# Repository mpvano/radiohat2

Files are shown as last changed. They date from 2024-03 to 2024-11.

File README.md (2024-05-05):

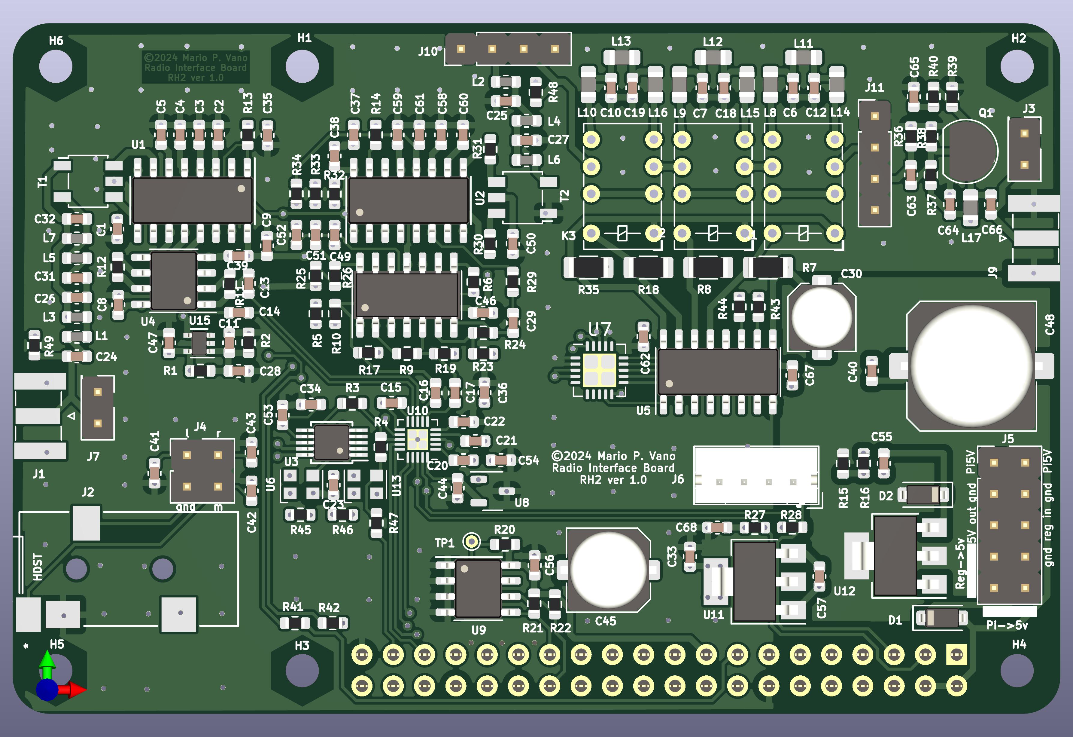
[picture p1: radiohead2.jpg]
3dView Title

# RadioHat 2

This is an early version of the folder full of files that need to be installed on a raspberry pi to allow experimentation with the RadioHat version 2.0 hardware.

When downloading and installing it, ensure that it is named "radiohat2" and that it is in your home directory, or some of the shell scripts it contains will not work properly. When downloaded as a .zip archive, it may result in a folder with the branch suffix "-main" that needs to be removed if you want to use the enclosed shell scripts.

One way to create the folder on a pi is to "cd" to the directory you want it to appear in and then clone the repository using git with the command: "git clone https://github.com/mpvano/radiohat2.git". This will allow you to use all the normal git functionality.

Note also that some of the files in "docs" are very out of date or incomplete. The "Getting Started Guides" refer to a much earlier configuration with different directories on the pi and procedures to set things up. They're presented here only to give some idea what to do. I'll be replacing them with more modern versions as I get to them. RadioHat is still very much a work in progress.

### The RadioHat hardware

Unlike RadioHat 1, RadioHat2 is an open source peripheral board for the Raspberry Pi in a form similar to an extended Pi "hat". Note that this board overhangs the pi USB and Ethernet connectors to match the dimensions of the Pi itself. This means it does not qualify as an official "HAT". It is intended to be a module containing many of the devices that are commonly needed to implement 3-30Mhz radio transmitters and receivers. It may also be used with other micro-controllers that support I2S if they are sufficiently powerful to handle the needed DSP operations.

It contains the following devices:<ol>
	<li>A Freescale SGTL5000 24 bit full duplex 48Khz I2S Audio codec with headset interface</li>
	<li>A Quadrature Switched Demodulator preceded by a 3-32Mhz Band Pass Filter</li>
	<li>A Quadrature Switched Modulator followed by a 32Mhz Low Pass Filter</li>
	<li>An Si5351 I2C controlled clock oscillator configured to provide quadrature clocks for them</li>
	<li>The EEPROM required by the Pi Foundation for "hat" devices</li>
	<li>Three relay controlled low pass filters intended for use after the Modulator to reduce harmonics before an external power amplifier.</li>
 	<li>A Class A Predriver to improve the Modulator drive capabilities and to compensate for filter losses.</li>
	<li>On board analog regulators to provide cleaner power from an optional external source</li>
</ol>

These devices are wired together in the usual way needed for HF radio operation with DSP provided by the Raspberry Pi. For typical operation as a radio transceiver you still need to provide a power amplifier with output filters and a transmit/receive switching mechanism. The usual output low pass filters are adequate for most uses as input filters for the receiver if the T/R switching is done in such a way that they remain inline with the receiver.

The repository now contains another board design of the same size in FAB/txfilters1 which implements a 5 filter LPF/VSWR Meter/TR Relay for stacking with the RadioHat board. Together with your choice of power amplifier this now allows a complete transceiver to be built easily.

Note that the real time clock option and Codec Line input output connection points that were present in Radiohat 1 have been removed. The Radiohat 1 board whose Kicad Folder is still in the repository remains software compatible with this board and although it is no longer under development it remains a viable option for those needing a true "hat" for the pi, or requiring a real time clock. 

There are two different Kicad folders available for RadioHat 2 - they differ primarily in that the one named "radiohat2_QFP32" is compatible with older 32 pin versions of the codec chip instead of the current 20 pin part. They will eventually be merged into a single version.

### Fabrication of boards
RadioHat2 is open sourced hardware licensed via an MIT license and the Gerber files, preliminary BOM and some draft documentation are all part of the project. 

Although a small production run was completed to provide a few boards for use by software developers, there is currently no way to obtain boards other than ordering them from a board manufacturer yourself - this is easy and inexpensive to do and the needed Gerber files are in this repository.

Note that this board is very compact and built with QFPn and 0603 components. It's not very practical to attempt assembly by hand. The board is intended to be reflow soldered after the components are placed on pads with the help of a front side solder paste screen.

### Software
The provided software is a collection of example and test programs that demonstrate operation of the board and allow testing and troubleshooting of it. They are only intended as a starting point for more serious software development. Experimental support is also provided for use with the popular "Quisk" Transceiver software as well.

This repository is newly setup and is still being tested. There may be some issues with missing files, etc. They are being addressed as quickly as possible.

### Dependencies
In general they are confined to the normal Raspberry Pi build tools, with the exception of ncurses and its development tools.

There is a simple installation described in the PDF file in the DOC folder.

Version 7 of Kicad or later is needed to modify the board design.

### Mailing list

There is a moderated mailing list for discussing this project at https://groups.io/g/RadioHat. This project's goal is develop radio equipment that requires a valid radio amateur operator's license to operate. Please include your valid station call sign in requests to join the list, and the nature of your interest in the project.

Mario Vano
AE0GL

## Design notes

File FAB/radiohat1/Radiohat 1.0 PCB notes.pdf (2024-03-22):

!.

$.
%.

!.

!.

$.

!.

Radiohat 1.0 PCB notes

ERRATA:
R23 and R24 references on Front Silk layer are swapped. F.Paste mask for U10 still has too much solder, especially center pad.
F.Paste mask for U3 still placing solder behind gull wings.
Need to add notes about unused pins on U10 (Remove from outline?)

BOM:
Y1 is now 25 MHz, not 27 MHz as shown on BOM and schematic Si5351 uses different variant with normal I2C address going forward

POSSIBLE ISSUES:
The front end gain may be too high again - Iʼm experiencing a little AM broadcast station bleed through. Consider going back to the 100 ohm input resistors on the receiver
For some uses, the narrow front end selectivity is a problem in adding a spectrum display. Consider some compromise values for the integrating capacitors and the op-amp bandwidth limiters in the receiver.
The 10 units built vary a bit more than they should in power output. I believe this is due to the component tolerances in the onboard low pass filter. The series resistance of the inductors seems to be a problem. Some of the them seem to have as much as 5 ohms series resistance and it all adds up.

SUGGESTIONS:
The Macom transformers no longer require the multifunction custom pad. It would be a good idea to go back to a standard pad layout and to remove them from the reflow assembly exclusion. Update manual with strong warnings - especially about J5, Y1 and U3 changes.

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
Always keep a shorting plug on J5 pins 1 and 2 when they are not actually being used to back-feed the Pi to prevent inadvertent shorts or use.
Renumber components?
Remove most of F.Silks references. Theyʼve become illegible Improve F.Fab layout for best readability and external Fab Zero grid and layout reference for Pick and Place
Clean up BOM for external Fab
Try moving 2.0V Analog Ref back to 2.5V if 3d order products allow it (R1)
Consider changing back to 20 pin U11 since 32 pin variant is now nearly unobtainable and the 20 pin one is back in stock in quantity. Better Yet: Switch to TLV320ADC3100IRGET!
THIS CHANGE MIGHT BE POSSIBLE WITH JUST A FOOTPRINT CHANGE.
Change to alternate S15351 suppliers and use part with standard base address.
Move R35 0 ohm jumper to Si5351 side to allow TP4 to be used as yellow wire point for modifications
Add some way to unbalance carrier to experiment with newer digital synthesis and other CW methods

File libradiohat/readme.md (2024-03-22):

# libradiohat - experimental version and tools #

## NEWS 1-Feb-2023 ##

Added experimental minimal Kenwood TS480 CAT control support to "transceiver.cpp" and new control-less GnuRadio USB conversion filter. Together with a SOCAT redirection command, ALSA loopback and Pulse Audio output capture this allows full proper operation of WSJT-X.

## NEWS 6-march-2022 ##

This directory has started to become a collecting point for a lot of new work. These files will eventually replace the legacy *RadioHat* installation completely. Many things in this folder are incompatible with older ways of doing things - in particular all programs now rely on the dynamic library and/or the new *transceiver* program.

Note also that everything looking for the codec now looks for it under a different ALSA device name! It is now known as *RadioHatCodec*. Programs still looking for *GenericStereoAudioCodec* or contractions of that name will need to be modified.

## introducing *libradiohat* ##

This is a refactored set of libraries for accessing the *RadioHat 1.0* hardware. It has many clean-ups and improvements and may now be built as a dynamic library.

This is primarily intended for use with *Bullseye*. It will also work on *Buster*, but other things may require fixup to go backwards!

This folder includes an improved and rewritten version of *pitrans*, called *transceiver* that uses the dynamic library for all *RadioHat* access.

There's  a primitive *make* file included that builds the library and test program targets but does not install the library. It has *install* and *remove* targets - which copy the library to */usr/lib/*, but they require using *sudo make install/remove* in a separate step.  For now, programs that use the library should still access it by absolute location to simplify development.

You'll also need to ensure that you've installed *libgpiod-dev* and *libncurses5-dev* before building. A *make clean* is probably also a good idea the first time.

Two other experimental programs are included that expect to find the libradiohat.so in *~/radiohat/libradiohat* for now.

Note that these programs probably will not work on *Buster* because the earlier version of Gnu Radio it supports is not file or program compatible with newer versions. The same is true of the *Quisk* it offers.

The earlier GRC programs in .~/radiohat should still be functional using *transceiver* instead of *pitrans* as they have not been disturbed by the new *GRC*. As usual ALSA device names may need touching up.

### Other Tools ###

In the *GRC* folder, *transceiver.grc / transceiver.py* is an experimental gnuradio flow graph that attempts to put all the things needed to experiment with and test *RadioHat* in one spot. It also includes some experimental PTT and VFO access from the flow graph. Unfortunately the ways needed to do this at the moment add a lot of overhead, and the program is unstable when run in the GRC environment. It seems to work OK by running the .py file, however. It also required Gnu Radio Version 3.8 or later.

Be aware, however, that the 1ms polling rate GRC uses for exporting variables as messages adds a lot of overhead and as a result this flow graph is occasional getting out of sync and losing alternate sideband rejection - usually if a lot of VFO tuning around is done at high speed. It's still fun and very useful for quick testing, but stick to the simpler flow graphs for serious measurements!

I'm also seeing a lot of crazy behaviour caused by *Pulse Audio* and the new *PipeWire* server. Neither one of them can be disabled any more and after a while they start distorting the IQ signals causing loss of functionality. Sometimes killing pulse audio (it will restart) will fix it - other times only a reboot will do it. Note that the "Bullseye" needs rebooting - not radiohat!  The new audio servers break Jack and prevent it's use with digital modes, as well.

### Experimental *quisk* interface ###

*QUISK* is a folder containg a hardware configuration file for Quisk. There are two copies present under different names. It's generally operating OK with the QUISK version in the Bullseye apt repository, but it's still very experimental. It almost certainly will not work under the version included with *Buster*. QUISK is very hard to configure and get working, but if you want to play with it, you may have some luck by moving the *radiohat* folder inside QUISK to the quisk configuration directory and setting quisk up as a radio of type "Softrock fixed" with one of these config files chosen.

All these programs are intended for use with the default Alsa device and I suggest using a usb plug-in dongle. This simplifies understanding them and eliminates problems with t/r switching the codec hardware audio paths. You can also use the built-in Pi headset sound or the HDMI sound for receiver and tone testing, since they both include dummy input devices.

We'll return to using the built-in headset jack and digital modes very soon, but for now these simplifications are speeding development a great deal and ensuring a solid foundation for the work to come.

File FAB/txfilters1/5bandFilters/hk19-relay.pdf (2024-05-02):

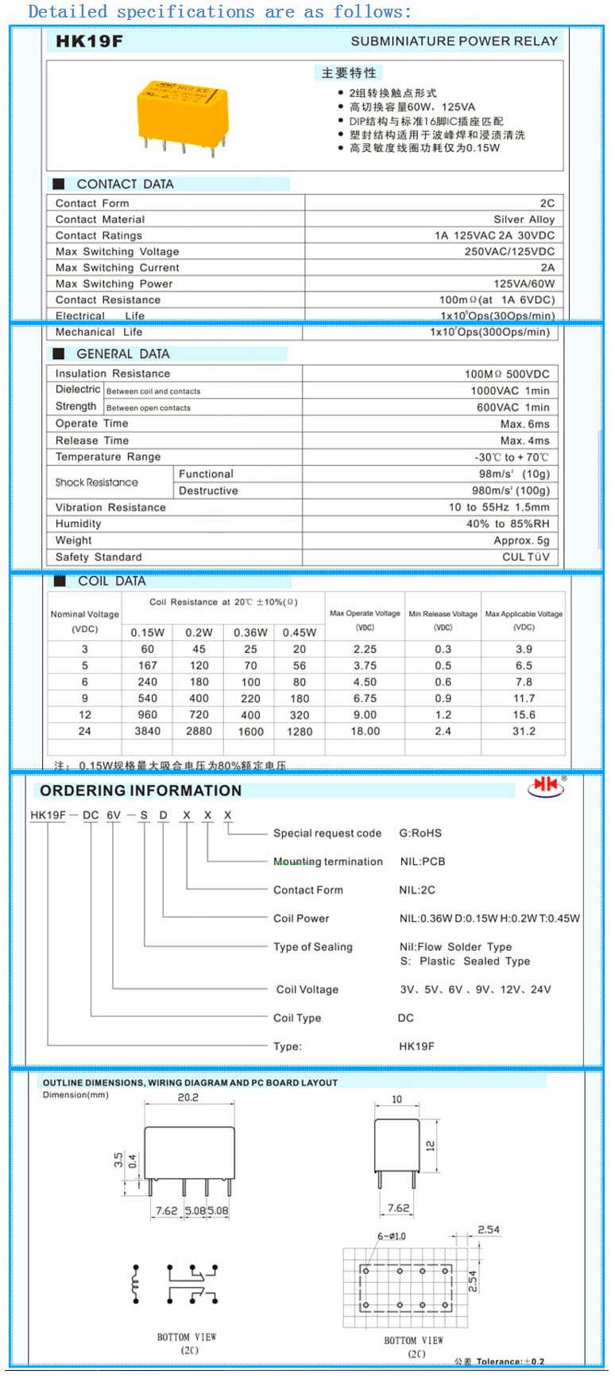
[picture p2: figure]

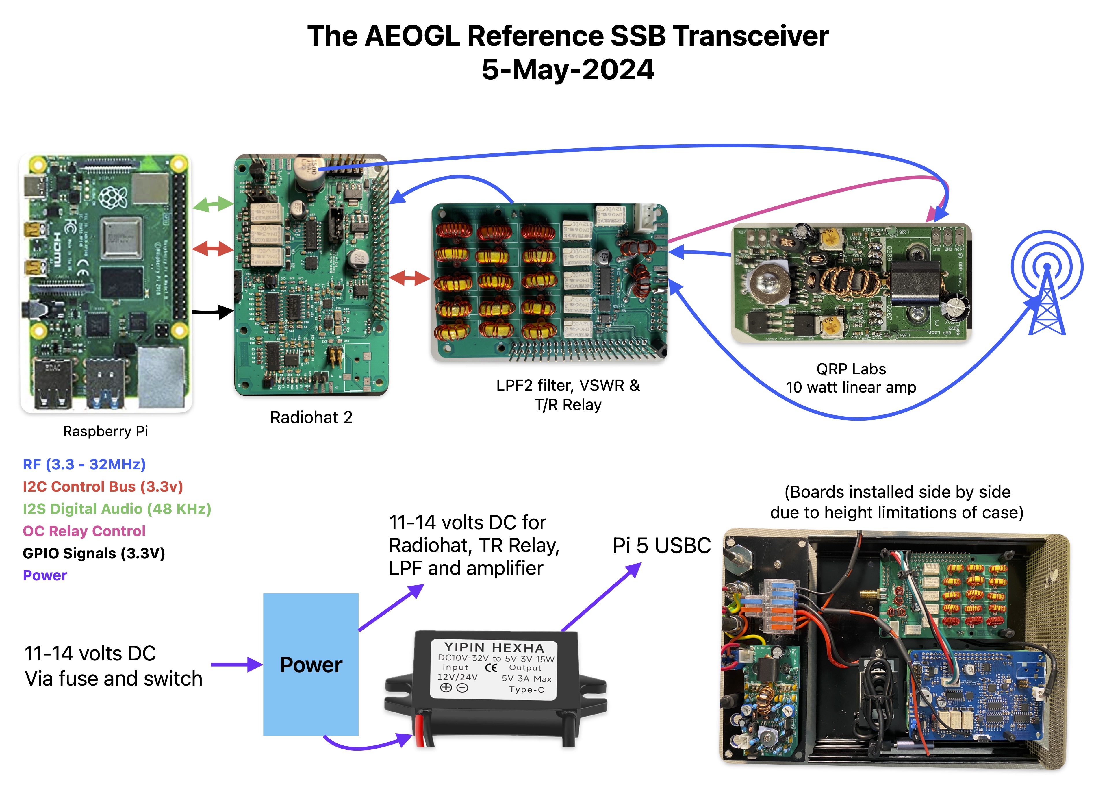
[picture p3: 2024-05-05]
Radiohat 2 Reference Transceiver.jpg

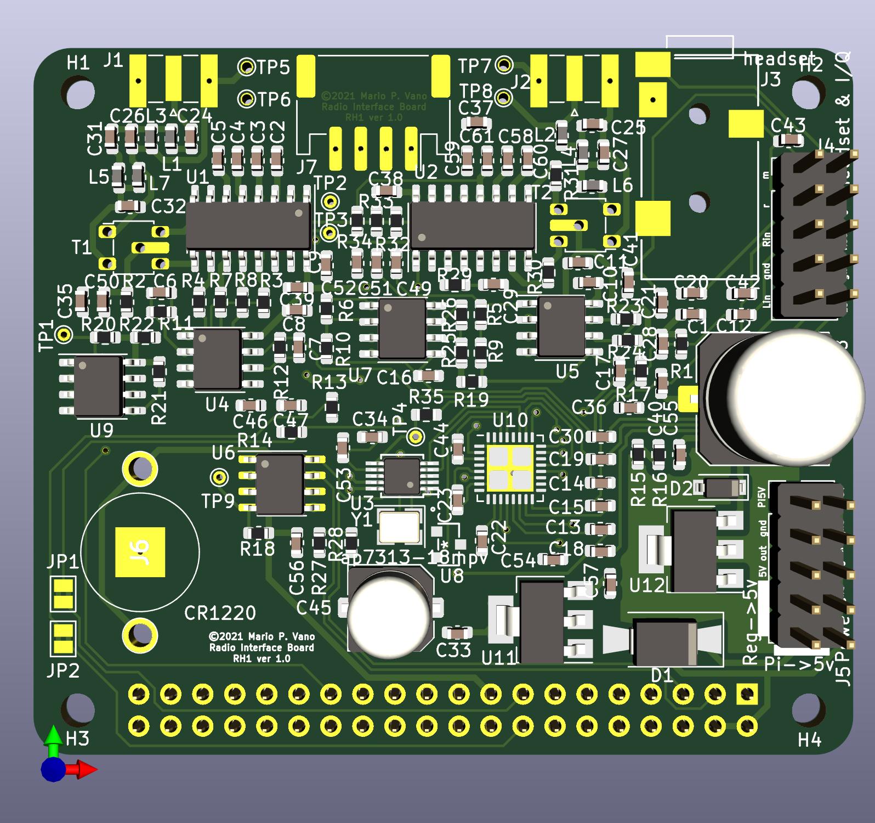
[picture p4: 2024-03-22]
FAB/radiohat1/radiohead3d.jpg

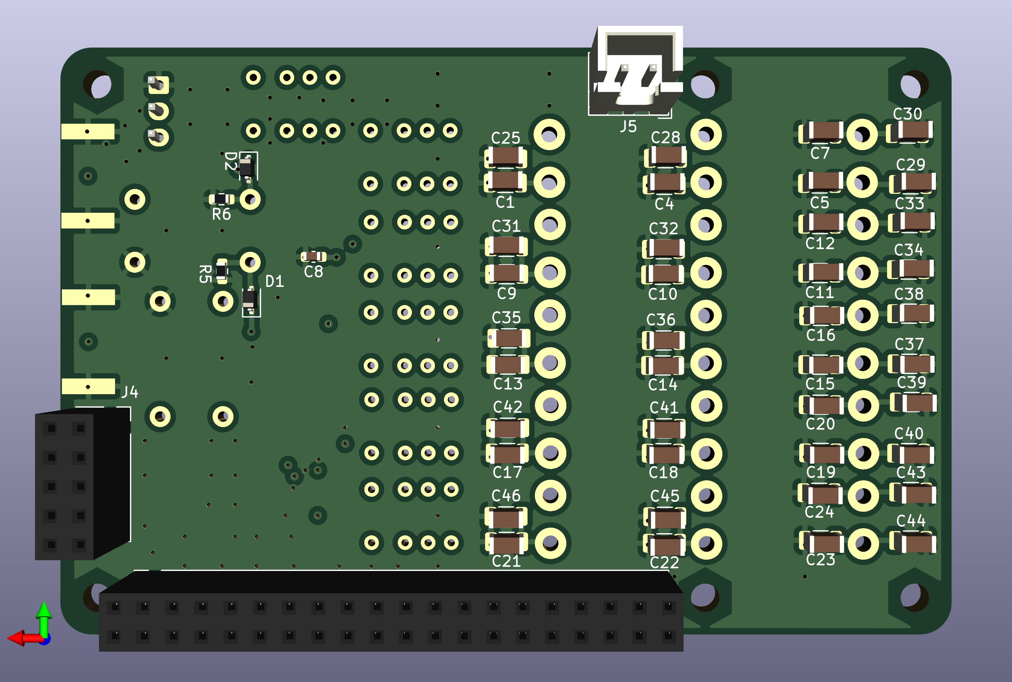
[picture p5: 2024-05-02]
FAB/txfilters1/txfilters3dB.jpg

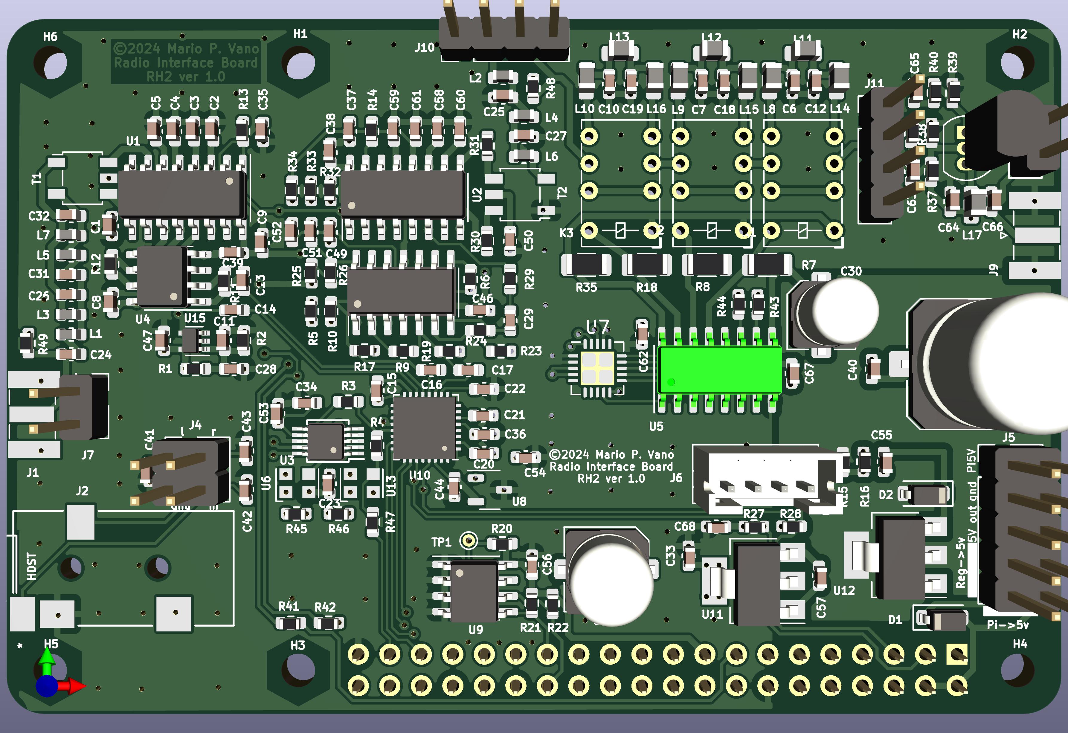
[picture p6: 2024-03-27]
FAB/radiohat2_QFP32/PCBA/radiohead.jpg

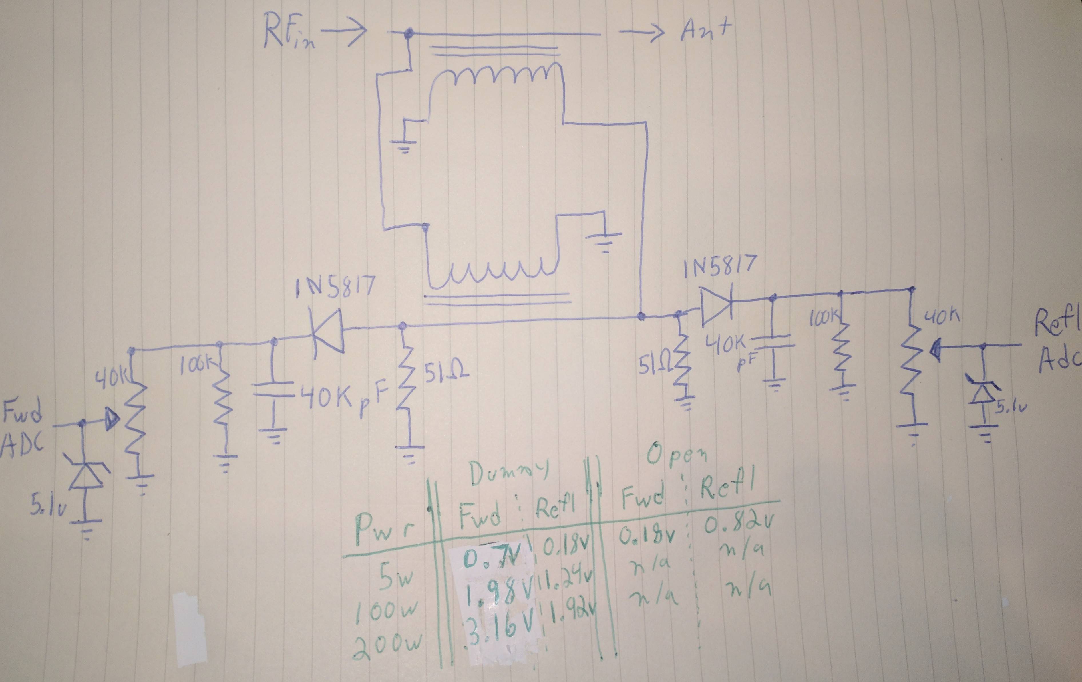
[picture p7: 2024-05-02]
FAB/txfilters1/datasheets/Stockton bridge/KCCug.jpg

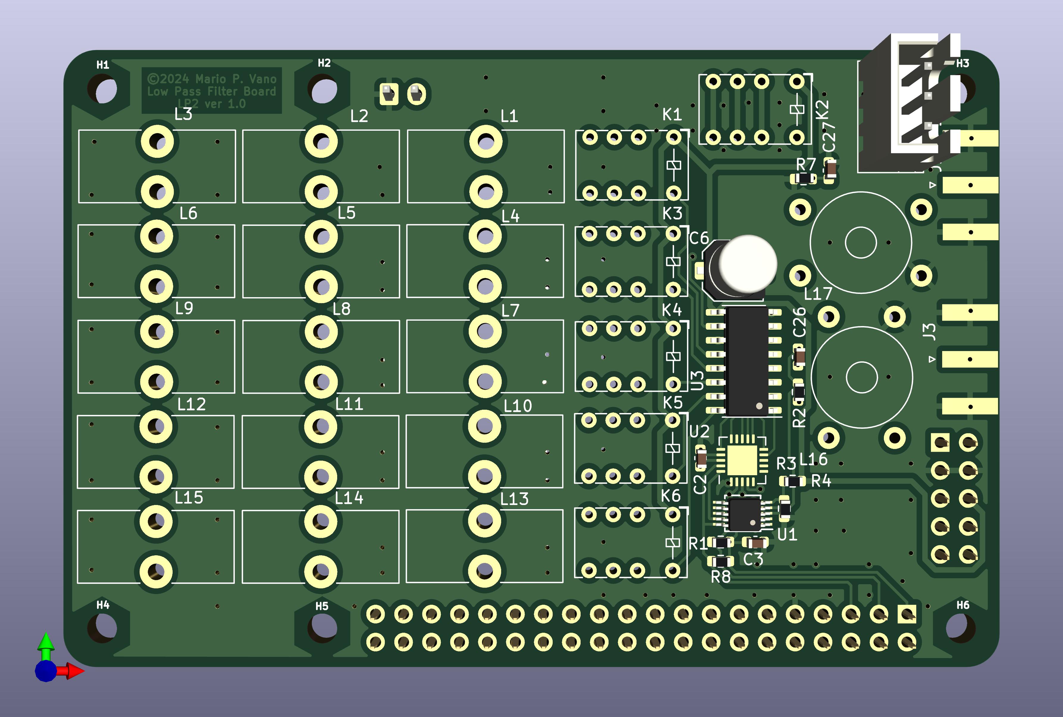
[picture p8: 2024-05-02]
FAB/txfilters1/txfilters3dF.jpg

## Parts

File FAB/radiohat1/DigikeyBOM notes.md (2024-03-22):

## Digikey RadioHat 1.0 BOM Notes ##
7-Mar-2022

### Disclaimer ###
This dump of my last BOM list on Digikey should be close to what is needed to build a *RadioHat 1.0* Board like the 10 I fabricated in January and Febuary 2022. You are responsible for carefully reviewing each item and locating it, or an equivalent part. I provide this only as an aid, not a definitive list! Due to the current parts shortages, it's very difficult to confirm what parts were actually bought here - they had to change with changing inventories.

Of course, you cannot simply place an order for this list. Many parts will not be available, others will have different minimum quantities. Some parts are simply no longer available and probably never will be from Digikey. It's only meant to be a starting point!

### Notes ###

1.	DigiKey's inventory record for C48 has an incorrect description for that part. It is incorrectly listed as *1.5µf* instead of *1.5mf* (for *millifarad*) or *1500µf*. The part number is correct and the correct part arrived. It's only the inventory record that is wrong. For decades, *mf* meant *microfarad*, but it no longer does.

2. The Top Silk Screen layer of the version 1.0 board has two swapped parts designators. R23 and R24's labels are reversed. The schematic, Fab layer screen and everything else are correct - only the silk screen (and 3D rendering of it) are incorrect.

3.	Some late changes in components to op-amp U4's feedback components resulted in too much gain and narrowing the bandwidth. The BOM still reflects the incorrect parts. I recommend reducing the feedback resistors R11 and R12 from 10k to 2.4k. This will allow an rf input level of about -16dbm before clipping occurs.

	Instead of adjusting the bandwidth to the old goal of approximately 8khz, most people seem to prefer operating this stage with less selectivity to allow spectrum display graphs of the full audio bandwidth (+-19khz or so before the ADC's filtering cuts in). Removing C6 and C7 completely seems to achieve this goal.

	With some very high performance op-amps, it may be desirable to prevent the bandwidth from exceeding this range, and if so values of 200pf can be used for C6 and C7. Some experimentation in this area is probably worthwhile.

	The QSD itself still has some deliberate roll-off due to the high values of capacitors used for C2, C3, C4, and C5. It has been suggested that values as low as .1µfd may be more appropriate, but I have not tried that substitution.

4.	Be cautious about the si5351 (U3). The original part I was using was all I could obtain and the part number shown in the original BOM, while correct, is for a part with custom programming to give it a *different I2C address*. All these parts were removed from boards and no more boards should be built using them so that the same software builds will work on everything! The *Digikey* BOM reflects the standard version of the part (but of course it's not available!) use the MS5351 instead.

5. The original *RadioHat* operated with a crystal frequency of 27Mhz. All current boards have had the crystal replaced with the one shown in the *Digikey* BOM (or another 25Mhz equivalent). No more 27Mhz boards should ever be built!

6. R35 is intended to be a zero ohm jumper. It turns out that's a hard value to obtain! The current parts list shows it as 1 ohm and that works fine (Or you can use a piece of wire).

7. J7, the JST PH-4 connector used for *STEMMA* compatibility is no longer available in the form used to build the first 10 boards. A compatible connector is available from Adafruit Industries and is stocked by many suppliers including DigiKey. That is what is shown in this BOM. It's only available in packages of 10 connectors at a time, however!

8. There are many variant GPIO connectors (J8). I recommend making sure the ones you buy have square pins, or you may have contact problems if you wish to connect the popular *dupont* female connectors with them. For some uses, taller connectors may be needed to clear the heat sinks on some cases (or just to isolate the board from heat).

9.	Due to costs and parts availability, I recommend building boards without the clock calendar chip at this time.

10. It has become very clear to me that boards should not be built with the SMA connectors unless they are going to be used! They are a nuisance in may cases due to their protruberance from the side of the board. Only install them if you plan to use them!

11. The eeprom (U9) is not actually required or used at this time. It is needed, and needs to be programmed if you intend to sell boards and call them "hats". There are other plug-and-play advantages it can provide, but these parts have become very difficult to find at this time and can be added later if needed!

12. There are obviously many replacements available for J4 and J5. Obtaining *brand-name* headers of this type can be very difficult and expensive. I suggest ensuring that the pins are of high quality, square, and long enough to provide low contact resistance - especially for J5 - which is used to carry power.

Mario Vano

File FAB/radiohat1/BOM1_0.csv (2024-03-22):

Reference | Quantity | Value | Footprint | Datasheet | Description | Height | Manufacturer_Name | Manufacturer_Part_Number | Mouser Part Number | Mouser Price/Stock
C1 C50 | 2 | 10n | Capacitor_SMD:C_0603_1608Metric | ~
C12 C13 C14 C15 C16 C17 C18 C19 C20 C21 C30 C44 | 12 | 1m | Capacitor_SMD:C_0603_1608Metric | ~
C8 C9 C10 C22 C23 C33 C34 C35 C36 C37 C38 C39 C46 C47 C54 C56 C57 | 17 | 100n | Capacitor_SMD:C_0603_1608Metric | ~
C25 C27 | 2 | 130p | Capacitor_SMD:C_0603_1608Metric | ~
C26 C32 | 2 | 180p | Capacitor_SMD:C_0603_1608Metric | ~
C11 C28 C40 C53 | 4 | 10m | Capacitor_SMD:C_0603_1608Metric | ~
C24 C31 | 2 | 620p | Capacitor_SMD:C_0603_1608Metric | ~
C41 C42 C43 | 3 | 1n | Capacitor_SMD:C_0603_1608Metric | ~
C45 | 1 | 100m | Capacitor_SMD:C_Elec_6.3x5.4 | ~
C48 | 1 | 1500m | Capacitor_SMD:C_Elec_10x10.2 | ~
C29 C49 C51 C52 | 4 | 10u | Capacitor_SMD:C_0603_1608Metric | ~
C2 C3 C4 C5 | 4 | 470n | Capacitor_SMD:C_0603_1608Metric | ~
C55 | 1 | 100n 25V | Capacitor_SMD:C_0603_1608Metric | ~
C58 C59 C60 C61 | 4 | 22n | Capacitor_SMD:C_0603_1608Metric | ~
C6 C7 | 2 | 4.7n | Capacitor_SMD:C_0603_1608Metric | ~
D1 | 1 | MBRA340T3G | radiohead:D_SMA-SMB_Universal_Handsoldering | https://www.onsemi.com/pub/Collateral/MBRA340T3-D.PDF
D2 | 1 | MBR0520LT | Diode_SMD:D_SOD-123 | http://www.onsemi.com/pub_link/Collateral/MBR0520LT1-D.PDF
H1 H2 H3 H4 | 4 | 2.5mm | MountingHole:MountingHole_2.7mm_M2.5 | ~
J1 | 1 | HF IN | Connector_Coaxial:SMA_Samtec_SMA-J-P-X-ST-EM1_EdgeMount | ~
J2 | 1 | HF OUT | Connector_Coaxial:SMA_Samtec_SMA-J-P-X-ST-EM1_EdgeMount | ~
J3 | 1 | headset | Connector_Audio:SJ-43514TS-SMT
J4 | 1 | Headset & I/Q | Connector_PinHeader_2.54mm:PinHeader_2x05_P2.54mm_Vertical | ~
J5 | 1 | Power | Connector_PinHeader_2.54mm:PinHeader_2x05_P2.54mm_Vertical | ~
J6 | 1 | CR1220 | 2895:2895 | https://www.mouser.com/datasheet/2/215/Keystone_Electronics_04082019_2895-1551354.pdf | Coin Cell Battery Holders CR1220 COIN CELL THM RETAINER | 2.95 | Keystone Electronics | 2895 | 534-2895 | https://www.mouser.co.uk/ProductDetail/Keystone-Electronics/2895/?qs=u16ybLDytRYxJrEfvGnUaA%3D%3D
J7 | 1 | I2C | Connector_JST:JST_PH_S4B-PH-SM4-TB_1x04-1MP_P2.00mm_Horizontal | ~
J8 | 1 | Raspberry Pi GPIO | Connector_PinSocket_2.54mm:PinSocket_2x20_P2.54mm_Vertical | ~
JP1 | 1 | /TX | Jumper:SolderJumper-2_P1.3mm_Bridged2Bar_Pad1.0x1.5mm | ~
JP2 | 1 | /RX | Jumper:SolderJumper-2_P1.3mm_Bridged2Bar_Pad1.0x1.5mm | ~
L1 L2 L5 L6 | 4 | 470n | Inductor_SMD:L_0603_1608Metric | ~
L3 L7 | 2 | 1µ5 | Inductor_SMD:L_0603_1608Metric | ~
L4 | 1 | 560n | Inductor_SMD:L_0603_1608Metric | ~
R1 | 1 | 300 | Resistor_SMD:R_0603_1608Metric | ~
R9 R10 R11 R12 R13 R14 R17 R18 R19 R23 R25 R27 R28 | 13 | 10k | Resistor_SMD:R_0603_1608Metric | ~
R15 | 1 | 333r | Resistor_SMD:R_0603_1608Metric | ~
R2 | 1 | 200 | Resistor_SMD:R_0603_1608Metric | ~
R16 R20 | 2 | 1k | Resistor_SMD:R_0603_1608Metric | ~
R21 R22 | 2 | 3k9 | Resistor_SMD:R_0603_1608Metric | ~
R24 R26 | 2 | 20k | Resistor_SMD:R_0603_1608Metric | ~
R3 R4 R7 R8 | 4 | 50 | Resistor_SMD:R_0603_1608Metric | ~
R29 R30 R31 R32 R33 R34 | 6 | 50R | Resistor_SMD:R_0603_1608Metric | ~
R35 | 1 | 0 | Resistor_SMD:R_0603_1608Metric | ~
R5 R6 | 2 | 30k | Resistor_SMD:R_0603_1608Metric | ~
T1 T2 | 2 | MABAES0031 | radiohead:Transformer_MACOM_MABAES00031CT-HYBRID | https://cdn.macom.com/datasheets/MABAES0060.pdf | Audio Transformers / Signal Transformers .3-200MHz IL 1.5dB Impedance Ratio 1:4 | 3.8 | MACOM | MABAES0031CT | 1464-MABAES0031-CT
TP1 | 1 | /Write | TestPoint:TestPoint_THTPad_D1.0mm_Drill0.5mm | ~
TP2 | 1 | I | TestPoint:TestPoint_THTPad_D1.0mm_Drill0.5mm | ~
TP3 | 1 | Q | TestPoint:TestPoint_THTPad_D1.0mm_Drill0.5mm | ~
TP4 | 1 | MCLK | TestPoint:TestPoint_THTPad_D1.0mm_Drill0.5mm | ~
TP5 | 1 | -in | TestPoint:TestPoint_THTPad_D1.0mm_Drill0.5mm | ~
TP6 | 1 | +in | TestPoint:TestPoint_THTPad_D1.0mm_Drill0.5mm | ~
TP7 | 1 | -out | TestPoint:TestPoint_THTPad_D1.0mm_Drill0.5mm | ~
TP8 | 1 | +out | TestPoint:TestPoint_THTPad_D1.0mm_Drill0.5mm | ~
TP9 | 1 | RESET | TestPoint:TestPoint_THTPad_D1.0mm_Drill0.5mm | ~
U10 | 1 | SGTL5000XNAA3 | Package_DFN_QFN:QFN-32-1EP_5x5mm_P0.5mm_EP3.7x3.7mm | https://www.nxp.com/docs/en/data-sheet/SGTL5000.pdf
U11 | 1 | LD1117S33TR_SOT223 | Package_TO_SOT_SMD:SOT-223-3_TabPin2 | http://www.st.com/st-web-ui/static/active/en/resource/technical/document/datasheet/CD00000544.pdf
U12 | 1 | LM317_SOT-223 | Package_TO_SOT_SMD:SOT-223-3_TabPin2 | http://www.ti.com/lit/ds/symlink/lm317.pdf
U1 U2 | 2 | SN74CBT3253 | Package_SO:SOIC-16_3.9x9.9mm_P1.27mm | http://www.ti.com/lit/gpn/sn74cbt3253
U3 | 1 | Si5351A-B-GT | Package_SO:MSOP-10_3x3mm_P0.5mm | https://www.silabs.com/documents/public/data-sheets/Si5351-B.pdf
U4 | 1 | LM4562 | Package_SO:SOIC-8_3.9x4.9mm_P1.27mm | http://www.ti.com/lit/ds/symlink/lm4562.pdf
U5 U7 | 2 | TLV2462CDR | Package_SO:SOIC-8_3.9x4.9mm_P1.27mm | http://www.ti.com/lit/ds/symlink/lm358.pdf
U6 | 1 | DS3231MZ | Package_SO:SOIC-8_3.9x4.9mm_P1.27mm | http://datasheets.maximintegrated.com/en/ds/DS3231M.pdf
U8 | 1 | ap7313-18mpv | ul_AP731318SAG7:AP7313-18SAG-7
U9 | 1 | CAT24C128 | Package_SO:SOIC-8_3.9x4.9mm_P1.27mm | https://www.onsemi.com/pub/Collateral/CAT24C128-D.PDF
Y1 | 1 | 27Mhz | Crystal:Crystal_SMD_Abracon_ABM8G-4Pin_3.2x2.5mm | ~

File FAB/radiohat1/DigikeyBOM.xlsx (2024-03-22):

Country of Origin may be different at time of shipment.
The HTSUS and ECCN information shown is for informational purposes only and is not a representation or warranty as to the accuracy or reliability of these classifications. All information is provided "as is" and is subject to change without notice. Any use made of the information provided is without recourse to Digi-Key and at the user's risk.
Index | Manufacturer Part Number | Manufacturer Name | Description | Availability | Stock Status | Attrition % | Requested Quantity 1 | Pack Quantity 1 | Pack Type 1 | Digi-Key Part Number 1 | Unit Price 1 | Extended Price 1 | Minimum Order Quantity 1 | Customer Reference | Requested Part Number | Lead Weeks | Datasheet | Reference Designator | US Import Tariff | Note | Part Status | RoHS Status | ECCN | HTSUS | Country of Origin | Environmental Information | Original Part numbers | Image
1 | C0603C103K9RAC7867 | KEMET | CAP CER 10000PF 6.3V X7R 0603 | 56,312 | In Stock |  | 2 | 2 | Cut Tape (CT) | 399-C0603C103K9RAC7867CT-ND | 0.12000 | $0.24 | 1 |  | 399-C0603C103K9RAC7867CT-ND | 15 | https://api.kemet.com/component-edge/download/datasheet/C0603C103K9RACTU.pdf | C1 C50 | May apply on shipments to the U.S. | CAP CER 10000PF 6.3V | Active | ROHS3 Compliant | EAR99 | 8532.24.0020 | Taiwan |  | 399-C0603C103K9RAC7867CT-ND | //media.digikey.com/Renders/Kemet%20Renders/0603-(1608-Metric)-1,60x0,80x0,87mm.jpg
2 | CGB3B3X7R0J105K055AB | TDK Corporation | CAP CER 1UF 6.3V X7R 0603 | 11,634 | In Stock |  | 12 | 12 | Cut Tape (CT) | 445-13246-1-ND | 0.12400 | $1.49 | 1 |  | 445-13246-1-ND | 28 |  | C12 C13 C14 C15 C16 C17 C18 C19 C20 C21 C30 C44 | N/A | CAP CER 1UF 6.3V X7R 0603 | Not For New Designs | ROHS3 Compliant | EAR99 | 8532.24.0020 | Japan | https://product.tdk.com/en/environment/index.html|https://product.tdk.com/system/files/dam/doc/product/capacitor/ceramic/mlcc/rohs/mlccrohs_commercial_lowprofile_en.pdf | 445-13246-1-ND | //media.digikey.com/Renders/TDK%20Renders/CGB%20Series%200603.jpg
3 | C0603C104K4RAC7867 | KEMET | CAP CER 0.1UF 16V X7R 0603 | 5,975,227 | In Stock |  | 17 | 17 | Cut Tape (CT) | 399-C0603C104K4RAC7867CT-ND | 0.07900 | $1.34 | 1 |  | 399-C0603C104K4RAC7867CT-ND | 15 | https://api.kemet.com/component-edge/download/datasheet/C0603C104K4RACTU.pdf | C8 C9 C10 C22 C23 C33 C34 C35 C36 C37 C38 C39 C46 C47 C54 C56 C57 | May apply on shipments to the U.S. |  | Active | ROHS3 Compliant | EAR99 | 8532.24.0020 | Taiwan |  | 399-C0603C104K4RAC7867CT-ND | //media.digikey.com/Renders/Kemet%20Renders/0603-(1608-Metric)-1,60x0,80x0,87mm.jpg
4 | 0603N131J500CT | Walsin Technology Corporation | CAP CER 130PF 50V C0G/NP0 0603 | 5,053 | In Stock |  | 2 | 2 | Cut Tape (CT) | 1292-1484-1-ND | 0.10000 | $0.20 | 1 |  | 1292-1484-1-ND | 32 | http://www.passivecomponent.com/wp-content/uploads/datasheet/WTC_MLCC_General_Purpose.pdf | C25 C27 | N/A | CAP CER 130PF 50V C0G/NP0 0603 | Active | ROHS3 Compliant | EAR99 | 8532.24.0020 | Taiwan | http://www.passivecomponent.com/download/reach_rohs_compliance_declaration-2/?wpdmdl=1343 | 1292-1484-1-ND | //media.digikey.com/Renders/Walsin%20Tech/MLCC-0603;;1,6x0,8x0,85.JPG
5 | VJ0603D181JXJQJHT | Vishay Vitramon | CAP CER 180 PF 16V C0G 0603 | 1,800 | In Stock |  | 2 | 2 | Cut Tape (CT) | 720-VJ0603D181JXJQJHTCT-ND | 0.46000 | $0.92 | 1 |  | 720-VJ0603D181JXJQJHTCT-ND | 39 | https://www.vishay.com/docs/45239/vjhifreqht.pdf | C26 C32 | N/A | CAP CER 180PF 16V | Active | ROHS3 Compliant | EAR99 | 8532.24.0020 | Israel |  | 720-VJ0603D181JXJQJHTCT-ND | //media.digikey.com/Photos/Vishay%20Vitramon/MLCC-0603.jpg
6 | CL10A106KQ8NNNC | Samsung Electro-Mechanics | CAP CER 10UF 6.3V X5R 0603 | 0 | Normally Stocking |  | 8 | 8 | Cut Tape (CT) | 1276-1038-1-ND | 0.14000 | $1.12 | 1 |  | 1276-1038-1-ND | 28 | //media.digikey.com/pdf/Data%20Sheets/Samsung%20PDFs/CL10A106KQ8NNNC_Spec.pdf | C11 C28 C40 C53 C29 C49 C51 C52 | N/A | CAP CER 10UF 6.3V X5R 0603 | Active | ROHS3 Compliant | EAR99 | 8532.24.0020 | China | https://www.samsungsem.com/global/support/certificate/product-stewardship.do|https://www.samsungsem.com/files/fileDown.do?key=ed1dfdfa-645e-4252-b707-17f9b1502dd1 | 1276-1038-1-ND | //media.digikey.com/Renders/Samsung%20Electro-Mechanics%20America/Ceramic-Capacitor-CL-Series.jpg
7 | 0603N621J500CT | Walsin Technology Corporation | CAP CER 620PF 50V C0G/NP0 0603 | 2,755 | In Stock |  | 2 | 2 | Cut Tape (CT) | 1292-1540-1-ND | 0.11000 | $0.22 | 1 |  | 1292-1540-1-ND | 32 | http://www.passivecomponent.com/wp-content/uploads/datasheet/WTC_MLCC_General_Purpose.pdf | C24 C31 | May apply on shipments to the U.S. | CAP CER 620PF 50V C0G/NP0 0603 | Active | ROHS3 Compliant | EAR99 | 8532.24.0020 | Taiwan | http://www.passivecomponent.com/download/reach_rohs_compliance_declaration-2/?wpdmdl=1343 | 1292-1540-1-ND | //media.digikey.com/Renders/Walsin%20Tech/MLCC-0603;;1,6x0,8x0,85.JPG
8 | 0603B102K500CT | Walsin Technology Corporation | CAP CER 1000PF 50V X7R 0603 | 2,236,155 | In Stock |  | 3 | 3 | Cut Tape (CT) | 1292-1380-1-ND | 0.10000 | $0.30 | 1 |  | 1292-1380-1-ND | 48 | http://www.passivecomponent.com/wp-content/uploads/datasheet/WTC_MLCC_General_Purpose.pdf | C41 C42 C43 | N/A |  | Active | ROHS3 Compliant | EAR99 | 8532.24.0020 | Taiwan | http://www.passivecomponent.com/download/reach_rohs_compliance_declaration-2/?wpdmdl=1343 | 1292-1380-1-ND | //media.digikey.com/Renders/Walsin%20Tech/MLCC-0603;;1,6x0,8x0,85.JPG
9 | 10SEV100M6.3X5.5 | Rubycon | CAP ALUM 100UF 20% 10V SMD | 0 | Normally Stocking |  | 1 | 1 | Cut Tape (CT) | 1189-2934-1-ND | 0.51000 | $0.51 | 1 |  | 1189-2934-1-ND | 25 | https://www.rubycon.co.jp/wp-content/uploads/catalog-aluminum/SEV.pdf | C45 | N/A | CAP ALUM 100UF 20% 10V SMD | Active | ROHS3 Compliant | EAR99 | 8532.22.0020 | Japan |  | 1189-2934-1-ND | //media.digikey.com/Photos/Rubycon/SEV%20SERIES%206.3x5.5mm.JPG
10 | EEE-FN0J152P | Panasonic Electronic Components | CAP ALUM 1.5UF 20% 6.3V SMD | 0 | Normally Stocking |  | 1 | 1 | Cut Tape (CT) | 10-EEE-FN0J152PCT-ND | 1.02000 | $1.02 | 1 |  | 10-EEE-FN0J152PCT-ND | 50 | https://b2b-api.panasonic.eu/file_stream/pids/fileversion/9127 | C48 | N/A | CAP ALUM 1.5UF 20% 6.3V SMD | Active | ROHS3 Compliant | EAR99 | 8532.22.0020 | Malaysia |  | 10-EEE-FN0J152PCT-ND | //media.digikey.com/Photos/Panasonic%20Elect%20Works%20Photos/MFG_EEE-FN-Series.jpg
11 | C0603C474K8RAC7867 | KEMET | CAP CER 0.47UF 10V X7R 0603 | 32,047 | In Stock |  | 4 | 4 | Cut Tape (CT) | 399-C0603C474K8RAC7867CT-ND | 0.50000 | $2.00 | 1 |  | 399-C0603C474K8RAC7867CT-ND | 53 | https://api.kemet.com/component-edge/download/datasheet/C0603C474K8RACTU.pdf | C2 C3 C4 C5 | N/A | CAP CER 0.47µf 10V | Active | ROHS3 Compliant | EAR99 | 8532.24.0020 | Mexico |  | 399-C0603C474K8RAC7867CT-ND | //media.digikey.com/Renders/Kemet%20Renders/0603-(1608-Metric)-1,60x0,80x0,87mm.jpg
12 | C0603C104K3RAC7082 | KEMET | CAP CER 0.1UF 25V X7R 0603 | 27,665 | In Stock |  | 1 | 1 | Cut Tape (CT) | 399-C0603C104K3RAC7082CT-ND | 0.11000 | $0.11 | 1 |  | 399-C0603C104K3RAC7082CT-ND | 15 | https://api.kemet.com/component-edge/download/datasheet/C0603C104K3RAC7082.pdf | C55 | May apply on shipments to the U.S. | CAP CER 0.1UF 25V X7R 0603 | Active | ROHS3 Compliant | EAR99 | 8532.24.0020 | Taiwan |  | 399-C0603C104K3RAC7082CT-ND | //media.digikey.com/Renders/Kemet%20Renders/0603-(1608-Metric)-1,60x0,80x0,87mm.jpg
13 | C0603C224K9RAC7867 | KEMET | CAP CER 0.22UF 6.3V X7R 0603 | 34,130 | In Stock |  | 4 | 4 | Cut Tape (CT) | 399-C0603C224K9RAC7867CT-ND | 0.10000 | $0.40 | 1 |  | 399-C0603C224K9RAC7867CT-ND | 15 | https://api.kemet.com/component-edge/download/datasheet/C0603C224K9RACTU.pdf | C58 C59 C60 C61 | May apply on shipments to the U.S. | CAP CER 0.22µf 6.3V | Active | ROHS3 Compliant | EAR99 | 8532.24.0020 | China |  | 399-C0603C224K9RAC7867CT-ND | //media.digikey.com/Renders/Kemet%20Renders/0603-(1608-Metric)-1,60x0,80x0,87mm.jpg
14 | 0603B472K500CT | Walsin Technology Corporation | CAP CER 4700PF 50V X7R 0603 | 303,759 | In Stock |  | 2 | 2 | Cut Tape (CT) | 1292-1443-1-ND | 0.10000 | $0.20 | 1 |  | 1292-1443-1-ND | 32 | http://www.passivecomponent.com/wp-content/uploads/datasheet/WTC_MLCC_General_Purpose.pdf | C6 C7 | May apply on shipments to the U.S. | CAP CER 4700PF 50V X7R 0603 | Active | ROHS3 Compliant | EAR99 | 8532.24.0020 | Taiwan | http://www.passivecomponent.com/download/reach_rohs_compliance_declaration-2/?wpdmdl=1343 | 1292-1443-1-ND | //media.digikey.com/Renders/Walsin%20Tech/MLCC-0603;;1,6x0,8x0,85.JPG
15 | CDBA340-HF | Comchip Technology | DIODE SCHOTTKY 40V 3A DO214AC | 127 | In Stock |  | 1 | 1 | Cut Tape (CT) | 641-1748-1-ND | 0.37000 | $0.37 | 1 |  | 641-1748-1-ND | 32 | //media.digikey.com/pdf/Data%20Sheets/Comchip%20PDFs/CDBA340-HF_Thru_CDBA3100-HF_RevB.pdf | D1 | N/A | DIODE SCHOTTKY 40V 3A DO214AC | Active | ROHS3 Compliant | EAR99 | 8541.10.0080 | Taiwan | https://www.comchiptech.com/admin/files/tech/213_20201006093628.pdf | 641-1748-1-ND | //media.digikey.com/photos/Comchip%20Tech%20Photos/641-DO-214AC.jpg
16 | MBR0520L-TP | Micro Commercial Co | DIODE SCHOTTKY 20V 500MA SOD123 | 137,167 | In Stock |  | 1 | 1 | Cut Tape (CT) | MBR0520L-TPMSCT-ND | 0.52000 | $0.52 | 1 |  | MBR0520L-TPMSCT-ND | 36 | https://www.mccsemi.com/pdf/Products/MBR0520L-MBR0540L(SOD-123).pdf | D2 | May apply on shipments to the U.S. | DIODE SCHOTTKY 20V 500MA SOD123 | Active | ROHS3 Compliant | EAR99 | 8541.10.0070 | China | https://www.mccsemi.com/pdf/pbfree/Certification%20of%20RoHS%20Compliance.pdf|https://www.mccsemi.com/pdf/pbfree/Certification%20of%20Compliance%20of%20CaliforniaProposition65.pdf|https://www.mccsemi.com/pdf/pbfree/Certification%20of%20REACH%20Compliance.pdf | MBR0520L-TPMSCT-ND | //media.digikey.com/Renders/Micro%20Commercial%20Renders/SOD-123.jpg
17 | SJ-43514-SMT-TR | CUI Devices | CONN JACK 4COND 3.5MM SMD R/A | 84,832 | In Stock |  | 1 | 1 | Cut Tape (CT) | CP-43514SJCT-ND | 1.20000 | $1.20 | 1 |  | CP-43514SJCT-ND | 14 | https://www.cuidevices.com/product/resource/sj-4351x-smt.pdf | J3 | May apply on shipments to the U.S. | CONN JACK 4COND 3.5MM SMD R/A | Active | ROHS3 Compliant | EAR99 | 8536.69.4040 | Hong Kong | https://www.cuidevices.com/product/resource/material-compliance/sj-4351x-smt-series | CP-43514SJCT-ND | //media.digikey.com/photos/CUI%20Photos/SJ-43514-SMT%20.jpg
18 | 61301021121 | Würth Elektronik | CONN HEADER VERT 10POS 2.54MM | 5,452 | In Stock |  | 2 | 2 | Bag | 732-2672-ND | 1.08000 | $2.16 | 1 |  | 732-2672-ND | 23 | https://www.we-online.com/katalog/datasheet/6130xx21121.pdf | J4 J5 | N/A | CONN HEADER VERT 10POS 2.54MM | Active | ROHS3 Compliant | EAR99 | 8536.69.4040 | Taiwan | https://media.digikey.com/pdf/Other%20Related%20Documents/Wurth/Certificate_of_Compliance_ROHS.pdf | 732-2672-ND | //media.digikey.com/Photos/Wurth%20Electronics%20Photos/61301021121.jpg
19 | 2895 | Keystone Electronics | BATT RETAIN COIN 1 CELL PC PIN | 17,088 | In Stock |  | 1 | 1 | Bulk | 36-2895-ND | 0.66000 | $0.66 | 1 |  | 36-2895-ND | 12 | http://www.keystoneelectronics.net/ENG._DEPT/WEB_ORACLE/PDF/PDF%20CAT%20NO%20DRAWINGS/2000-2999/2895.PDF | J6 | May apply on shipments to the U.S. | BATT RETAIN COIN 1 CELL PC PIN | Active | ROHS3 Compliant | EAR99 | 8536.69.4040 | China | https://www.keyelco.com/userAssets/file/reach.pdf|http://www.keyelco.com/userAssets/file/RoHS_Statement.pdf | 36-2895-ND | //media.digikey.com/Photos/Keystone%20Elect%20Photos/2895.jpg
20 | 4392 | Adafruit Industries LLC | JST PH 4-PIN CONN 10-PACK STEMMA |  | Non-Stock |  | 1 | 1 | Bulk | 1528-4392-ND | 3.50000 | $3.50 | 1 |  | 1528-4392-ND | 2 | https://cdn-shop.adafruit.com/product-files/4392/4392_C13927-001_CW2001-04T-H01-BD-A.PDF | J7 | N/A | JST PH4 4-PIN CONN STEMMA ONLY IN 10 PACK! | Active | ROHS3 Compliant | EAR99 | 8536.69.4040 | China |  | 1528-4392-ND
21 | 2223 | Adafruit Industries LLC | STACKING HEADER 40PIN | 1,513 | In Stock |  | 1 | 1 | Bulk | 1528-1385-ND | 2.50000 | $2.50 | 1 |  | 1528-1385-ND | 2 | https://cdn-shop.adafruit.com/product-files/2223/18507.pdf | J8 | N/A |  | Active | ROHS3 Compliant | EAR99 | 8536.69.4040 | China |  | 1528-1385-ND | //media.digikey.com/Photos/Adafruit%20Industries%20LLC/2223.jpg
22 | CS160808-R47K | Bourns Inc. | FIXED IND 470NH 150MA 700MOHM SM | 13,046 | In Stock |  | 4 | 4 | Cut Tape (CT) | CS160808-R47KCT-ND | 0.14000 | $0.56 | 1 |  | CS160808-R47KCT-ND | 28 | https://www.bourns.com/docs/Product-Datasheets/CS160808.pdf | L1 L2 L5 L6 | May apply on shipments to the U.S. | FIXED IND 470NH 150MA 700MOHM SM | Active | ROHS3 Compliant | EAR99 | 8504.50.8000 | China | https://www.bourns.com/docs/rohs-content/bourns-reach-letter.pdf |https://www.bourns.com/docs/rohs-cofc/cofc_cm3.pdf?sfvrsn=57869782_2 | CS160808-R47KCT-ND | //media.digikey.com/Photos/Bourns%20Photos/MFG_CS160808-SERIES.jpg
23 | MLF1608A1R5JTD25 | TDK Corporation | FIXED IND 1.5UH 50MA 700MOHM SMD | 804 | In Stock |  | 2 | 2 | Cut Tape (CT) | 445-16919-1-ND | 0.31000 | $0.62 | 1 |  | 445-16919-1-ND | 10 |  | L3 L7 | N/A | FIXED IND 1.5UH 50MA 700MOHM SMD | Active | ROHS3 Compliant | EAR99 | 8504.50.8000 | Japan | https://product.tdk.com/en/environment/index.html | 445-16919-1-ND | //media.digikey.com/Renders/TDK%20Renders/0603%20(1608%20Metric).jpg
24 | CS160808-R56K | Bourns Inc. | FIXED IND 560NH 150MA 900MOHM SM | 7,300 | In Stock |  | 1 | 1 | Cut Tape (CT) | CS160808-R56KCT-ND | 0.14000 | $0.14 | 1 |  | CS160808-R56KCT-ND | 28 | https://www.bourns.com/docs/Product-Datasheets/CS160808.pdf | L4 | May apply on shipments to the U.S. | FIXED IND 560NH 150MA 900MOHM SM | Active | ROHS3 Compliant | EAR99 | 8504.50.8000 | China | https://www.bourns.com/docs/rohs-content/bourns-reach-letter.pdf |https://www.bourns.com/docs/rohs-cofc/cofc_cm3.pdf?sfvrsn=57869782_2 | CS160808-R56KCT-ND | //media.digikey.com/Photos/Bourns%20Photos/MFG_CS160808-SERIES.jpg
25 | CRCW0603300RFKEA | Vishay Dale | RES SMD 300 OHM 1% 1/10W 0603 | 0 | Normally Stocking |  | 1 | 1 | Cut Tape (CT) | 541-300HCT-ND | 0.10000 | $0.10 | 1 |  | 541-300HCT-ND | 99 | https://www.vishay.com/docs/20035/dcrcwe3.pdf | R1 | N/A |  | Active | ROHS3 Compliant | EAR99 | 8533.21.0030 | Israel |  | 541-300HCT-ND | //media.digikey.com/Renders/Vishay%20Dale%20Renders/CRCW%200603%20%281608metric%29.jpg
26 | CR0603-FX-1002ELF | Bourns Inc. | RES SMD 10K OHM 1% 1/10W 0603 | 0 | Normally Stocking |  | 13 | 13 | Cut Tape (CT) | CR0603-FX-1002ELFCT-ND | 0.01700 | $0.22 | 1 |  | CR0603-FX-1002ELFCT-ND | 17 | https://www.bourns.com/docs/product-datasheets/cr.pdf?sfvrsn=574d41f6_14 | R9 R10 R11 R12 R13 R14 R17 R18 R19 R23 R25 R27 R28 | N/A | RES SMD 10K OHM 1% 1/10W 0603 | Active | ROHS3 Compliant | EAR99 | 8533.21.0030 | Taiwan | https://www.bourns.com/docs/Product-MDS/cr0603_mds.pdf|https://www.bourns.com/docs/rohs-cofc/crx_coc.pdf?sfvrsn=db3a74f6_10|https://www.bourns.com/docs/rohs-content/bourns-reach-letter.pdf | CR0603-FX-1002ELFCT-ND | //media.digikey.com/Renders/Bourns%20Renders/CR0603-(1608-Metric).jpg
27 | CRCW0603330RFKEB | Vishay Dale | RES SMD 330 OHM 1% 1/10W 0603 | 9,821 | In Stock |  | 1 | 1 | Cut Tape (CT) | 541-CRCW0603330RFKEBCT-ND | 0.10000 | $0.10 | 1 |  | 541-CRCW0603330RFKEBCT-ND | 99 | https://www.vishay.com/docs/20035/dcrcwe3.pdf | R15 | N/A |  | Active | ROHS3 Compliant | EAR99 | 8533.21.0030 | Israel |  | 541-CRCW0603330RFKEBCT-ND | //media.digikey.com/Renders/Vishay%20Dale%20Renders/CRCW%200603%20%281608metric%29.jpg
28 | CRCW0603200RFKTA | Vishay Dale | RES SMD 200 OHM 1% 1/10W 0603 | 0 | Normally Stocking |  | 1 | 1 | Cut Tape (CT) | 541-CRCW0603200RFKTACT-ND | 0.15000 | $0.15 | 1 |  | 541-CRCW0603200RFKTACT-ND | 99 | https://www.vishay.com/docs/20008/dcrcw.pdf | R2 | N/A | RES SMD 200 OHM 1% 1/10W 0603 | Active | RoHS non-compliant | EAR99 | 8533.21.0030 | Israel |  | 541-CRCW0603200RFKTACT-ND | //media.digikey.com/Renders/Vishay%20Dale%20Renders/CRCW%200603%20%281608metric%29.jpg
29 | CRCW06031K00FKEC | Vishay Dale | RES SMD 1K OHM 1% 1/10W 0603 | 0 | Normally Stocking |  | 2 | 2 | Cut Tape (CT) | 541-2986-1-ND | 0.10000 | $0.20 | 1 |  | 541-2986-1-ND | 99 | https://www.vishay.com/docs/20035/dcrcwe3.pdf | R16 R20 | N/A | RES SMD 1K OHM 1% 1/10W 0603 | Active | ROHS3 Compliant | EAR99 | 8533.21.0030 | Israel |  | 541-2986-1-ND | //media.digikey.com/Renders/Vishay%20Dale%20Renders/CRCW%200603%20%281608metric%29.jpg
30 | CRCW06033K90FKEA | Vishay Dale | RES SMD 3.9K OHM 1% 1/10W 0603 | 0 | Normally Stocking |  | 2 | 2 | Cut Tape (CT) | 541-3.90KHCT-ND | 0.10000 | $0.20 | 1 |  | 541-3.90KHCT-ND | 99 | https://www.vishay.com/docs/20035/dcrcwe3.pdf | R21 R22 | May apply on shipments to the U.S. | RES SMD 3.9K OHM 1% 1/10W 0603 | Active | ROHS3 Compliant | EAR99 | 8533.21.0030 | Israel |  | 541-3.90KHCT-ND | //media.digikey.com/Renders/Vishay%20Dale%20Renders/CRCW%200603%20%281608metric%29.jpg
31 | CRCW060320K0FKEC | Vishay Dale | RES SMD 20K OHM 1% 1/10W 0603 | 8,292 | In Stock |  | 2 | 2 | Cut Tape (CT) | 541-2993-1-ND | 0.10000 | $0.20 | 1 |  | 541-2993-1-ND | 99 | https://www.vishay.com/docs/20035/dcrcwe3.pdf | R24 R26 | N/A | RES SMD 20K OHM 1% 1/10W 0603 | Active | ROHS3 Compliant | EAR99 | 8533.21.0030 | Israel |  | 541-2993-1-ND | //media.digikey.com/Renders/Vishay%20Dale%20Renders/CRCW%200603%20%281608metric%29.jpg
32 | CRCW060349R9FKTA | Vishay Dale | RES SMD 49.9 OHM 1% 1/10W 0603 | 0 | Normally Stocking |  | 10 | 10 | Cut Tape (CT) | 541-3003-1-ND | 0.12900 | $1.29 | 1 |  | 541-3003-1-ND | 99 | https://www.vishay.com/docs/20008/dcrcw.pdf | R3 R4 R7 R8 R29 R30 R31 R32 R33 R34 | N/A | RES SMD 49.9 OHM 1% 1/10W 0603 | Active | RoHS non-compliant | EAR99 | 8533.21.0030 | Israel |  | 541-3003-1-ND | //media.digikey.com/Renders/Vishay%20Dale%20Renders/CRCW%200603%20%281608metric%29.jpg
33 | CRCW06031R00FNEB | Vishay Dale | RES SMD 1 OHM 1% 1/10W 0603 | 7,530 | In Stock |  | 1 | 1 | Cut Tape (CT) | 541-CRCW06031R00FNEBCT-ND | 0.10000 | $0.10 | 1 |  | 541-CRCW06031R00FNEBCT-ND | 99 | https://www.vishay.com/docs/20035/dcrcwe3.pdf | R35 | N/A |  | Active | ROHS3 Compliant | EAR99 | 8533.21.0030 | Israel |  | 541-CRCW06031R00FNEBCT-ND | //media.digikey.com/Renders/Vishay%20Dale%20Renders/CRCW%200603%20%281608metric%29.jpg
34 | CRCW060330K1FKEA | Vishay Dale | RES SMD 30.1K OHM 1% 1/10W 0603 | 0 | Normally Stocking |  | 2 | 2 | Cut Tape (CT) | 541-30.1KHCT-ND | 0.10000 | $0.20 | 1 |  | 541-30.1KHCT-ND | 99 | https://www.vishay.com/docs/20035/dcrcwe3.pdf | R5 R6 | N/A | RES SMD 30.1K OHM 1% 1/10W 0603 | Active | ROHS3 Compliant | EAR99 | 8533.21.0030 | Israel |  | 541-30.1KHCT-ND | //media.digikey.com/Renders/Vishay%20Dale%20Renders/CRCW%200603%20%281608metric%29.jpg
35 | MABAES0031 | MACOM Technology Solutions | TRANSFORMER, 4:1 | 0 | Normally Stocking |  | 2 | 2 | Cut Tape (CT) | 1465-MABAES0031CT-ND | 3.40000 | $6.80 | 1 |  | 1465-MABAES0031CT-ND | 22 | https://cdn.macom.com/datasheets/MABAES0031.pdf | T1 T2 | N/A | TRANSFORMER, 4:1 | Active | ROHS3 Compliant | EAR99 | 8504.31.4035 | Vietnam | https://www.macom.com/files/live/sites/ma/files/contributed/Quality/EU%20RoHS%20Statement%202019.pdf|https://www.macom.com/files/live/sites/ma/files/contributed/Quality/REACH%20Statement%202019.pdf | 1465-MABAES0031CT-ND | //media.digikey.com/Photos/MACom%20Technology%20Solutions/MFG_MABAES0031.jpg
36 | SGTL5000XNAA3 | NXP USA Inc. | IC AUDIO CODEC STEREO 32-QFN |  | Obsolete |  | 1 | 0 | Tray | SGTL5000XNAA3-ND | 0.00000 | $0.00 | 2450 |  | SGTL5000XNAA3-ND | 39 | https://www.nxp.com/docs/en/data-sheet/SGTL5000.pdf | U10 | N/A |  | Obsolete | ROHS3 Compliant | 5A991B1 | 8542.39.0001 | Taiwan | https://www.nxp.com/docs/en/supporting-information/NXP-ROHS-DECLARATION.pdf|https://www.nxp.com/docs/en/supporting-information/NXP-REACH-STATEMENT.pdf | SGTL5000XNAA3-ND | //media.digikey.com/Renders/FTDI%20(Future%20Tech%20Devices)%20Renders/32-VQFN%20Exposed%20Pad.jpg
37 | LD1117S33TR | STMicroelectronics | IC REG LINEAR 3.3V 800MA SOT223 | 0 | Normally Stocking |  | 1 | 1 | Cut Tape (CT) | 497-1242-1-ND | 0.60000 | $0.60 | 1 |  | 497-1242-1-ND | 53 | https://www.st.com/content/ccc/resource/technical/document/datasheet/99/3b/7d/91/91/51/4b/be/CD00000544.pdf/files/CD00000544.pdf/jcr:content/translations/en.C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 | U11 | May apply on shipments to the U.S. | IC REG LINEAR 3.3V 800MA SOT223 | Active | ROHS3 Compliant | EAR99 | 8542.39.0001 | China |  | 497-1242-1-ND | //media.digikey.com/photos/STMicro%20Photos/SOT-223.jpg
38 | LM317MBSTT3G | onsemi | IC REG LIN POS ADJ 500MA SOT223 | 0 | Normally Stocking |  | 1 | 1 | Cut Tape (CT) | LM317MBSTT3GOSCT-ND | 0.77000 | $0.77 | 1 |  | LM317MBSTT3GOSCT-ND | 53 | https://www.onsemi.com/pdf/datasheet/lm317m-d.pdf | U12 | N/A | IC REG LIN POS ADJ 500MA SOT223 | Active | ROHS3 Compliant | EAR99 | 8542.39.0001 | Malaysia | https://www.onsemi.com/PowerSolutions/MaterialComposition.do?export=pdf&opnId=LM317MBSTT3G|https://www.onsemi.com/site/pdf/REACH-compliance-statement.pdf|https://www.onsemi.com/site/pdf/RoHS-statement.pdf | LM317MBSTT3GOSCT-ND | //media.digikey.com/Renders/Diodes%20Renders/SOT223-3L.jpg
39 | SN74CBT3253CD | Texas Instruments | IC MUX/DEMUX 2 X 4:1 16SOIC | 323 | In Stock |  | 2 | 2 | Tube | 296-33866-5-ND | 1.32000 | $2.64 | 1 |  | 296-33866-5-ND | 6 | https://www.ti.com/general/docs/suppproductinfo.tsp?distId=10 | U1 U2 | N/A | IC MUX/DEMUX 2 X 4:1 16SOIC | Active | ROHS3 Compliant | EAR99 | 8542.39.0001 | Mexico |  | 296-33866-5-ND | //media.digikey.com/Renders/Texas%20Instr%20Renders/296~4040047-6~D~16.JPG
40 | SI5351A-B-GTR | Skyworks Solutions Inc. | IC CLK GENERATOR 200MHZ 10MSOP | 0 | Normally Stocking |  | 1 | 1 | Cut Tape (CT) | 336-3908-1-ND | 2.21000 | $2.21 | 1 |  | 336-3908-1-ND | 52 | https://www.skyworksinc.com/-/media/Skyworks/SL/documents/public/data-sheets/Si5351-B.pdf | U3 | N/A | IC CLK GENERATOR 200MHZ | Active | Unknown | EAR99 | 8542.39.0001 | Malaysia |  | 336-3908-1-ND | //media.digikey.com/photos/Silicon%20Labs%20Photos/MFG_MSOP10.jpg
41 | OPA1602AID | Texas Instruments | IC AUDIO 2 CIRCUIT 8SOIC | 879 | In Stock |  | 1 | 1 | Tube | 296-28930-5-ND | 3.59000 | $3.59 | 1 |  | 296-28930-5-ND | 6 | https://www.ti.com/general/docs/suppproductinfo.tsp?distId=10 | U4 | N/A | IC AUDIO 2 CIRCUIT 8SOIC | Active | ROHS3 Compliant | EAR99 | 8542.33.0001 | Malaysia |  | 296-28930-5-ND | //media.digikey.com/Renders/Texas%20Instr%20Renders/8-SOIC.jpg
42 | TLV2462CDR | Texas Instruments | IC OPAMP GP 2 CIRCUIT 8SOIC | 0 | Normally Stocking |  | 2 | 2 | Cut Tape (CT) | 296-2434-1-ND | 2.73000 | $5.46 | 1 |  | 296-2434-1-ND | 35 | https://www.ti.com/general/docs/suppproductinfo.tsp?distId=10 | U5 U7 | N/A | IC OPAMP GP 2 CIRCUIT 8SOIC | Active | ROHS3 Compliant | EAR99 | 8542.33.0001 | Mexico |  | 296-2434-1-ND | //media.digikey.com/Renders/Texas%20Instr%20Renders/8-SOIC.jpg
43 | DS3231MZ+ | Analog Devices Inc./Maxim Integrated | IC RTC CLK/CALENDAR I2C 8-SOIC | 0 | Normally Stocking |  | 1 | 1 | Tube | DS3231MZ+-ND | 9.64000 | $9.64 | 1 |  | DS3231MZ+-ND | 11 | https://datasheets.maximintegrated.com/en/ds/DS3231M.pdf | U6 | N/A |  | Active | ROHS3 Compliant | EAR99 | 8542.39.0001 | Taiwan | https://www.maximintegrated.com/content/dam/files/design/emmi/rohs-certificate-of-compliance.pdf|https://www.maximintegrated.com/content/dam/files/design/emmi/red-phosphorous-statement.pdf|https://www.maximintegrated.com/content/dam/files/design/emmi/halogen-free-status-memo-02mar14.pdf|https://pdfserv.maximintegrated.com/cgi-bin/emmi_pdf.cgi?ID=1578473&PN=DS3231MZ%2B | DS3231MZ+-ND | //media.digikey.com/Renders/Maxim%20Renders/175~21-0041~SA~8.JPG
44 | AP7313-18SAG-7 | Diodes Incorporated | IC REG LINEAR 1.8V 150MA SOT23-3 | 4,778 | In Stock |  | 1 | 1 | Cut Tape (CT) | AP7313-18SAG-7DICT-ND | 0.39000 | $0.39 | 1 |  | AP7313-18SAG-7DICT-ND | 90 | https://www.diodes.com/assets/Datasheets/AP7313.pdf | U8 | May apply on shipments to the U.S. | IC REG LINEAR 1.8V 150MA SOT23-3 | Active | ROHS3 Compliant | EAR99 | 8542.39.0001 | China | https://www.diodes.com/assets/Quality-Reliability-Docs/Master_CofC.pdf | AP7313-18SAG-7DICT-ND | //media.digikey.com/Renders/Diodes%20Renders/SOT-23-3%20PKG.jpg
45 | CAT24C128WI-GT3 | onsemi | IC EEPROM 128KBIT I2C 1MHZ 8SOIC | 577 | In Stock |  | 1 | 1 | Cut Tape (CT) | CAT24C128WI-GT3CT-ND | 0.37000 | $0.37 | 1 |  | CAT24C128WI-GT3CT-ND | 37 | https://www.onsemi.com/pdf/datasheet/cat24c128-d.pdf | U9 | N/A | IC EEPROM 128KBIT I2C 1MHZ 8SOIC | Active | ROHS3 Compliant | EAR99 | 8542.32.0051 | Thailand | https://www.onsemi.com/PowerSolutions/MaterialComposition.do?export=pdf&opnId=CAT24C128WI-GT3|https://www.onsemi.com/site/pdf/REACH-compliance-statement.pdf|https://www.onsemi.com/site/pdf/RoHS-statement.pdf | CAT24C128WI-GT3CT-ND | //media.digikey.com/Renders/On%20Semi%20Renders/488~751BD-01~W,%20V~8.JPG
46 | ABM8W-25.0000MHZ-8-B1U-T3 | Abracon LLC | CRYSTAL 25.0000MHZ 8PF SMD | 0 | Normally Stocking |  | 1 | 1 | Cut Tape (CT) | 535-14058-1-ND | 0.69000 | $0.69 | 1 |  | 535-14058-1-ND | 27 | https://abracon.com/Resonators/ABM8W.pdf | Y1 | N/A | CRYSTAL 25.0000MHZ 8PF SMD | Active | ROHS3 Compliant | EAR99 | 8541.60.0060 | China | https://abracon.com/uploads/resources/REACH-219-SVHC-Certificate-Rev-Q-2021-07-08-Abracon-LLC.pdf | 535-14058-1-ND | //media.digikey.com/renders/Abracon%20Renders/ABM3B%20Series.jpg

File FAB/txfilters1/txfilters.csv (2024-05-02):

Reference | Value | Datasheet | Description | DigiKey Part Number | Manufacturer_Name | Manufacturer_Part_Number | Qty
C1, C7 | 470p | https://datasheets.kyocera-avx.com/C0GNP0-KGM.pdf | CAP CER 470PF 200V C0G/NP0 1206 | 478-KGM31VCG2D471JUCT-ND | KYOCERA AVX | KGM31VCG2D471JU | 2
C2, C3, C8 | 100n | https://www.digikey.com/en/models/3886691 | 0.1 µF ±5% 50V Ceramic Capacitor X7R 0603 (1608 Metric) | 1276-1033-1-ND | Samsung Electro-Mechanics | CL10B104JB8NNNC | 3
C4, C5 | 820p | https://datasheets.kyocera-avx.com/C0GNP0-KGM.pdf | CAP CER 820PF 200V C0G/NP0 1206 | 478-KGM31VCG2D821JUCT-ND | KYOCERA AVX | KGM31VCG2D821JU | 2
C6 | 33µ 25V | https://industrial.panasonic.com/cdbs/www-data/pdf/RDE0000/ABA0000C1181.pdf | CAP ALUM 33UF 20% 25V SMD | PCE3802CT-ND | Panasonic Electronic Components | EEE-FK1E330UR | 1
C9, C12 | 270p | https://datasheets.kyocera-avx.com/C0GNP0-KGM.pdf | CAP CER 270PF 200V C0G/NP0 1206 | 478-KGM31BCG2D271JTCT-ND | KYOCERA AVX | KGM31BCG2D271JT | 2
C10, C11 | 680p | https://datasheets.kyocera-avx.com/C0GNP0-KGM.pdf | CAP CER 680PF 200V C0G/NP0 1206 | 478-KGM31VCG2D681JUCT-ND | KYOCERA AVX | KGM31VCG2D681JU | 2
C13, C16, C22, C23 | 150p | https://datasheets.kyocera-avx.com/C0GNP0-KGM.pdf | CAP CER 150PF 200V C0G/NP0 1206 | 478-KGM31BCG2D151JTCT-ND | KYOCERA AVX | KGM31BCG2D151JT | 4
C14, C15, C28, C29 | 390p | https://datasheets.kyocera-avx.com/C0GNP0-KGM.pdf | CAP CER 390PF 200V C0G/NP0 1206 | 478-KGM31BCG2D391JTCT-ND | KYOCERA AVX | KGM31BCG2D391JT | 4
C17, C20, C21, C24 | 47p | https://datasheets.kyocera-avx.com/C0GNP0-KGM.pdf | CAP CER 47PF 200V C0G/NP0 1206 | 478-KGM31BCG2D470JTCT-ND | KYOCERA AVX | KGM31BCG2D470JT | 4
C18, C19 | 220p | https://datasheets.kyocera-avx.com/C0GNP0-KGM.pdf | CAP CER 220PF 200V C0G/NP0 1206 | 478-KGM31BCG2D221JTCT-ND | KYOCERA AVX | KGM31BCG2D221JT | 2
C25, C30-C34, C36, C37, C40, C41, C44, C45 | 0p | ~ | DNP Place Holder |  |  |  | 12
C26, C27 | 10n | https://mm.digikey.com/Volume0/opasdata/d220001/medias/docus/609/CL10C102JB8NNNC_Spec.pdf | CAP CER 1000PF 50V C0G/NP0 0603 | 1276-1091-1-ND | Samsung Electro-Mechanics | Samsung Electro-Mechanics | 2
C35, C38, C39, C42 | 33p | https://datasheets.kyocera-avx.com/C0GNP0-KGM.pdf | CAP CER 33PF 200V C0G/NP0 1206 | 478-KGM31BCG2D330JTCT-ND | KYOCERA AVX | KGM31BCG2D330JT | 4
C43, C46 | 10p | https://datasheets.kyocera-avx.com/C0GNP0-KGM.pdf | CAP CER 10PF 200V C0G/NP0 1206 | 478-KGM31BCG2D100JTCT-ND | KYOCERA AVX | KGM31BCG2D100JT | 2
D1, D2 | 1n5711wds | https://www.diodes.com/assets/Datasheets/1N5711WS.pdf | DIODE SCHOTTKY 70V 150MW SOD323 | 1N5711WS-FDICT-ND | Diodes Incorporated | 1N5711WS-7-F | 2
H1-H6 | 2.5mm | ~ | DNP Hole |  |  |  | 6
J1 | GPIO | ~ |  |  |  |  | 1
J2 | Input | ~ |  |  |  |  | 1
J3 | Antenna | ~ |  |  |  |  | 1
J4 | Pwr | ~ |  |  |  |  | 1
J5 | RX | ~ |  |  |  |  | 1
J6 | /PA | ~ |  |  |  |  | 1
K1-K6 | IM06 | https://www.te.com/usa-en/product-2-1462037-7.datasheet.pdf | RELAY TELECOM DPDT 2A 12V | PB1096-ND | https://www.te.com/usa-en/product-2-1462037-7.datasheet.pdf | 2-1462037 | 6
L1, L3 | 2.42uh | https://web.archive.org/web/20100124053352/http://www.gqrp.com/technical2.htm | 25 Turns on Micrometals T37-2 26AWG |  |  |  | 2
L2 | 3.01uh | https://web.archive.org/web/20100124053352/http://www.gqrp.com/technical2.htm | 27 Turns on Micrometals T37-2 26AWG |  |  |  | 1
L4, L6 | 1.38u | https://web.archive.org/web/20100124053352/http://www.gqrp.com/technical2.htm | 19 Turns on Micrometals T37-6 28AWG |  |  |  | 2
L5 | 1.70u | https://web.archive.org/web/20100124053352/http://www.gqrp.com/technical2.htm | 21 Turns on Micrometals T37-6 28AWG |  |  |  | 1
L7, L9 | 773n | https://web.archive.org/web/20100124053352/http://www.gqrp.com/technical2.htm | 16 Turns on Micrometals T37-6 24AWG |  |  |  | 2
L8 | 990n | https://web.archive.org/web/20100124053352/http://www.gqrp.com/technical2.htm | 17 Turns on Micrometals T37-6 24AWG |  |  |  | 1
L10, L12 | 444n | https://web.archive.org/web/20100124053352/http://www.gqrp.com/technical2.htm | 12 Turns on Micrometals T37-6 22AWG |  |  |  | 2
L11 | 561n | https://web.archive.org/web/20100124053352/http://www.gqrp.com/technical2.htm | 13 Turns on Micrometals T37-6 22AWG |  |  |  | 1
L13, L15 | 300n | https://web.archive.org/web/20100124053352/http://www.gqrp.com/technical2.htm | 10 Turns on Micrometals T37-6 22AWG |  |  |  | 2
L14 | 380n | https://web.archive.org/web/20100124053352/http://www.gqrp.com/technical2.htm | 11 Turns on Micrometals T37-6 22AWG |  |  |  | 1
L16, L17 | T37-43 1:13 | ~ | 13:1 Turns on Amidon T37-43 22AWG |  |  |  | 2
R1, R2, R7, R8 | 10k | https://www.seielect.com/catalog/sei-rmcf_rmcp.pdf | RES 10K OHM 1% 1/10W 0603 | RMCF0603FT10K0CT-ND | Stackpole Electronics Inc | RMCF0603FT10K0 | 4
R3 | 1k | https://www.seielect.com/catalog/sei-rmcf_rmcp.pdf | RES 1K OHM 1% 1/10W 0603 | RMCF0603FT1K00CT-ND | Stackpole Electronics Inc | RMCF0603FT1K00 | 1
R4 | 9.0k | https://www.seielect.com/catalog/sei-rmcf_rmcp.pdf | RES 9.09K OHM 1% 1/10W 0603 | RMCF0603FT9K09CT-ND | Stackpole Electronics Inc | RMCF0603FT9K09 | 1
R5, R6 | 51 | https://www.seielect.com/catalog/sei-rmcf_rmcp.pdf | RES 51 OHM 1% 1/10W 0603 | RMCF0603FT51R0CT-ND | Stackpole Electronics Inc | RMCF0603FT51R0 | 2
U1 | ADS1115IDGS | http://www.ti.com/lit/ds/symlink/ads1113.pdf | IC ADC 16BIT SIGMA-DELTA 10VSSOP | 296-38849-1-ND | Texas Instruments | ADS1115IDGSR | 1
U2 | MCP23008-xML | http://ww1.microchip.com/downloads/en/DeviceDoc/MCP23008-MCP23S08-Data-Sheet-20001919F.pdf | IC XPNDR 1.7MHZ I2C 20QFN | MCP23008T-E/MLCT-ND | Microchip Technology | MCP23008T-E/ML | 1
U3 | ULN2003A | http://www.ti.com/lit/ds/symlink/uln2003a.pdf | 5A@50V 3V@2V,300MA 1.7V@350MA 0. | 4518-ULN2003ACT-ND | UMW | ULN2003A | 1

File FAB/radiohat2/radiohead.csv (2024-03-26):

Source: | /Users/mvano/Documents/KiCad/radiohat2/radiohead.kicad_sch
Date: | Tuesday, January 23, 2024 at 07:33:08 PM
Tool: | Eeschema 7.0.10
Generator: | /Applications/KiCad/KiCad.app/Contents/SharedSupport/plugins/bom_csv_grouped_by_value.py
Component Count: | 153
Collated Components:
Item | Qty | Reference(s) | Value | LibPart | Footprint | Datasheet | DNP | Description | DigiKey Part Number | Height | Manufacturer_Name | Manufacturer_Part_Number | Mouser Part Number
1 | 2 | C1, C50 | 10n | Device:C_Small | Capacitor_SMD:C_0603_1608Metric | ~ |  | 10000 pF ±5% 50V Ceramic Capacitor X7R 0603 (1608 Metric) | 720-1375-1-ND |  | Vishay Vitramon | VJ0603Y103JXAAC
2 | 4 | C2, C3, C4, C5 | 470n | Device:C_Small | Capacitor_SMD:C_0603_1608Metric | ~ |  | CAP CER 0.47UF 25V X7R 0603 | 13-CC0603JRX7R8BB474CT-ND |  | YAGEO | CC0603JRX7R8BB474
3 | 2 | C6, C12 | 200p | Device:C_Small | Capacitor_SMD:C_0603_1608Metric | ~ |  | CAP CER 200PF 50V C0G/NP0 0603 | 399-C0603C201J5GAC7867CT-ND |  | KEMET | C0603C201J5GAC7867
4 | 2 | C7, C18 | 360p | Device:C_Small | Capacitor_SMD:C_0603_1608Metric | ~ |  | CAP CER 360PF 50V NP0 0603 | 399-15397-1-ND |  | KEMET | C0603C361J5GAC7867
5 | 14 | C8, C9, C33, C34, C35, C36, C37, C39, C46, C47, C54, C56, C57, C68 | 100n | Device:C | Capacitor_SMD:C_0603_1608Metric | ~ |  | 0.1 µF ±5% 50V Ceramic Capacitor X7R 0603 (1608 Metric) | 1276-1033-1-ND |  | Samsung Electro-Mechanics | CL10B104JB8NNNC
6 | 2 | C10, C19 | 750p | Device:C_Small | Capacitor_SMD:C_0603_1608Metric | ~ |  | CAP CER 750PF 50V C0G/NP0 0603 | 399-C0603C751J5GAC7867CT-ND |  | KEMET | C0603C751J5GAC7867
7 | 7 | C11, C29, C40, C49, C51, C52, C53 | 10µ | Device:C_Small | Capacitor_SMD:C_0603_1608Metric | ~ |  | 10 µF ±10% 6.3V Ceramic Capacitor X5R 0603 (1608 Metric) | 1276-1038-1-ND |  | Samsung Electro-Mechanics | CL10A106KQ8NNNC
8 | 8 | C13, C14, C15, C16, C17, C20, C21, C44 | 1µ | Device:C_Small | Capacitor_SMD:C_0603_1608Metric | ~ |  | CAP CER 1UF 6.3V X5R 0603 | 1276-1036-1-ND |  | Samsung Electro-Mechanics | CL10A105KQ8NNNC
9 | 10 | C22, C23, C28, C38, C55, C62, C63, C64, C66, C67 | 100n | Device:C_Small | Capacitor_SMD:C_0603_1608Metric | ~ |  | 0.1 µF ±5% 50V Ceramic Capacitor X7R 0603 (1608 Metric) | 1276-1033-1-ND |  | Samsung Electro-Mechanics | CL10B104JB8NNNC
10 | 2 | C24, C31 | 620p | Device:C_Small | Capacitor_SMD:C_0603_1608Metric | ~ |  | CAP CER 620PF 50V C0G/NP0 0603 | 399-C0603C621J5GAC7867CT-ND |  | KEMET | 399-C0603C621J5GAC7867DKR-ND
11 | 2 | C25, C27 | 130p | Device:C_Small | Capacitor_SMD:C_0603_1608Metric | ~ |  | CAP CER 130PF 50V NP0 0603 | 399-15363-1-ND |  | KEMET | C0603C131J5GAC7867
12 | 2 | C26, C32 | 180p | Device:C_Small | Capacitor_SMD:C_0603_1608Metric | ~ |  | CAP CER 180PF 50V C0G/NP0 0603 | 399-C0603C181J5GAC7867CT-ND |  | KEMET | C0603C181J5GAC7867
13 | 1 | C30 | 33µ 25V | radiohead-rescue:CP_Small-Device | Capacitor_SMD:C_Elec_5x5.8 |  |  | CAP ALUM 33UF 20% 25V SMD | PCE3802CT-ND |  | Panasonic Electronic Components | EEE-FK1E330UR
14 | 4 | C41, C42, C43, C65 | 1n | Device:C_Small | Capacitor_SMD:C_0603_1608Metric | ~ |  | CAP CER 1000PF 50V C0G/NP0 0603 | 1276-1091-1-ND |  | Samsung Electro-Mechanics | CL10C102JB8NNNC
15 | 1 | C45 | 100µ 5V | radiohead-rescue:CP_Small-Device | Capacitor_SMD:C_Elec_6.3x5.4 |  |  | CAP ALUM 100UF 20% 6.3V SMD | PCE4377CT-ND |  | Panasonic Electronic Components | EEE-FK0J101AP
16 | 1 | C48 | 1500µ 6.3V | :CP_Small-Device_1 | Capacitor_SMD:C_Elec_10x10.2 |  |  | CAP ALUM 1500UF 20% 6.3V SMD | PCE4719CT-ND |  | Panasonic Electronic Components | EEE-HAJ152UAP
17 | 4 | C58, C59, C60, C61 | 22n | Device:C_Small | Capacitor_SMD:C_0603_1608Metric | ~ |  | CAP CER 0.22UF 25V X7R 0603 | 490-GRM188R71E224JA88DCT-ND |  | Murata Electronics | GRM188R71E224JA88D
18 | 2 | D1, D2 | 20V 500MA | Diode:MBR0520LT | Diode_SMD:D_SOD-123 | http://www.onsemi.com/pub_link/Collateral/MBR0520LT1-D.PDF |  | DIODE SCHOTTKY 20V 500MA SOD123 | 641-1326-1-ND |  | Comchip Technology | CDBW0520L-G
19 | 1 | J6 | STEMMA I2C | Connector:Conn_01x04_Pin | Connector_JST:JST_PH_B4B-PH-K_1x04_P2.00mm_Vertical | ~ |  | CONN HEADER VERT 4POS 2MM | 455-B4B-PH-K-ND |  | JST Sales America Inc. | B4B-PH-K
20 | 3 | K1, K2, K3 | IM43 | Relay:IM43 | Relay_THT:Relay_DPDT_AXICOM_IMSeries_Pitch5.08mm | http://www.te.com/commerce/DocumentDelivery/DDEController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 |  | Telecom Relay DPDT (2 Form C) Through Hole | PB2081-ND |  | TE Connectivity Potter & Brumfield Relays | 5-1462037-8
21 | 4 | L1, L2, L5, L6 | 470n | Device:L_Small | Inductor_SMD:L_0603_1608Metric | ~ |  | FIXED IND 470NH 100MA 950MOHM SM | 445-16967-1-ND |  | TDK Corporation | MLF1608DR47JTD25
22 | 2 | L3, L7 | 1µ5 | Device:L_Small | Inductor_SMD:L_0603_1608Metric | ~ |  | FIXED IND 1.5UH 50MA 700MOHM SMD | 445-175367-1-ND |  | TDK Corporation | MLF1608A1R5JT000
23 | 1 | L4 | 560n | Device:L_Small | Inductor_SMD:L_0603_1608Metric | ~ |  | FIXED IND 560NH 400MA 520MOHM SM | 445-174193-1-ND |  | TDK Corporation | MLJ1608WR56JT000
24 | 2 | L8, L14 | 560n | Device:L_Small | Inductor_SMD:L_0805_2012Metric | ~ |  | FIXED IND 560NH 150MA 550MOHM SM | 445-181347-1-ND |  | TDK Corporation | MLF2012DR56JT000
25 | 3 | L9, L11, L15 | 820n | Device:L_Small | Inductor_SMD:L_0805_2012Metric | ~ |  | FIXED IND 820NH 150MA 650MOHM SM | 445-181349-1-ND |  | TDK Corporation | MLF2012DR82JT000
26 | 3 | L10, L12, L16 | 1µ5 | Device:L_Small | Inductor_SMD:L_0805_2012Metric | ~ |  | FIXED IND 1.5UH 80MA 400MOHM SMD | 445-181332-1-ND |  | TDK Corporation | MLF2012A1R5JT000
27 | 1 | L13 | 2µ7 | Device:L_Small | Inductor_SMD:L_0805_2012Metric | ~ |  | FIXED IND 2.7UH 50MA 550MOHM SMD | 445-181334-1-ND |  | TDK Corporation | MLF2012A2R7JT000
28 | 1 | L17 | 40µ | predriver-rescue:L_Core_Ferrite_Small-Device | Inductor_SMD:L_0805_2012Metric |  |  | FIXED IND 47UH 170MA 3.7 OHM SMD | 445-6400-1-ND |  | TDK Corporation | MLZ2012M470WT000
29 | 1 | Q1 | PN2222A | Transistor_BJT:PN2222A | Package_TO_SOT_THT:TO-92_Inline | https://www.onsemi.com/pub/Collateral/PN2222-D.PDF |  | TRANS NPN 40V 1A TO92-3 | PN2222AFS-ND |  | onsemi | PN2222ABU
30 | 1 | R1 | 12k | Device:R_Small | Resistor_SMD:R_0603_1608Metric | ~ |  | RES 20K OHM 1% 1/10W 0603 | RMCF0603FT12K0CT-ND |  | Stackpole Electronics Inc | RMCF0603FT12K0
31 | 3 | R2, R24, R26 | 20k | Device:R_Small | Resistor_SMD:R_0603_1608Metric | ~ |  | RES 20K OHM 1% 1/10W 0603 | RMCF0603FT20K0CT-ND |  | Stackpole Electronics Inc | RMCF0603FT20K0
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

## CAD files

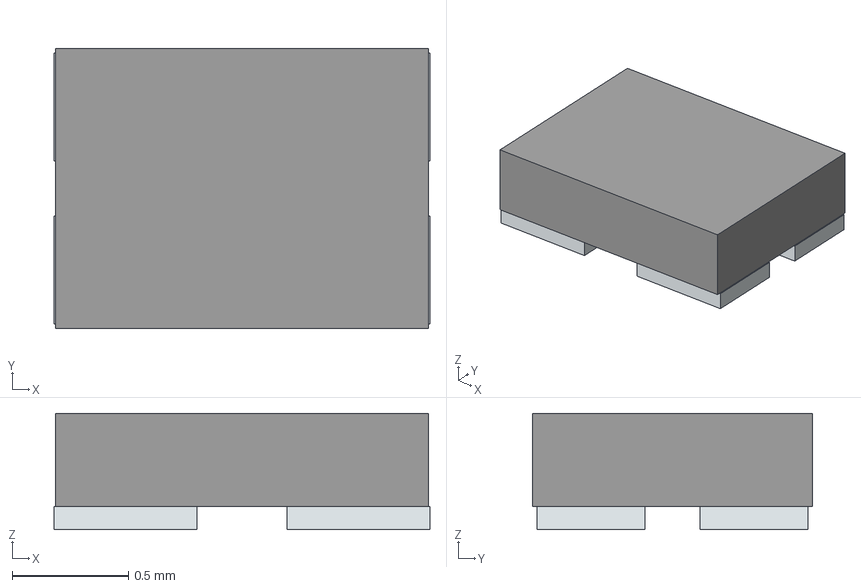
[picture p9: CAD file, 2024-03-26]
FAB/radiohat2_QFP32/raw libraries/LIB_ABM12W-25.0000MHZ-4-D1X-T3/ABM12W-25.0000MHZ-4-D1X-T3/3D/ABM12W-25.0000MHZ-4-D1X-T3.stp
1.61 x 1.20 x 0.5 mm
Pins

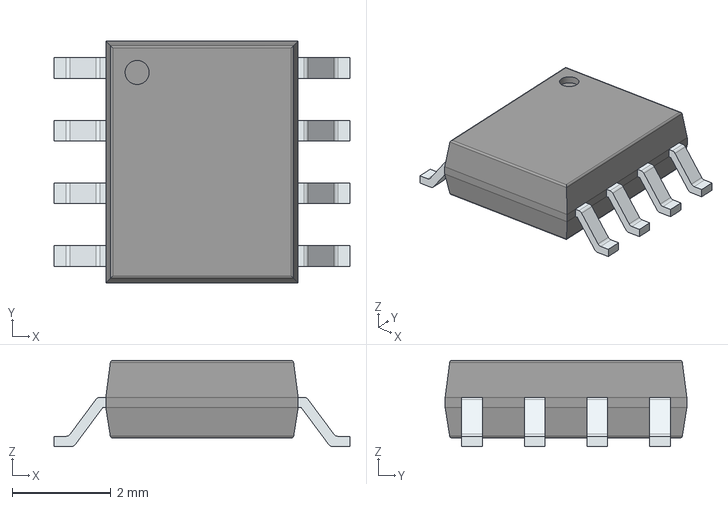
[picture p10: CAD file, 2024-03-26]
FAB/radiohat2_QFP32/raw libraries/LIB_DS3231MZ_V+/DS3231MZ_V+/3D/DS3231MZ_V+.stp
6.00 x 4.90 x 1.75 mm
PinsArrayLR

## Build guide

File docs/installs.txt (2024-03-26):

			Radiohat install for Bookworm 32/64 2023-Oct-18

1. Install some useful utilities from raspbian repository

	sudo apt install wsjtx fldigi qsstv pavucontrol-qt pipx

2. unzip radiohat directory into home directory then:

	sudo apt install libncurses-dev libgpiod-dev
	cd radiohat/libradiohat ; make clean ; make
	sudo make install

   The codec will not be available until the next restart!

FOR COMPATIBILITy WITH rVNC CLIENTS (not fully secure)

	edit ~/config/wayland/config to add the line:
		relax_encryption=true

FOR GNURADIO

Note that GNURADIO is currently working very badly with Wayland and generates many
long-winded warnings during execution. It's not very compatible with BOOKWORM.

1. 	sudo apt install gnuradio

2. delete any __pycache__ directories in ~/radiohat/libradiohat/GRC and
   its subfolders

3. Open all dsp graphs (.grc files) you intend to use and correct any
   version incompatibilities in them or in their sub modules, 
   then regenerate them

4. quit gnuradio-companion and restart it.

FOR VERY OLD QUISK VERSION FROM REPOSITORY:

1. 	sudo apt install quisk

2. setup quisk to use a radio of type Softrock and browse
   to point the hardware file to:

	~/radiohat/libradiohat/QUISK/radiohat_hardware.py

3. set the various audio io selections to:

	(quisk allows shortened device names)

	alsa:USB
	alsa:USB
	alsa:Radiohat
	alsa:Radiohat
	swap the I and Q on the radio IO input configuration

FOR LATEST QUISK

1. 	sudo apt install pipx
 	sudo apt install libasound2-dev python3-dev libpython3-dev \
      		python3-usb python3-setuptools portaudio19-dev \
      		libpulse-dev libgtk-4-dev libgtk-3-dev libgtk2.0-dev \
      		libcurl4-openssl-dev

	NOTE THAT PIPX DOES NOT REQUIRE SUDO OR ROOT ACCESS

		pipx install quisk (MAY TAKE AROUND AN HOUR)
		pipx ensurepath

5. setup quisk to use a radio of type Softrock by browsing to point the
   hardware file to:

	~/radiohat/libradiohat/QUISK/radiohatpkg/radiohat_hardware.py

6. set the audio io to
	alsa:USB
	alsa:USB
	alsa:Radiohat
	alsa:Radiohat
	swap the I and Q on the radio IO input configuration

7.  If you have I2C Voltage and VSWR sensors connected to an ADS1115 ADC board with reverse=CH0,
    forward=CH2 and (battery/10)=CH2 as described in vfo.cpp, then browse in the 
    Quisk radio configuration to set the widgets file to point to:
 
	~/radiohat/libradiohat/QUISK/radiohatpkg/widgets_tx.py

FOR BEST RESULTS WITH RadioHat 0.9/1.0 boards and Quisk

1. REMOVE C6 and C7
2. CHANGE R3,R4,R7,R8 to 0 ohm jumpers
3. CHANGE R11,R12 to 5.1K
4. Use a generic USB audio interface for microphone and headphone

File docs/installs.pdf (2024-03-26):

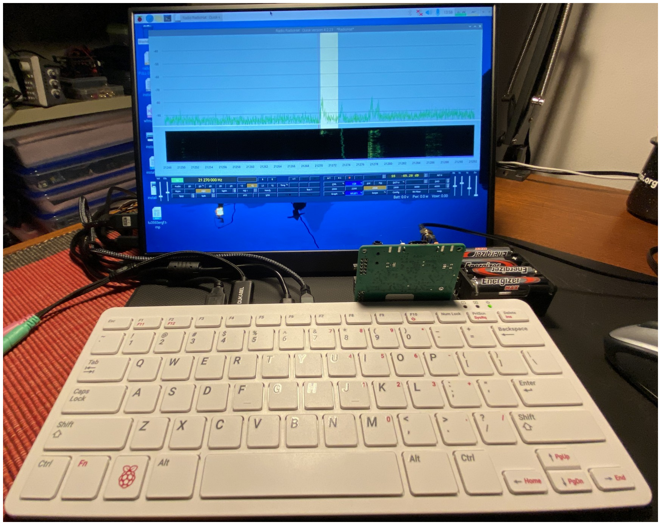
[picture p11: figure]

A Simple RadioHat Installation for Bookworm 32/64 2024-Mar-26

## 1. Configure and install the RadioHat1 or RadioHat2 card

Set Board Power Jumper as required:
1. EITHER Set Card to get power from Raspberry Pi (Noisy, and the tx lp filters and predriver on RadioHat2 will not be operating, but OK for a quick test):

Install a BiPin Jumper between pins 9 and 10 as shown here:

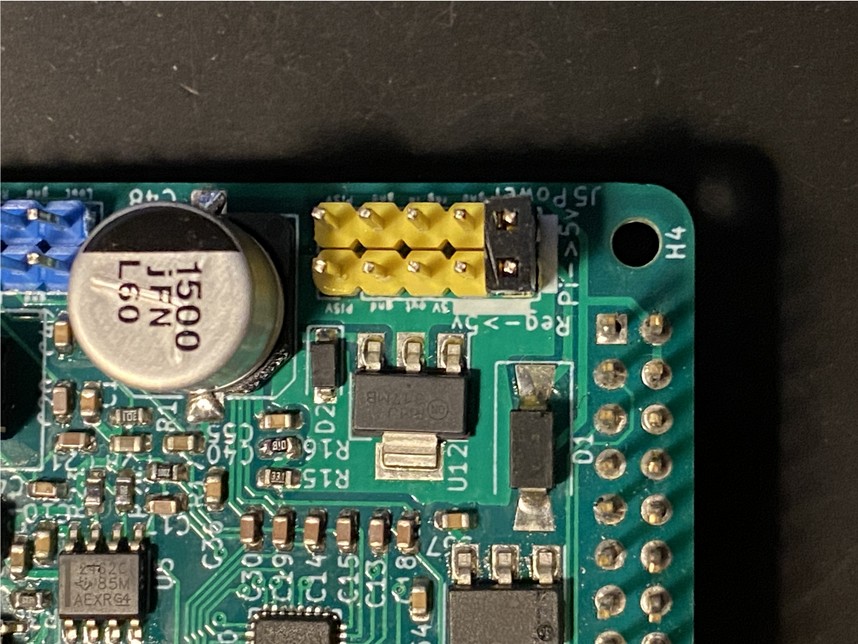
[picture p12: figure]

2. OR Set Card to get power from an external 7-15 Volt supply (Better):
1. Install a BiPin Jumper between pins 9 and 7 (bare) of J5 as shown:
2. Connect power + (red) to pin 6 as shown:
3. Connect power – (black) to pin 4 as shown:

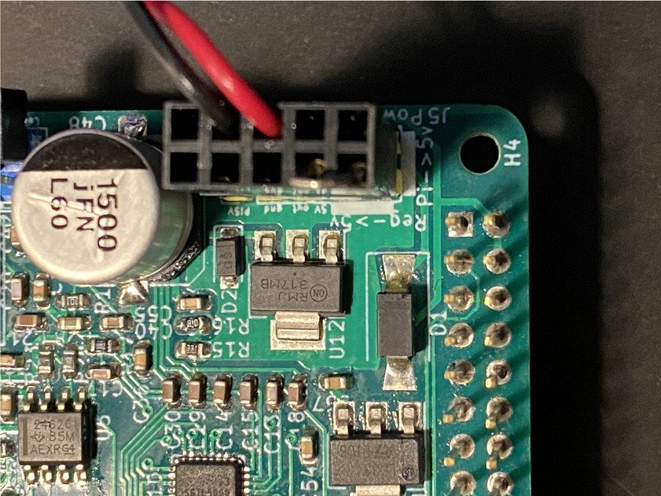
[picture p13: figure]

3. Carefully install the card on the GPIO connector of your Pi. MAKE SURE THE CONNECTOR IS PROPERLY ALIGNED WITH THE GPIO PINS AND NOT OFF BY ONE!
A Simple RadioHat Installation for Bookworm 32/64 2024-Mar-26 | PAGE 1

## 2. Install some useful utilities from the raspbian repository

sudo apt install wsjtx fldigi qsstv pavucontrol-qt pipx

## 2. unzip (or clone from github) the radiohat directory into your home directory then:

git clone git@github.com:mpvano/radiohat2.git

sudo apt install libncurses-dev libgpiod-dev

cd radiohat2/libradiohat ; make clean ; make

sudo make install

The codec will not be available until the next restart!

## TO INSTALL THE VERY OLD QUISK FROM THE RASPBIAN REPOSITORY:

1. Run the following command from a shell:

sudo apt install quisk
2. setup quisk to use a radio of type Softrock and browse

to point the hardware file to:

~/radiohat/libradiohat/QUISK/radiohatpkg/hardware_radiohat1.py
3. Set the various audio io selections to (quisk allows shortened device names):

alsa:USB

alsa:USB

alsa:Radiohat

alsa:Radiohat

swap the I and Q on the radio IO sound configuration window

A Simple RadioHat Installation for Bookworm 32/64 2024-Mar-26 | PAGE 2

## TO INSTALL THE LATEST QUISK (Best!)

1. Run the following commands from a shell:

sudo apt install pipx

sudo apt install libasound2-dev python3-dev libpython3-dev \

python3-usb python3-setuptools portaudio19-dev \

libpulse-dev libgtk-4-dev libgtk-3-dev libgtk2.0-dev \

libcurl4-openssl-dev

## #NOTE THAT PIPX DOES NOT REQUIRE SUDO OR ROOT ACCESS

pipx install quisk # MAY TAKE AROUND AN HOUR

pipx ensurepath

2. setup quisk to use a radio of type Softrock and browse to point the hardware file to:

~/radiohat2/libradiohat/QUISK/radiohatpkg/hardware_radiohat1.py

3. Set the various audio io selections to the following (quisk allows shortened device names):

alsa:USB

alsa:USB

alsa:Radiohat

alsa:Radiohat

swap the I and Q on the radio IO sound configuration window

4. If you have I2C Voltage and VSWR sensors connected to an ADS1115 ADC board with reverse=CH0, forward=CH2 and (battery/10)=CH2 as described in vswr.cpp, then browse in the Quisk radio configuration to set the widgets file to point to:

~/radiohat2/libradiohat/QUISK/radiohatpkg/widgets_tx.py

A Simple RadioHat Installation for Bookworm 32/64 2024-Mar-26 | PAGE 3

## FOR BEST RESULTS WITH RadioHat 0.9/1.0 boards and Quisk

These changes will widen and flatten the receiver bandwidth to allow nicer spectrum and waterfall displays over the entire passband.

1. REMOVE C6 and C7 (note empty SMT pads) as shown below:
2. CHANGE R3, R4, R7, R8 to 0 (marked 000) ohm jumpers as shown:
3. CHANGE R11, R12 to 5k1 (marked 512) as shown:
4. Use a generic USB audio interface for microphone and headphone – otherwise use pulse:default for “radio sound output” and/or “microphone input” in the “sound” dialog.

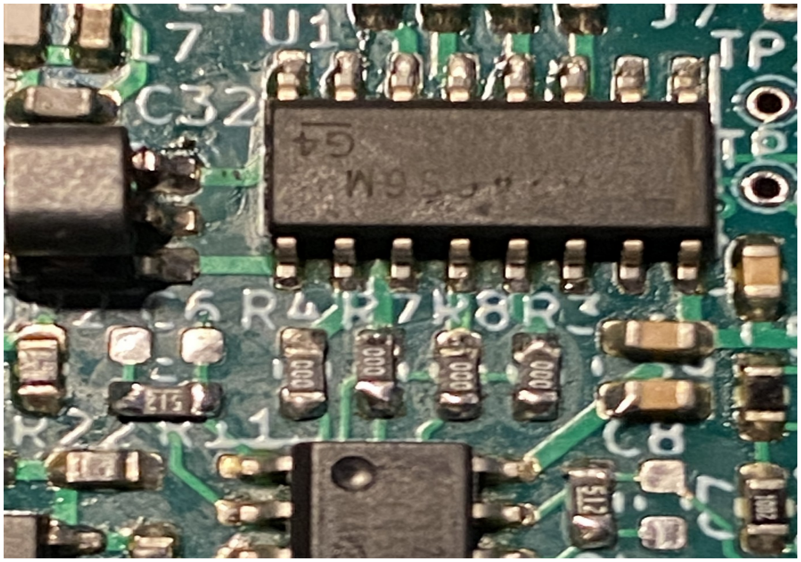
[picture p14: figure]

A Simple RadioHat Installation for Bookworm 32/64 2024-Mar-26 | PAGE 4

## FOR GNURADIO

Note that GNURADIO is currently working very badly with Wayland and generates many long-winded warnings during execution. It's not very compatible with BOOKWORM. GNURADIO is NOT required for quisk to operate with RadioHat – it’s only needed if you wish to play with some of the other included test software.

1. sudo apt install gnuradio
2. delete any __pycache__ directories in ~/radiohat/libradiohat/GRC and

its subfolders

3. Open all dsp graphs (.grc files) you intend to use and correct any

version incompatibilities in them or in their sub modules,

then regenerate them.

4. Quit gnuradio-companion and restart it
A Simple RadioHat Installation for Bookworm 32/64 2024-Mar-26 | PAGE 5

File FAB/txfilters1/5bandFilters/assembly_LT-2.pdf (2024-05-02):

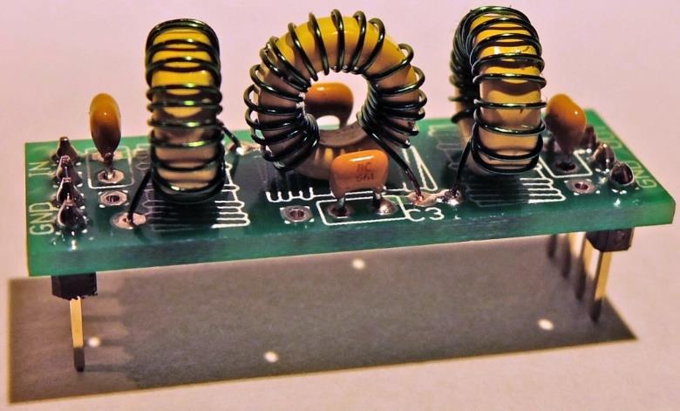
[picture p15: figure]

Rev 1.0 | 1

## Low Pass Filter kit assembly instructions

## 1. Introduction

A low pass filter (LPF) is required following the power amplifier of a transmitter to attenuate unwanted emissions on harmonic frequencies. This 7-element Low Pass Filter kit is based on the G-QRP technical notes, a design by Ed Wetherhold W3NQN.

## 2. Design

The design uses four capacitors and three inductors wound on toroids, and has 50-ohm input and output impedance. The small PCB has a 4-pin plug at its input and output. It is designed to fit onto the “Ultimate/2/3/3S” multi-mode QRSS/WSPR transmitter kits, but may of course be used as a LPF for other QRP transmitter designs. It also fits the relay-switched LPF kit.

The kit is supplied with high-quality low-loss class-1 dielectric (CC4) RF ceramic capacitors of the C0G type (NP0, meaning near-zero temperature drift).

## 3. Parts List

Please refer to the parts list below, for your band. Capacitor values are in picofarads (pf) except where indicated (600m and 2200m LF band values are in nanofarads) and the inductors L1-3 specify the number of turns to wind on the toroid. L1 and L3 are the same. L2 has the higher number of turns. The inductor value is indicated in brackets after the number of turns.

9Band | C1 | C2 | C3 | C4 | L1/L3 | L2 | Toroid
2200m | 2.2n//10n 4.7n//22n 4.7n//22n 2.2n//10n | 105 (54uH) | 105 (54uH) | T50-2 (red)
600m | 2.2n//2.2n | 10n | 10n | 2.2n//2.2n | 64 (20uH) | 70 (24uH) | T50-2 (red)
160m | 820 | 2200 | 2200 | 820 | 30 (4.44uH) | 34 (5.61uH) T50-2 (red)
80m | 470 | 1200 | 1200 | 470 | 25 (2.42uH) | 27 (3.01uH) T37-2 (red)
60m | 680 | 1200 | 1200 | 680 | 23 (2.12uH) | 24 (2.30uH) T37-2 (red)
40m | 270 | 680 | 680 | 270 | 21 (1.38uH) | 24 (1.70uH) T37-6 (yellow)
30m | 270 | 560 | 560 | 270 | 19 (1.09uH) | 20 (1.26uH) T37-6 (yellow)
20m | 180 | 390 | 390 | 180 | 16 (773nH) | 17 (904nH) | T37-6 (yellow)
17m | 100 | 270 | 270 | 100 | 13 (548nH) | 15 (668nH) | T37-6 (yellow)
15m | 82 | 220 | 220 | 82 | 12 (444nH) | 14 (561nH) | T37-6 (yellow)
12m | 100 | 220 | 220 | 100 | 12 (438nH) | 13 (515nH) | T37-6 (yellow)
10m | 56 | 150 | 150 | 56 | 10 (303nH) | 11 (382nH) | T37-6 (yellow)
6m | 22 | 82 | 82 | 22 | 7 (165nH) | 9 (265nH) | T37-6 (yellow)
4m | 10 | 56 | 56 | 10 | 6 (110nH) | 7 (150nH) | T37-6 (yellow)
2m | 22 | 33//10 | 33//10 | 22 | 3 | 3 | None (air)
222M | 22 | 33//10 | 33//10 | 22 | 2 | 2 | None (air)

The following table is the same except that it shows the capacitor marking. The capacitor markings usually use a three digit code, where the first two digits are the value and the 3rd digit is the number of zeroes of the capacitance in pico-farads. So for example, “560” = 56pF, “271” = 270pF and “472” = 4700pF (4.7nF). You may need a magnifying glass or jeweller's loupe to view the marked value clearly. The inductor value is indicated in brackets after the number of turns.

Band | C1 | C2 | C3 | C4 | L1/L3 | L2 | Toroid
2200m | 222+103 472+223 472+223 222+103 105 (54uH) 105 (54uH) T50-2 (red)
600m | 222+222 | 103 | 103 | 222+222 | 64 (20uH) | 70 (24uH) | T50-2 (red)
160m | 821 | 222 | 222 | 821 | 30 (4.44uH) | 34 (5.61uH) T50-2 (red)
80m | 471 | 122 | 122 | 471 | 25 (2.42uH) | 27 (3.01uH) T37-2 (red)
60m | 681 | 122 | 122 | 681 | 23 (2.12uH) | 24 (2.30uH) T37-2 (red)
40m | 271 | 681 | 681 | 271 | 21 (1.38uH) | 24 (1.70uH) T37-6 (yellow)
30m | 271 | 561 | 561 | 271 | 19 (1.09uH) | 20 (1.26uH) T37-6 (yellow)
20m | 181 | 391 | 391 | 181 | 16 (773nH) | 17 (904nH) | T37-6 (yellow)
17m | 101 | 271 | 271 | 101 | 13 (548nH) | 15 (668nH) | T37-6 (yellow)
15m | 820 | 221 | 221 | 820 | 12 (444nH) | 14 (561nH) | T37-6 (yellow)
12m | 101 | 221 | 221 | 101 | 12 (438nH) | 13 (515nH) | T37-6 (yellow)
10m | 560 | 151 | 151 | 560 | 10 (303nH) | 11 (382nH) | T37-6 (yellow)
6m | 220 | 820 | 820 | 220 | 7 (165nH) | 9 (265nH) | T37-6 (yellow)
4m | 100 | 560 | 560 | 100 | 6 (110nH) | 7 (150nH) | T37-6 (yellow)
2m | 220 | 330+100 | 330+100 | 220 | 3 | 3 | None (air)
222M | 220 | 330+100 | 330+100 | 220 | 2 | 2 | None (air)

## 4. Construction

Parts placement is defined by the printed legend on the PCB. Please refer to the parts placement diagram below. Note that all capacitor positions have space for 2 capacitors which are connected in parallel, this is to accommodate the required capacitance values for some Bands, which require two capacitors paralleled to make the right value. The PCB can also accommodate either 2.54mm spaced capacitor pins or 5.08mm (0.1 inch or 0.2 inch).

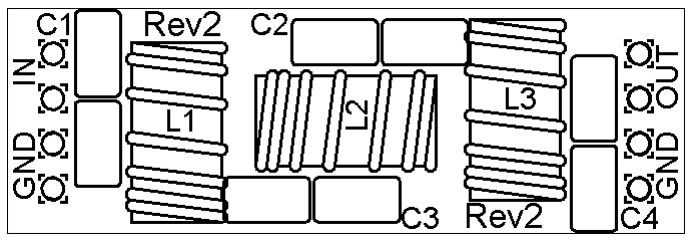
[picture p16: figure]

The PCB is quite small and the parts are close together. You are recommended to use a low wattage iron with a fine tip, and fine solder e.g. 1mm diameter or less. Take care not to overheat the PCB and risk damaging it. A well-lit area and magnifying glass may assist. Be careful not to bridge solder across closely-packed connections. I recommend checking with a DVM to make sure no solder bridges have been inadvertently created. Take care to ensure correct alignment of the 4-pin plugs.

Winding the toroids is quite straightforward, and the supplied wire should be enough for all three toroids, just divide it into three pieces. Remember that each time the wire goes through the centre of the toroid counts as one turn. You should aim to fill about 90% of the core (330-degrees). Leave a small gap between the winding ends, approx 10% of the core (30-degrees) to prevent capacitance effects between the ends. Labelling the toroids aids identification later! Trim the ends of the wire, scrape the enamel off and tin them with solder.

As an alternative to scraping the enamel off, my preferred method is to trim the wire ends back to 2mm below the board, then solder them with a small blob of solder. I hold the iron on the joint for 10 seconds. After about 7-8 seconds you can see the enamel bubble away and the solder sticks to the copper, making a good joint with the board. Check continuity on the board with a DVM.

At each capacitor position the PCB provides space for two capacitors in
parallel, required for the the LF band kits. For capacitors having 5mm
spaced wires, you can insert the capacitor wires into two holes as in the example (right).

Since it can be confusing to see which holes are used for the toroid wires, this image (below) paints red lines between the holes designed for the inductor wires.

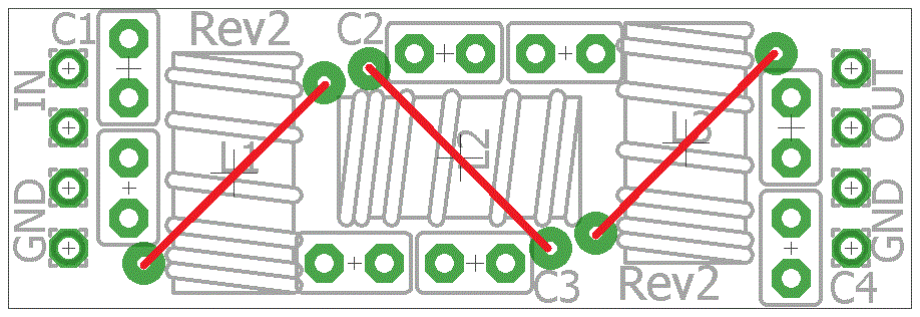
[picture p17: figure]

Note for 17m kit: the C1 and C4 capacitors should be 110pF according to the G-QRP web page, however I could not source a 110pF capacitor, so 100pF is used and should be a reasonable substitute.

## 5. Special notes for LF kits (600m and 2200m)

The capacitors in the LF kits are made up of two capacitors in parallel (see table 3). Make sure you put the correct capacitors in the correct positions. Where these capacitors come in 5mm wire spacing, you will need to straighten out the wires and fit them in the 2.5mm-spaced capacitor holes.

In all cases you are not going to be able to fit all of the turns on the inductor in a tidy single-layer winding. I have done tests where I wound the turns messy-style over each other and measured the inductance at every step. There is a chart of the results on the kit page (see resources section below). The practical measurements match closely with the theoretical values.

I think the best way to wind these coils is to try to wind the adjacent turns on top of each other in order to evenly distribute the total number of turns around the core, and leave a small gap between the start and finish of the winding. This appears to be to be the best way to construct the coil on a theoretical basis. So for example, if you want to wind the 105 turns of the 54uH core, then conceptually divide the core into 4 quarters, and aim to wind turns on top of each other to such an extent that you fit 21 turns onto each quarter. This should keep you roughly even as you wind.

Note that for the 105 turns you need nearly 2m of wire, and so you end up drawing through a long length of wire with each turn, that's a reasonable amount of physical work! My trick is to first drop the toroid onto the wire so that the toroid's first turn is at the centre of the wire. Then wind outwards towards one end of the wire, half the turns, onto half the core. Count as you go. Then go back to the other half of the wire, and wind that on. The end result is the same but rather than pulling 2m of wire through the core each turn, you only have to pull a maximum of 1m of wire.

In all cases for the LF kits, there are three lengths of wire, you do not need to cut them into three pieces! They are already measured (roughly with some spare) to fit the required number of turns. E.g. for the 2200m kit you have three lengths of wire, of approx 2m each.

If you have an LC meter then I think it's a good idea to wind 10 turns too many and then remove them until you get close to the target value. However I believe that even with no measurement, just winding by the numbers, you will still get an excellent result.

## 6. Special notes for 4m kit

The 4m LPF kit design is by Ken G4APB and also verified by QRP Labs. Please refer to http://qrplabs.com/lpfkit#4m (http://qrp-labs.com/lpfkit#4m) for measurements.

## 7. Special notes for 2m kit

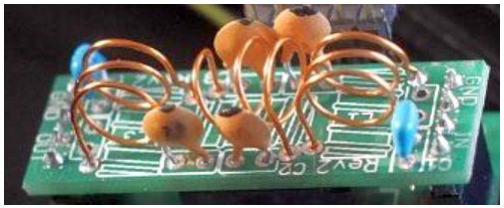
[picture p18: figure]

The 2m LPF kit design is by Tor
SM6FWF and also verified by
Rick NM3G. Please refer to http://qrp-labs.com/lpfkit#2m for measurements. The inductors are 3 turns of wire wound on a 6mm diameter air-core, as pictured (right). The middle coil should be a little longer (for lower inductance).

## 8. Special notes for 222MHz kit (same kit as 2m)

The 222MHz LPF kit design is by Rick NM3G and uses exactly the same components as the 2m LPF kit. The supplied kit is labelled “2m”. Only the inductor lengths are different. The 2m filter and testing results are described on this page http://qrp-labs.com/ultimate3/u3info/ultimate3222.html

The inductors should be constructed from three pieces of the supplied enamelled wire 1.43" (36mm) long. Strip and tin the ends 1/4" (6mm), and wind two turns around a 0.15" (5/16", 4mm) drill bit, before installation on the PCB. At 222MHz the length of wire making the inductor is much more important than the shape. So do not worry too much about the diameter or length of the coils.

## 9. Resources

Please see the kit page http://qrp-labs.com/lpfkit for information on latest updates and issues.

The G-QRP club LPF design: please see document on page: http://qrp-labs.com/lpfkit

Please join the QRP Labs group https://groups.io/g/QRPLabs for new kit announcements and to discuss any problems with the kit, enhancements you’ve made, or just to tell everyone how much fun you’re having.

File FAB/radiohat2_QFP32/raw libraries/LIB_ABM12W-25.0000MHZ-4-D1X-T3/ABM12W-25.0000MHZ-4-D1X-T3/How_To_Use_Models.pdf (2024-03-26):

ECAD PART WIZARD.

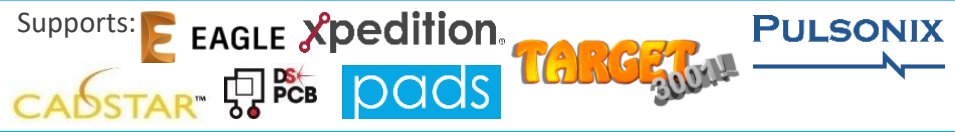
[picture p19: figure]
Supports:

Offers engineers full control of the symbol fracturing and symbol pin positions (left, right, top, bottom). ECAD Symbols & footprints can be downloaded directly from within the EPW application or from manufacturer and RS Component website.

DOWNLOAD: http://componentsearchengine.com/EPW.html

LIBRARY LOADER.
Allows Engineers to click our icon from any webpage and it injects the symbols and footprint directly into your chosen library and attached them to your cursor ready for placement.

DOWNLOAD: http://componentsearchengine.com/LibraryLoader.php

SamacSys is a leading developer of software tools for creating and managing electronic component ECAD data.

## 3 ways to use our ECAD Schematic Symbols & PCB footprints

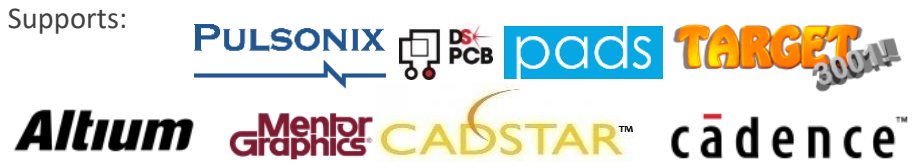
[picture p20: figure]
Supports:

DIRECT MODEL DOWNLOAD FOR MANUAL USE.
Our Schematic Symbols and PCB Footprint can be downloaded in a zip file for the user to manually load into their existing ECAD Library.

DOWNLOAD: http://componentsearchengine.com

Automatically load
models into your
library and attach
them to your cursor
by clicking our icon
on any website.

WATCH VIDEO (https://componentsearchengine.com/pcb-libraries.php)

Excel plug in. Search
for parts from within
Excel, customise the
fracturing and export
to your chosen ECAD
Tool.

WATCH VIDEO (http://www.samacsys.com/epw/)

You may download our
symbols & footprints in
the format of your
ECAD system for
manually loading into
your library.

MORE INFO (http://www.samacsys.com/pcb-part-libraries/)

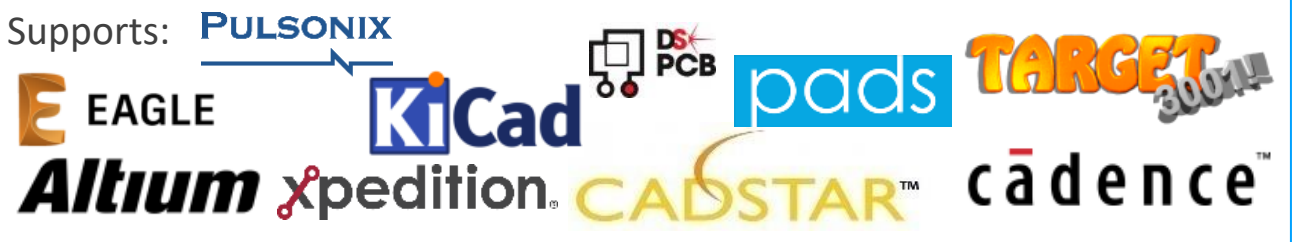
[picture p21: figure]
Supports:

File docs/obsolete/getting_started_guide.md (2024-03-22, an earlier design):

13-February-2022 by Mario Vano AE0GL
# Getting Started with *RadioHat*

This document describes one way to perform a simple installation of the *RadioHat* board onto a Raspberry Pi4, and add and operate the software needed to test it.

This is not meant to be a cookbook. The instructions assume you are familiar with downloading files, expanding them, and using the Raspberry Pi's command line interface. Be very careful with all connections to and from the Pi, as common causes of damage to Pi's include misconnection of wiring or application of incorrect voltages.

The procedures described here and this hardware are experimental and in the event of failures or errors may present some risk to the Pi - it's obviously not a good idea to use a "mission critical" board for this kind of work.

This guide was tested while it was being written using a Raspberry Pi4 with 4Gb of memory installed in a *Geekworm Passive Cooling* case and a 16Gb µSD card. Most other configurations should work just as well.

We are going to power the *RadioHat* from the Pi's on-board 5V supply. This is a simple way to confirm that the board is working, but for most uses, it is not a good way to power things. That 5V power is very noisy and will introduce some low frequency signals into the *RadioHat*'s receiver. We can  ignore this problem while we get started with the card.

### Prepare the Raspberry Pi and µSDHC card

* 	**Download and install** a copy of the latest 32 bit default release of Raspbian (*bullseye* at this time) into a 16Gb or 32Gb µSDHC card using the official *Raspberry Pi Imager* from [the RaspberryPi official web site](www.raspberrypi.com).

*	**Install the µSD card** into the Pi's SDHC slot, Boot up, test the installation and do basic configuration including setting display preferences, hostname, networking and a new password. Make sure it is working properly before going on.

### Install the *RadioHat* hardware

*	**Shut down** the operating system and Pi and unplug all cables.

*	**Jumper settings:** Install a bi-pin jumpers between pins 9 and 10 of J5 - the two pins closest to the GPIO connector edge of the board. If your board came with a jumper connected between pins 1 and 2 to protect the power pins, you can leave it installed. There should be no other jumpers installed on the board.

*	**Carefully plug the board** into the GPIO connector, ensuring that you've got all the pins plugged in properly and that the board is not resting on anything that would cause a short circuit. Some cases with oversize heatsinks require the use of an "extension" pass-through connector to raise the board safely off the heatsink. 

*	**Reconnect** your display, keyboard, mouse and any network cabling then carefully power up the board and see if it boots up normally. If you see any problem at all or if the lights on the end of the Pi away from the USB connectors don't begin blinking right away, power down immediately and resolve the problem before proceeding.

### Install software tools

You will need the following tools and libraries on your Pi:

1.	*git* repository manager
2.	*c++* Compiler
3.	*dtc* Device Tree Compiler
4.	*GnuRadio* with GnuRadio Companion
5.	*ncurses5* development library
6.	*WiringPi* development library

*git*, *c++* and *dtc* should already be present. If they are not, locate and install them.

Note that in newer versions of Raspbian the GnuRadio installation is now 3.8 instead of 3.7. This means that the *.py* files downloaded drom the *RadioHat* repository will no longer work since they were created by the older version.

Fortunately, if you open the corresponding *.grc* file for each *.py* file using *GnuRadio* and run it at least once, that file will be recreated for use with version 3.8 and will once again work as a stand alone program.

* **Install GnuRadio** from the Raspbian default repository using the command:

		sudo apt-get install libx11-dev
		sudo apt-get install gnuradio

* **Install ncurses5** with the command:

		sudo apt-get install libncurses5-dev

* **WiringPi** has become obsolete since the time *pitrans* was written, however, it is still needed for this software suite. This is probably not a bad thing, but we will have to work around it for now.

    You will need to install an open source replacement. The library name in c++ linker directives is now slightly different - use  *-lwiringPiDev* instead of *-lwiringpi*. Install this version using the following commands:

			cd ~/.Downloads
			git clone https://github.com/WiringPi/WiringPi.git
			cd wiringPi
			./build

### Download and install the *radiohat* folder

Make sure you are in your home directory (usually */home/pi*) and install the *radiohat* support tools folder there using one of the two procedures shown below. (Using git to clone the repository is the easiest and best way to do this).

Once you've done everything properly, you should have a folder named *radiohat* in your *pi* home directory containing the contents of the *radiohat* github repository. If it has any other name you may need to rename it before proceeding.

*	**install using *git*:**

		git clone https://github.com/mpvano/radiohat.git

*	**...or install by downloading a *.zip* file:**

	1. Start a web browser and type the same URL into its address bar. This should take you to the repository home page. Then, click on the green button labeled *Code*. A popup menu should appear containing several choices. Choose *Download zip*.

	2. When the download finishes, you should find a file named *radiohat-main.zip* in your Downloads folder. change your directory to the browser's *Downloads* folder and unzip that file using the command
	
			unzip radiohat-main.zip

	3. You should now see a folder called *radiohat-main* in your Downloads folder. Rename it to eliminate the suffix by using the command
	
			mv radiohat-main radiohat
	
	4. Confirm that this worked by using the *ls* command.

	5. Change back to your home directory and move the folder there using the commands:
	
			cd
			mv Downloads/radiohat .

### Install the Audio Codec Driver Overlay

The *RadioHat*'s audio codec uses drivers that are already present in Raspbian. It directs the operating system to use them by installing a file called a *Device Tree Overlay* into your *boot* folder. You must copy this overlay file to the folder where Raspbian keeps them. You will then add a line to *boot.txt* telling the operating system to use it.

After booting, the Audio Codec device  will appear in programs but it won't function properly until the devices on the *RadioHat* are initialized. For now, we're just going to manually initialize them by running the *pitrans* program.

Running *pitrans* needs to be done at least once after each reboot to initialize the codec chip so that it can be used as a sound interface. This can easily be automated, but for now, we're just going to do it manually since pitrans will be run alongside any other program we use to test *RadioHat*.

* **Install the overlay** by giving the following commands:

		cd ~/radiohat/RPI as\ SLAVE/ IIS\ setup/
		cd RaspberryPi_I2S_Slave-master/genericstereoaudiocodec.dtbo"
		sudo cp genericstereoaudiocodec.dtbo  /boot/overlays/genericstereoaudiocodec.dtbo

	These folder and file names look hard to type, but if you use the shell's tab expansion feature you can type just a few letters of each name and then hit the *Tab* key to do the rest of the work!

* **Add lines** to the Pi's */boot/config.txt* file

	Several lines need to be added to this file (which controls the Pi's startup options) to enable the *RadioHat's* devices. You can use either the *mousepad* or *nano* editor to do this, but you must run the editor using *sudo*. Here's how to do this using *mousepad*:

* **Open your editor** using the command:

		sudo mousepad /boot/config.txt

* **add the following lines** to the end of the file. (startup of the optional clock/calendar chip is shown disabled in this example):

		# *RadioHat* 1.0
		#for the optional rtc
		#dtoverlay=i2c-rtc,ds3231,addr=0x68
		dtparam=i2c=on
		dtparam=i2s=on
		dtoverlay=genericstereoaudiocodec

		# initialize the *RadioHat* GPIO
		gpio=22,23=op,dh
		gpio=17=a3

### Compiling the *pitrans* VFO and Codec control program

You must recompile *pitrans* at least once to ensure that it uses the correct libraries for your machine. It will probably just crash if you do not do this! These instructions will also be useful if you decide to make modifications to its behavior.

* **Compile** *pitrans* with these commands:

		cd ~/radiohat/pitrans1
		c++ pitrans.cpp si5351pi.cpp -lncurses -lwiringPiDev -lwiringPi

* You can optionally add *-D WWV=n* where *n* is *5*, *10* or *15* to the compilation command to more quickly check calibration by causing startup to  occur tuned to WWV.

* Once you're happy with the results, you can copy the resulting *a.out* to *pitrans*, *pitrans1* and/or *pitrans2* or these can be alternate versions:

		cd ~/radiohat/pitrans1
		cp a.out pitrans
		cp a.out pitrans1
		cp a.out pitrans2
		
* There is no longer any need to compile calibration settings into *pitrans* as it now looks for a file named *CALFACTOR.txt* in the directory it loads from. This file should contain only a single line with a correction value in parts per billion.

	As a starting point, it can be set to the offset value  written on the label adhered to the headphone jack of *RadioHead* during testing. The value on the label was measured using the si5351 load capacitance set for 8pf as specified by the crystal manufacturer. It's possible that by compiling with the load capacitance set to 10pf the correction required may be lower.

### Configure the clock/calendar option if installed

If you have the optional DS3231 clock calendar installed, and if you've uncommented the line we added to /boot/config.txt that loads its driver, then you should also edit (using *sudo*) the file */lib/udev/hwclock-set*.

Change:

		HWCLOCKPARS

to read:

		HWCLOCKPARS= --delay=0.7

### Testing

1. Connect a cellphone headset or a pair of headphones to the 3.5mm jack on *RadioHat*.
1. connect an antenna (or signal generator) to the RF IN connector

2. Power up the pi and recheck for proper operation. You can check the voltages and voltage regulator chip outputs on *RadioHat* for 1.8 and 3.3V. The 5V regulator will be inactive in this mode, but at least 4.5V should be present on power header's pin 9 (this is dropped about .4V by the series schottky diode on *RadioHat*.

3. You now should be able to run the following commands from two separate shells (to keep both displays open):

		~/radiohat/pitrans1/pitrans
		
	then:

		~/radiohat/headset.py
		(or open and run *headset.grc* from *gnuradio companion*)

	If all goes well, you will see a QT window that contains some simple controls and instrumentation graphs in a tabbed display and you may even hear signals at the frequency shown in the pitrans window.
	
	If you instead see audio errors in the parent shell window, you will need to troubleshoot the audio configuration. the *Audacity* editor should be of some use in doing this, since the RadioHead devices should work fine with it. The board defaults to feeding audio from the QSD to the input device in the *Audacity* audio editing program if you have it installed and accepting output from Audacity to send to the headset earpieces.
	
4.	Once everything is working, you should be able to **tune around** a bit using cursor keys to change the frequency control section of the pitrans window and keyboard commands to control its other features. In general, upper case letters increment values and lower case ones decrement them. Donʼt modify any pitrans audio controls for now.

5. If you have a load connected, you can experiment with **transmitting** using the *t* and *r* commands in *pitrans*. If you have a headset connected, its microphone and the microphone gain in *pitrans* work during transmit - otherwise the tone oscillator tab can be used to generate output.

6. connect the Pi to the internet

7. If you have the optional clock/calendar installed you can **do a quick check of it**.

	This command should show show the RTC time (probably wrong):

		sudo hwclock —verify

	You can set it with:

		sudo hwclock --systohc --delay=0.7

	It should then show up correctly in:

		timedatectl

### Fixing Pi Problems
* If you find GnuRadio Companion is lagging seconds behind mouse operations, you may need to disable the experimental 3D drivers that are turned on in the Piʼs config file by default. Do this by commenting out this line in your config.tx:

		#dtoverlay=vc4-fkms-v3d

*	In some versions of Raspbian, you may need to work around a bug that prevents launching shell scripts from the file manager. If you encounter this problem, try creating a fake copy of the missing terminal program like this:

		“sudo cp /usr/bin/lxterminal /usr/bin/xterm”

### Next steps

Obviously this configuration is just intended for use debugging hardware! These tools should not be delivered as end-user software. They do, however, contain what you usually need to run tests and take measurements, and even to try some awkward QSOʼs if you are connected to an amplifier board, low pass filter and TR switch.

*pitrans* supports adding an ads1115 based VSWR sensor that you can modify for scaling to display your amplifier's output.

There are a few other *gnuradio* DSP programs enclosed that use various generic USB devices for headset IO. If you use an additional headset/microphone device you won't need to share their Audio IO paths with the *RadioHat's* IQ signals, so there will be no need to worry about reconfiguring the Codec chip when going from receive to transmit.

The version called *USBDevice* works with most generic USB headset dongles and mini audio cards.

There are also two programs called *osc.grc* and *twotone.grc* that are useful in transmitter testing. They do not use any other analog IO, so they're quite low in distortion.

If you open the *.grc* file for one these programs using *GnuRadio* you can edit it and then by running it from that environment you will recreate an up-to-date standalone *.py* file.

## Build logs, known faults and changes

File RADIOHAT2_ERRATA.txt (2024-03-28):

ERRATA!!! ERRATA!!! ERRATA!!! ERRATA!!!

Note that part number for U14 - the TLV9064 quad op amp in the bill of materials for BOTH the radiohat2_QFP and radiohat 2 layouts IS INCORRECT.

The part number shown in the BOM for the digikey part is

TLV9064IPWR, CMOS Amplifier 4 Circuit Rail-to-Rail 14-TSSOP, 296-50014-1-ND

This was the intended part, but in the wrong package footprint! A 3.90mm width is what the layout intended!

TLV9064QDRQ1	IC CMOS 4 CIRCUIT 14SOIC 	296-TLV9064QDRQ1CT-ND

was what I intended

In fact, the prototypes were built and tested using 

TLV2464IDR		IC OPAMP GP 4 CIRCUIT 14SOIC	296-10608-1-ND

Which I happened to have in stock. FOR NOW, I suggest using this part - even though it's slightly more expensive as I have done no testing with the 9064 to confirm proper behavior.

I will attempt to resolve this issue before the next board revision is published...

Mario Vano
28-March-2024

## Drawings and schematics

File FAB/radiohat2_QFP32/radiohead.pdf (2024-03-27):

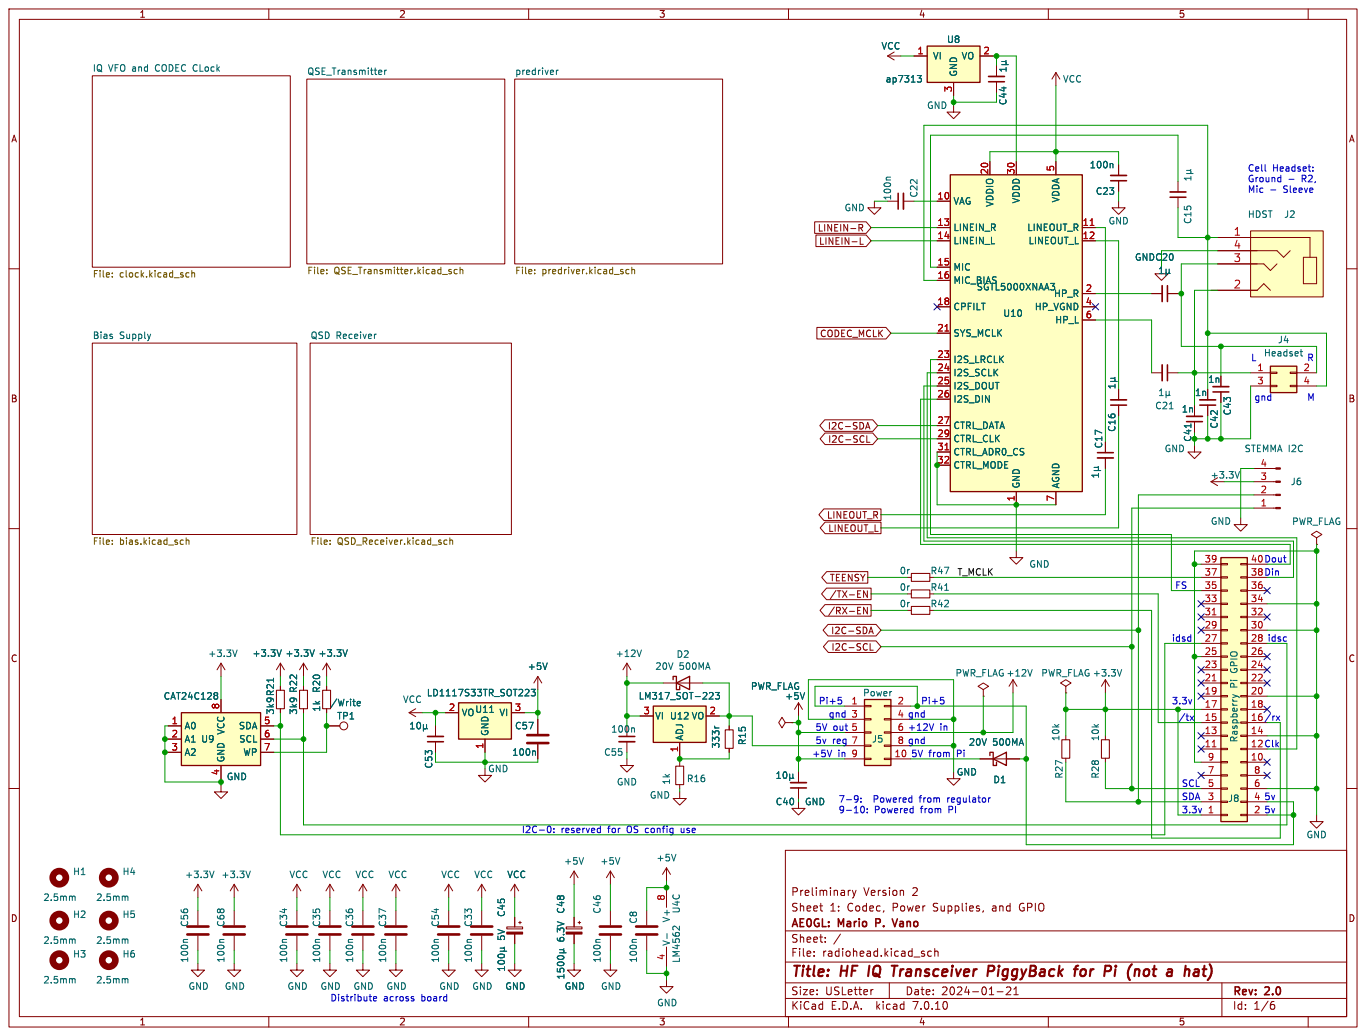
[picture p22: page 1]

7 U10 SGTL5000XNAA3 R15 333r 0r R42 +5V C8 100n +5V C48 þÿ1500µ6.3V C46 100n GND GND GND C33 100n GND GND GND 1kR16

GND GND GND GND C36 100n

8 R21 3k9 C45 þÿ100µ5V GND GND C48 þÿ1500µ6.3V C57
LM317_SOT-223 GND C68 100n GND

4 SDA 5 SCL 6 WP 7 VCC

5V from Pi 5V out +5V in
5v reg

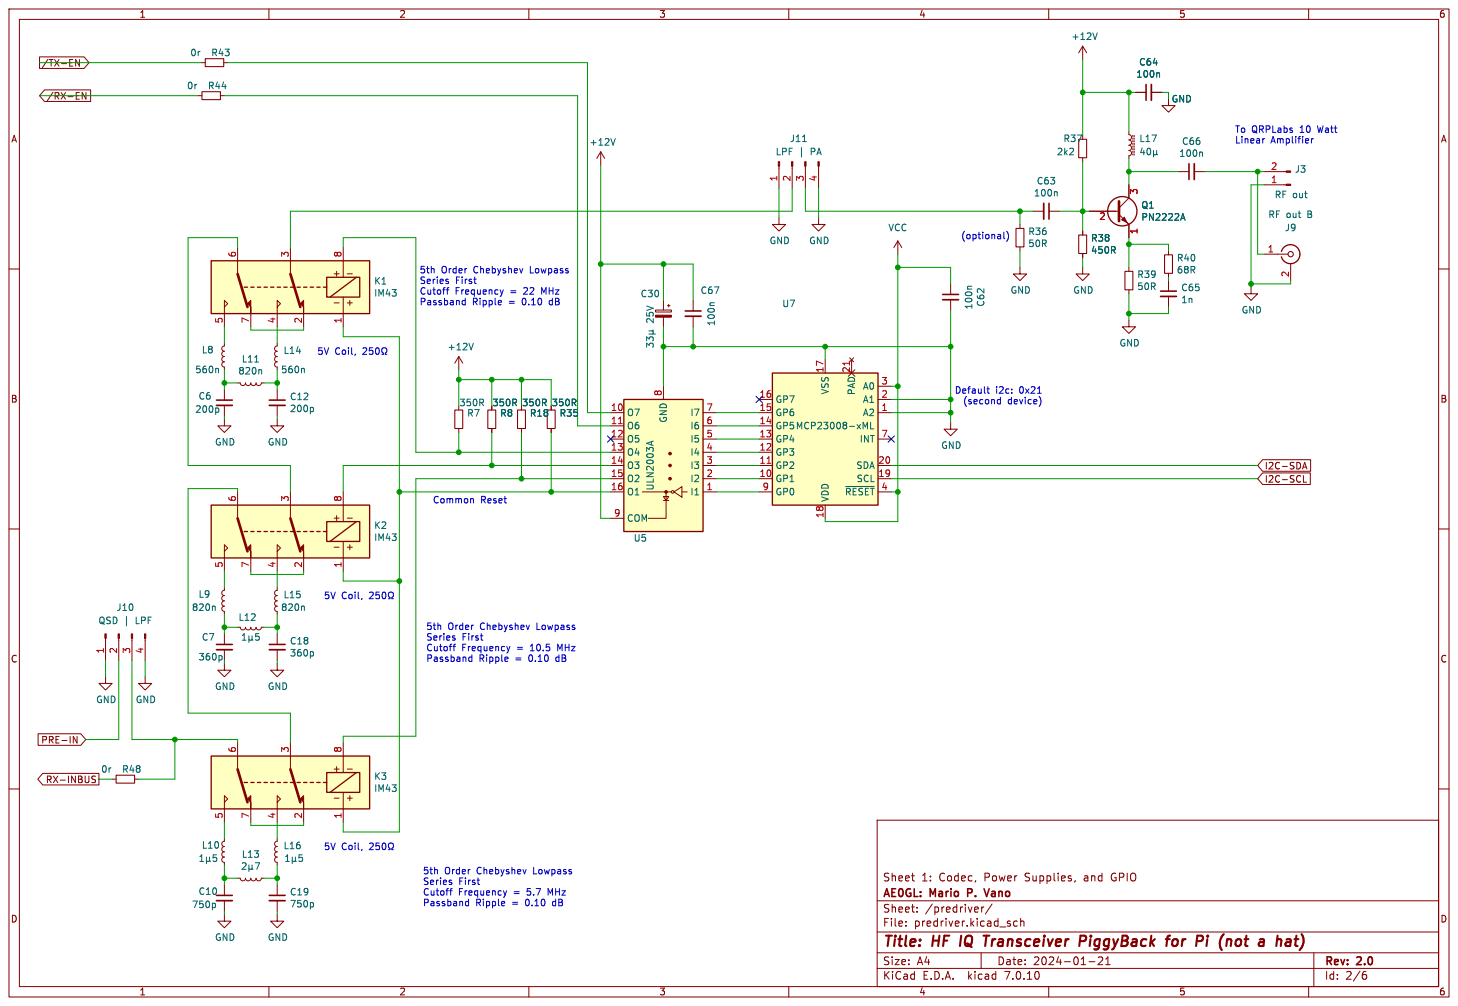
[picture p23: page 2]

5th Order Chebyshev Lowpass Series First Cutoff Frequency = 22 MHz Passband Ripple = 0.10 dB

5th Order Chebyshev Lowpass Series First Cutoff Frequency = 10.5 MHz Passband Ripple = 0.10 dBR35

Common Reset 5V Coil, þÿ250©

5th Order Chebyshev Lowpass Series First Cutoff Frequency = 5.7 MHz Passband Ripple = 0.10 dB

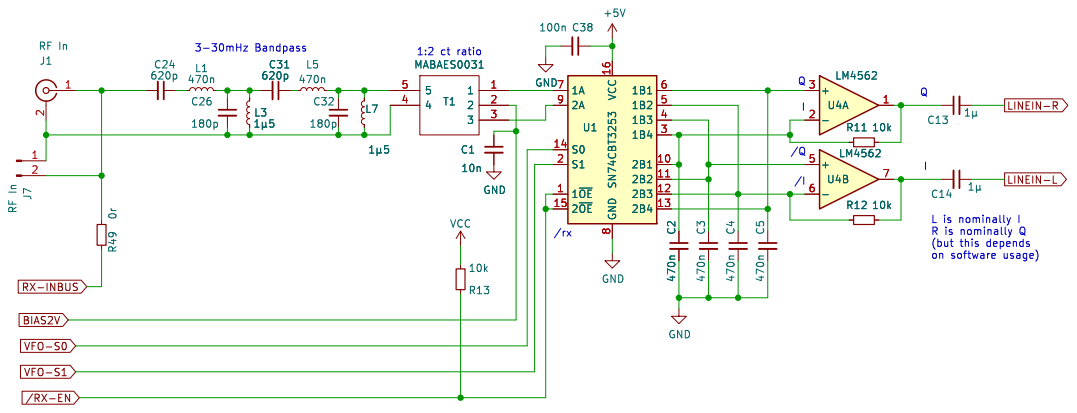
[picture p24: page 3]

(but this depends on software usage)

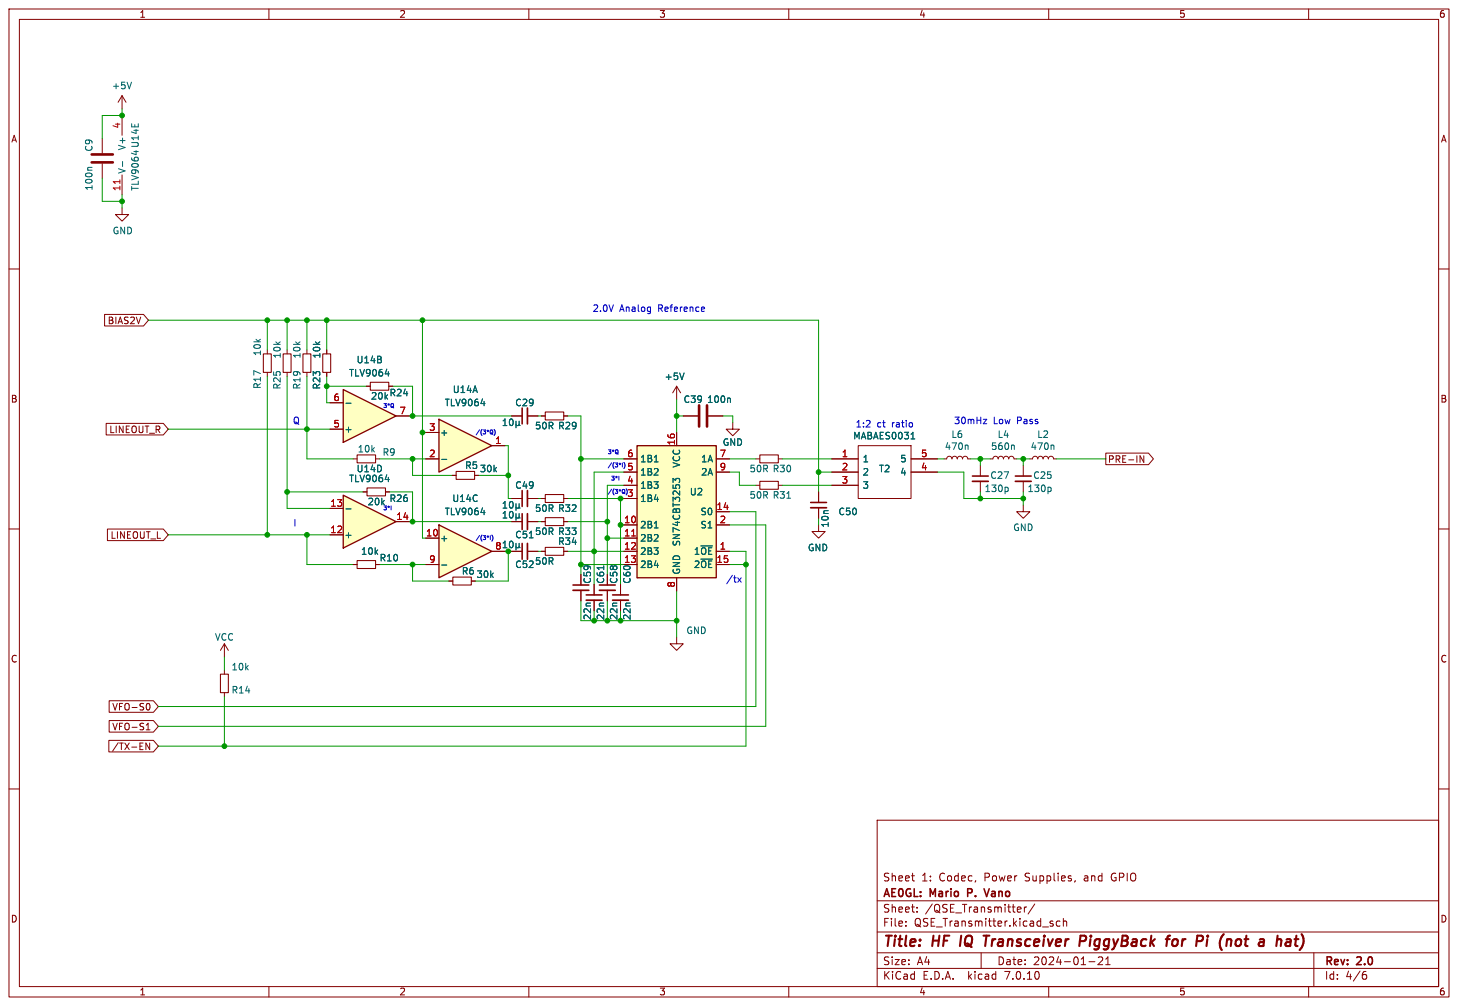
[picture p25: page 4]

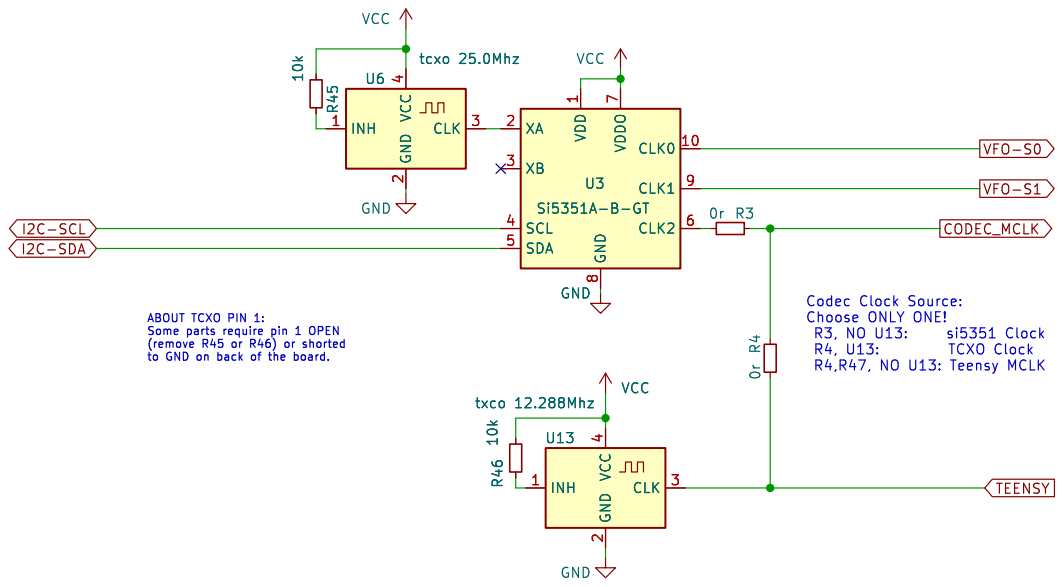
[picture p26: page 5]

8 CLK1 U3 9 Si5351A-B-GT VCC GND R45 10k R4 0r VCC

1 CLK0 10 XA 2 XB 3 SCL 4 SDA 5 CLK2 6 VDDO
U3 Si5351A-B-GT VDD

ABOUT TCXO PIN 1: Some parts require pin 1 OPEN

(remove R45 or R46) or shorted

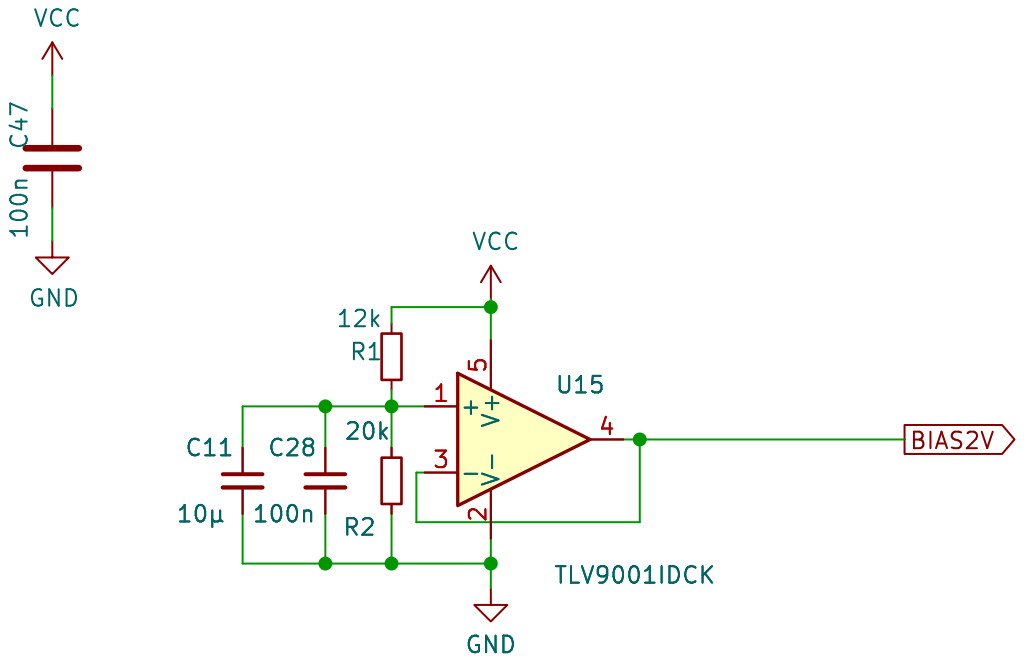
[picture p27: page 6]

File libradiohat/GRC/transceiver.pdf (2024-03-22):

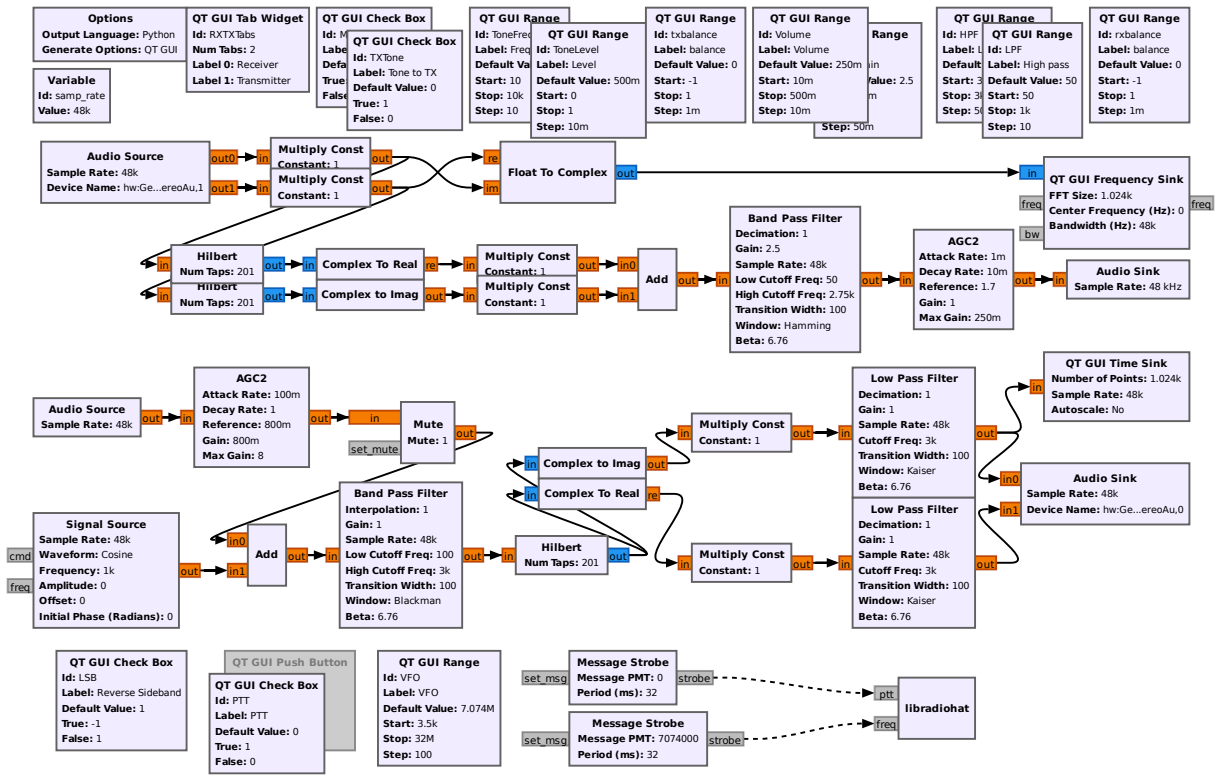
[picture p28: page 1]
Options; QT GUI; Range; Id: Gain Label: Gain Default Value: 2.5 Start: 30m Stop: 5 Step: 50m; False: 0; Variable Id: samp_rate Value: 48k; out; AGC2 Attack Rate: 1m Decay Rate: 10m Reference: 1.7 Gain: 1 Max Gain: 250m; AGC2 Attack Rate: 100m Decay Rate: 1 Reference: 800m Gain: 800m Max Gain: 8; Audio Sink; out0; out1; Audio Source; Audio Source Sample Rate: 48k; Add; Complex to Imag; Complex To Real; set_msg; strobe; Message Strobe Message PMT: 7074000 Period (ms): 32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

QT GUI Tab Widget
Id: RXTXTabs
Num Tabs: 2
Label 0: Receiver
Label 1: Transmitter

QT GUI Check Box
Id: MuteMic
Label: Mute Mic
Id: TXTone
Default Value: 1
Label: Tone to TX
True: 1
Default Value: 0
False: 0

QT GUI Range
Id: ToneFreq
Label: Freq
Default Value: 1k
Start: 10
Stop: 10k
Step: 10

Id: txbalance
Label: balance
Start: -1
Stop: 1
Step: 1m

Id: Volume
Label: Volume
Default Value: 250m
Start: 10m
Stop: 500m
Step: 10m

Id: HPF
Label: Low pass
Default Value: 2.75k
Start: 300
Stop: 3k
Step: 50

Id: rxbalance

Output Language: Python
Generate Options: QT GUI

Id: ToneLevel
Label: Level
Default Value: 500m
Start: 0

Id: LPF
Label: High pass
Default Value: 50
Start: 50
Stop: 1k

Float To Complex

Sample Rate: 48k
Device Name: hw:Ge...ereoAu,1

QT GUI Frequency Sink
FFT Size: 1.024k
freq
Center Frequency (Hz): 0
Bandwidth (Hz): 48k

Band Pass Filter
Decimation: 1
Gain: 2.5
Low Cutoff Freq: 50
High Cutoff Freq: 2.75k
Transition Width: 100
Window: Hamming
Beta: 6.76

Audio Sink
Sample Rate: 48 kHz

QT GUI Time Sink
Number of Points: 1.024k
Autoscale: No

Low Pass Filter
Gain: 1
Cutoff Freq: 3k
Window: Kaiser

Device Name: hw:Ge...ereoAu,0

Interpolation: 1
Low Cutoff Freq: 100
High Cutoff Freq: 3k
Window: Blackman

Signal Source
Waveform: Cosine
cmd
Frequency: 1k
Amplitude: 0
Offset: 0
Initial Phase (Radians): 0

Id: LSB
Label: Reverse Sideband
True: -1
False: 1

QT GUI Push Button

Id: VFO
Label: VFO
Default Value: 7.074M
Start: 3.5k
Stop: 32M
Step: 100

QT GUI Check Box Id: PTT Label: PTT Default Value: 0 True: 1 | Id: PTT Label: PTT Default Value: 0 Pressed: 1 Released: 0

set_msg | strobe

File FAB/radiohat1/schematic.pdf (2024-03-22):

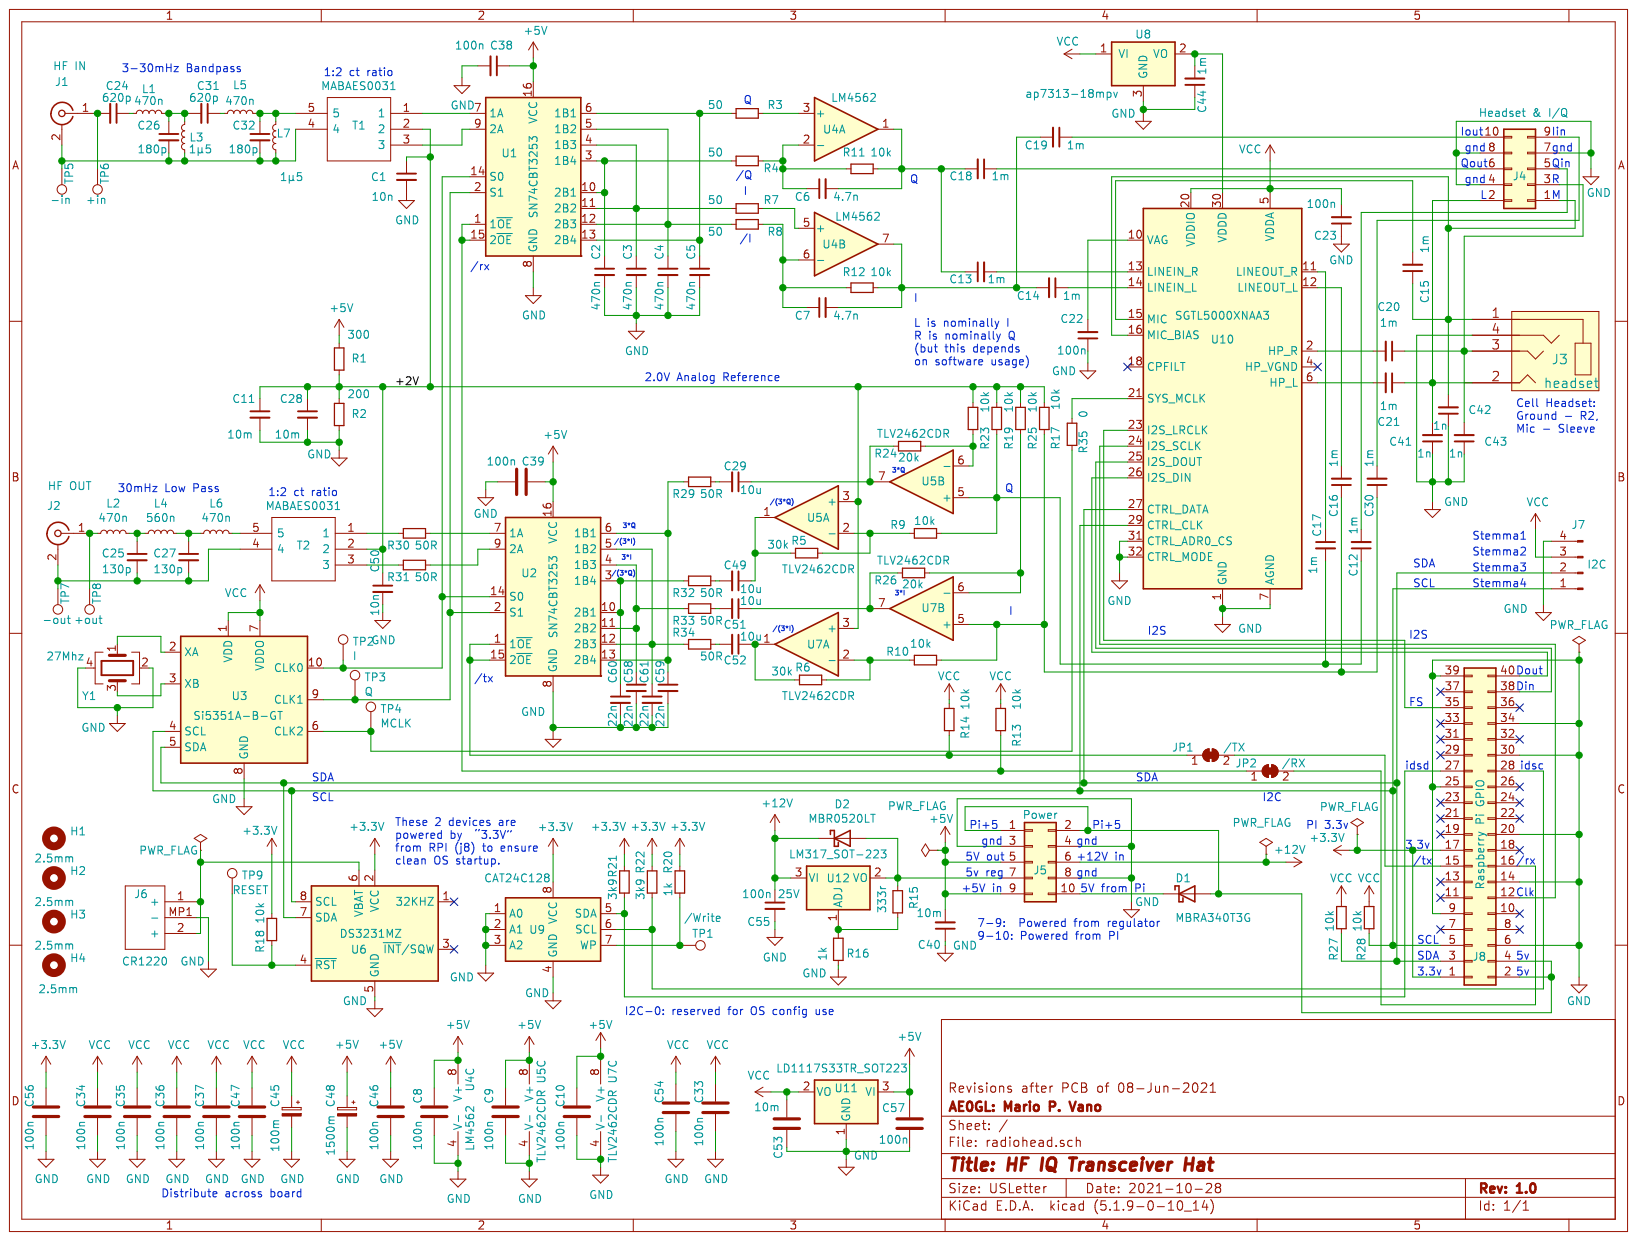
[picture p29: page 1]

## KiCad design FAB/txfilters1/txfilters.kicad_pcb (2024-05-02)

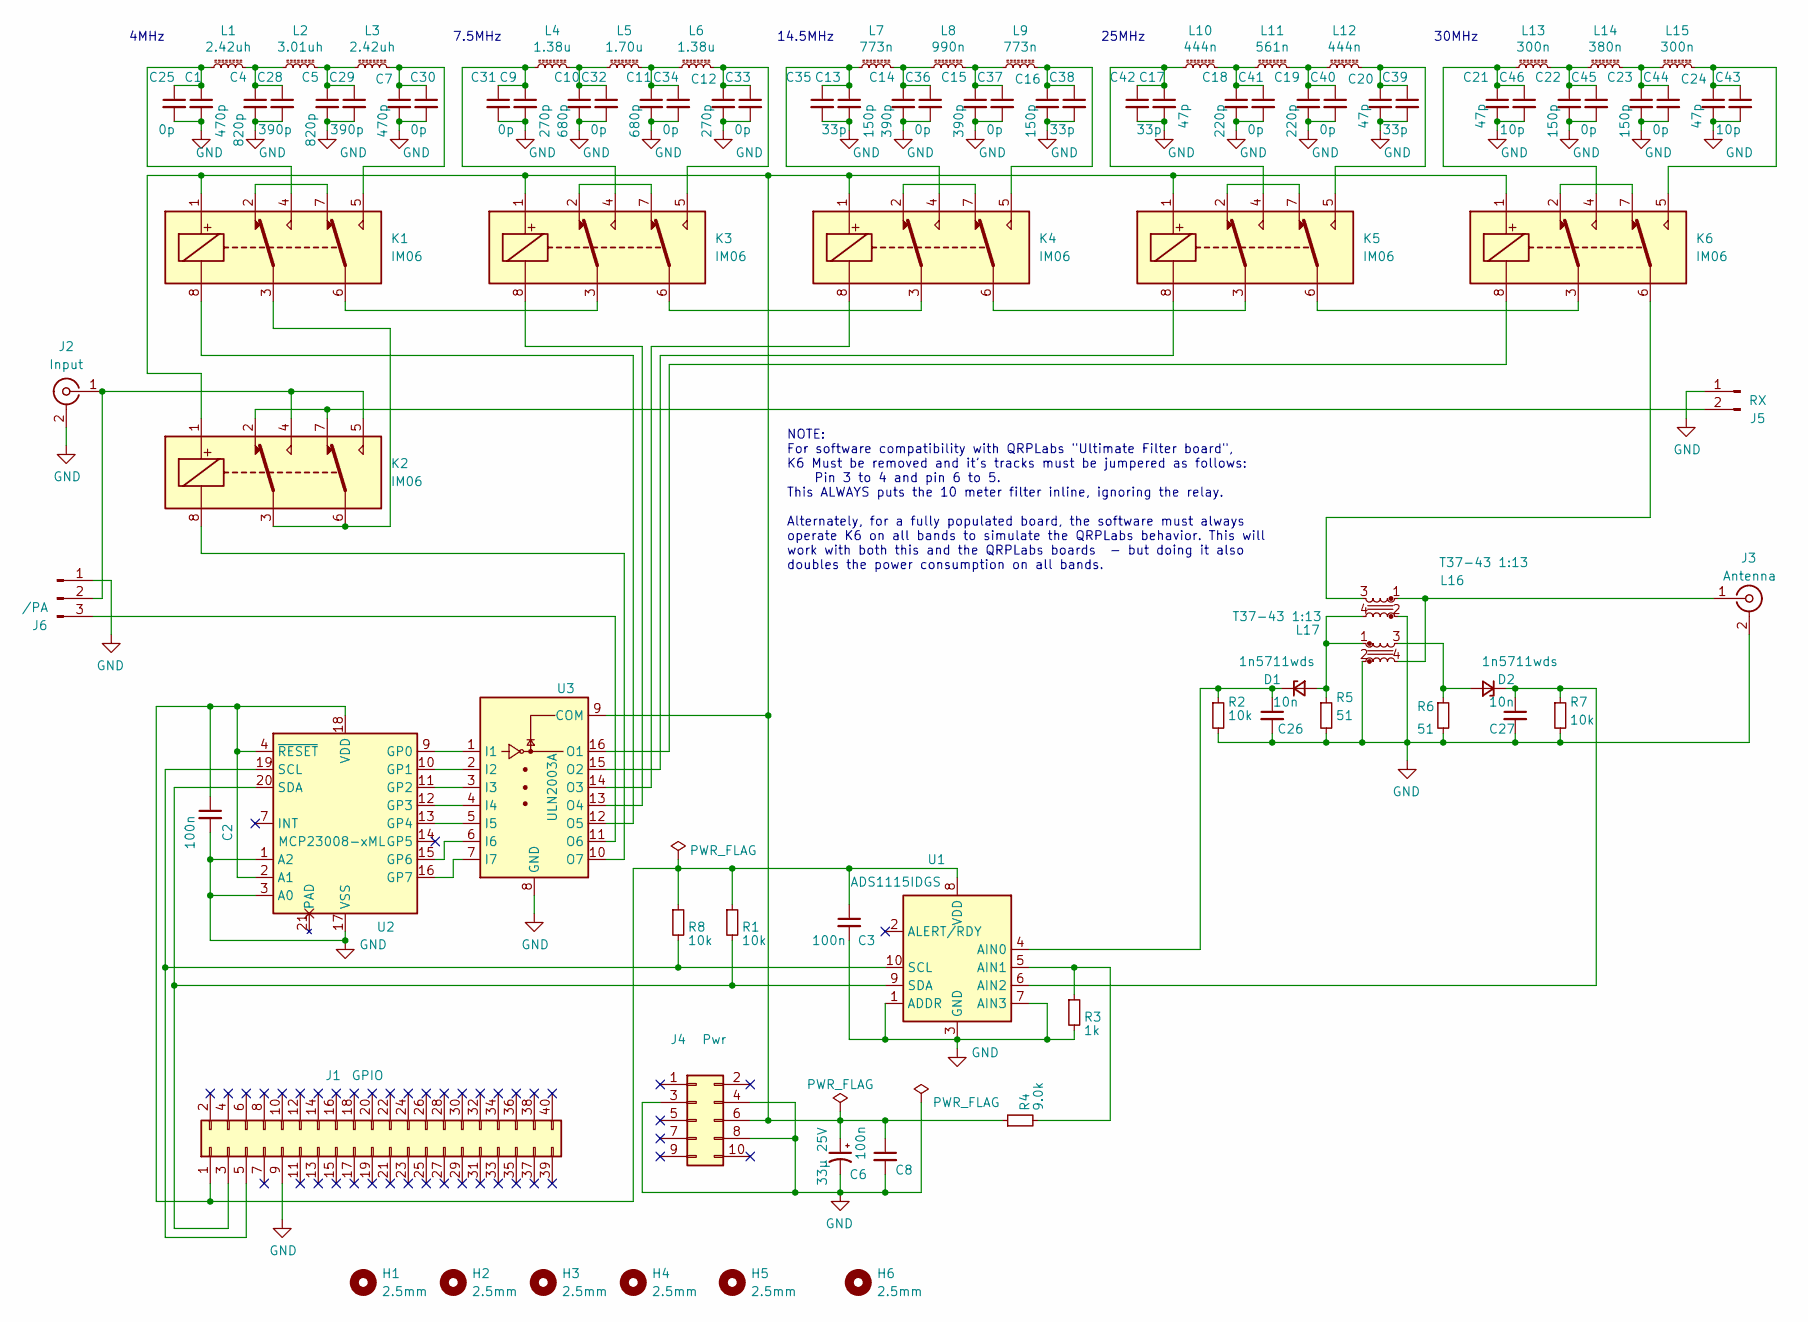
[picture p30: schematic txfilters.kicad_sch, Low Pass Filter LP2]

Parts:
C1, C7: 470p; C_1206_3216Metric; Manufacturer_Part_Number KGM31VCG2D471JU; DigiKey Part Number 478-KGM31VCG2D471JUCT-ND
C2, C3, C8: 100n; C_0603_1608Metric; Manufacturer_Part_Number CL10B104JB8NNNC; DigiKey Part Number 1276-1033-1-ND
C4, C5: 820p; C_1206_3216Metric; Manufacturer_Part_Number KGM31VCG2D821JU; DigiKey Part Number 478-KGM31VCG2D821JUCT-ND
C6: 33µ 25V; C_Elec_5x5.8; Manufacturer_Part_Number EEE-FK1E330UR; DigiKey Part Number PCE3802CT-ND
C9, C12: 270p; C_1206_3216Metric; Manufacturer_Part_Number KGM31BCG2D271JT; DigiKey Part Number 478-KGM31BCG2D271JTCT-ND
C10, C11: 680p; C_1206_3216Metric; Manufacturer_Part_Number KGM31VCG2D681JU; DigiKey Part Number 478-KGM31VCG2D681JUCT-ND
C13, C16, C22, C23: 150p; C_1206_3216Metric; Manufacturer_Part_Number KGM31BCG2D151JT; DigiKey Part Number 478-KGM31BCG2D151JTCT-ND
C14, C15, C28, C29: 390p; C_1206_3216Metric; Manufacturer_Part_Number KGM31BCG2D391JT; DigiKey Part Number 478-KGM31BCG2D391JTCT-ND
C17, C20, C21, C24: 47p; C_1206_3216Metric; Manufacturer_Part_Number KGM31BCG2D470JT; DigiKey Part Number 478-KGM31BCG2D470JTCT-ND
C18, C19: 220p; C_1206_3216Metric; Manufacturer_Part_Number KGM31BCG2D221JT; DigiKey Part Number 478-KGM31BCG2D221JTCT-ND
C25, C30, C31, C32, C33, C34, C36, C37, C40, C41, C44, C45: 0p; C_1206_3216Metric
C26, C27: 10n; C_0603_1608Metric; Manufacturer_Part_Number Samsung Electro-Mechanics; DigiKey Part Number 1276-1091-1-ND
C35, C38, C39, C42: 33p; C_1206_3216Metric; Manufacturer_Part_Number KGM31BCG2D330JT; DigiKey Part Number 478-KGM31BCG2D330JTCT-ND
C43, C46: 10p; C_1206_3216Metric; Manufacturer_Part_Number KGM31BCG2D100JT; DigiKey Part Number 478-KGM31BCG2D100JTCT-ND
D1, D2: 1n5711wds; D_SOD-323; Manufacturer_Part_Number 1N5711WS-7-F; DigiKey Part Number 1N5711WS-FDICT-ND
H1, H2, H3, H4, H5, H6: 2.5mm; MountingHole_2.7mm_M2.5_KA
J1: GPIO; PinSocket_2x20_P2.54mm_Vertical
J2: Input; SMA_Amphenol_132289_EdgeMount
J3: Antenna; SMA_Amphenol_132289_EdgeMount
J4: Pwr; PinSocket_2x05_P2.54mm_Vertical
J5: RX; JST_XH_B2B-XH-A_1x02_P2.50mm_Vertical
J6: /PA; JST_XH_B3B-XH-A_1x03_P2.50mm_Vertical
K1, K2, K3, K4, K5, K6: IM06; Relay_DPDT_AXICOM_IMSeries_Pitch5.08mm; Manufacturer_Part_Number 2-1462037; DigiKey Part Number PB1096-ND
L1, L3: 2.42uh; L_Toroid_Vertical_L14.0mm_W6.3mm_P4.57mm_Pulse_A
L2: 3.01uh; L_Toroid_Vertical_L14.0mm_W6.3mm_P4.57mm_Pulse_A
L4, L6: 1.38u; L_Toroid_Vertical_L14.0mm_W6.3mm_P4.57mm_Pulse_A
L5: 1.70u; L_Toroid_Vertical_L14.0mm_W6.3mm_P4.57mm_Pulse_A
L7, L9: 773n; L_Toroid_Vertical_L14.0mm_W6.3mm_P4.57mm_Pulse_A
L8: 990n; L_Toroid_Vertical_L14.0mm_W6.3mm_P4.57mm_Pulse_A
L10, L12: 444n; L_Toroid_Vertical_L14.0mm_W6.3mm_P4.57mm_Pulse_A
L11: 561n; L_Toroid_Vertical_L14.0mm_W6.3mm_P4.57mm_Pulse_A
L13, L15: 300n; L_Toroid_Vertical_L14.0mm_W6.3mm_P4.57mm_Pulse_A
L14: 380n; L_Toroid_Vertical_L14.0mm_W6.3mm_P4.57mm_Pulse_A
L16, L17: T37-43 1:13; Transformer_Toroid_Horizontal_D9.0mm_Amidon-T30
R1, R2, R7, R8: 10k; R_0603_1608Metric; Manufacturer_Part_Number RMCF0603FT10K0; DigiKey Part Number RMCF0603FT10K0CT-ND
R3: 1k; R_0603_1608Metric; Manufacturer_Part_Number RMCF0603FT1K00; DigiKey Part Number RMCF0603FT1K00CT-ND
R4: 9.0k; R_0603_1608Metric; Manufacturer_Part_Number RMCF0603FT9K09; DigiKey Part Number RMCF0603FT9K09CT-ND
R5, R6: 51; R_0603_1608Metric; Manufacturer_Part_Number RMCF0603FT51R0; DigiKey Part Number RMCF0603FT51R0CT-ND
U1: ADS1115IDGS; TSSOP-10_3x3mm_P0.5mm; Manufacturer_Part_Number ADS1115IDGSR; DigiKey Part Number 296-38849-1-ND
U2: MCP23008-xML; QFN-20-1EP_4x4mm_P0.5mm_EP2.7x2.7mm; Manufacturer_Part_Number MCP23008T-E/ML; DigiKey Part Number MCP23008T-E/MLCT-ND
U3: ULN2003A; SOIC-16_3.9x9.9mm_P1.27mm; Manufacturer_Part_Number ULN2003A; DigiKey Part Number 4518-ULN2003ACT-ND

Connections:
GND: C1.2, C2.2, C3.2, C4.2, C5.2, C6.2, C7.2, C8.2, C9.2, C10.2, C11.2, C12.2, C13.2, C14.2, C15.2, C16.2, C17.2, C18.2, C19.2, C20.2, C21.2, C22.2, C23.2, C24.2, C25.2, C26.2, C27.2, C28.2, C29.2, C30.2, C31.2, C32.2, C33.2, C34.2, C35.2, C36.2, C37.2, C38.2, C39.2, C40.2, C41.2, C42.2, C43.2, C44.2, C45.2, C46.2, J1.9, J2.2 (Ext), J3.2 (Ext), J4.3, J4.4, J4.8, J5.1, J6.1, L16.2, L17.2, R2.2, R3.2, R5.2, R6.2, R7.2, U1.1 (ADDR), U1.3 (GND), U1.7 (AIN3), U2.1 (A2), U2.3 (A0), U2.17 (VSS), U3.8 (GND)
unnamed: C1.1, C25.1, K1.4, L1.2
unnamed: C10.1, C32.1, L4.1, L5.2
unnamed: C11.1, C34.1, L5.1, L6.2
unnamed: C12.1, C33.1, K3.5, L6.1
unnamed: C13.1, C35.1, K4.4, L7.2
unnamed: C14.1, C36.1, L7.1, L8.2
unnamed: C15.1, C37.1, L8.1, L9.2
unnamed: C16.1, C38.1, K4.5, L9.1
unnamed: C17.1, C42.1, K5.4, L10.2
unnamed: C18.1, C41.1, L10.1, L11.2
unnamed: C19.1, C40.1, L11.1, L12.2
unnamed: C20.1, C39.1, K5.5, L12.1
unnamed: C21.1, C46.1, K6.4, L13.2
unnamed: C22.1, C45.1, L13.1, L14.2
unnamed: C23.1, C44.1, L14.1, L15.2
unnamed: C24.1, C43.1, K6.5, L15.1
unnamed: C4.1, C28.1, L1.1, L2.2
unnamed: C5.1, C29.1, L2.1, L3.2
unnamed: C7.1, C30.1, K1.5, L3.1
unnamed: C9.1, C31.1, K3.4, L4.2
unnamed: D1.2 (A), L16.4, L17.1, R5.1
unnamed: C26.1, D1.1 (K), R2.1, U1.4 (AIN0)
unnamed: D2.2 (A), L17.3, R6.1
unnamed: C27.1, D2.1 (K), R7.1, U1.6 (AIN2)
unnamed: C2.1, C3.1, J1.1, R1.1, R8.1, U1.8 (VDD), U2.2 (A1), U2.4 (~RESET), U2.18 (VDD)
unnamed: J1.3, R1.2, U1.9 (SDA), U2.20 (SDA)
unnamed: J1.5, R8.2, U1.10 (SCL), U2.19 (SCL)
unnamed: J2.1 (In), J6.2, K2.4, K2.5
unnamed: J3.1 (In), L16.1, L17.4
unnamed: C6.1, C8.1, J4.6, K1.1, K2.1, K3.1, K4.1, K5.1, K6.1, R4.1, U3.9 (COM)
unnamed: J5.2, K2.2, K2.7
unnamed: J6.3, U3.11 (O6)
unnamed: K1.2, K1.7
unnamed: K1.3, K2.3, K2.6
unnamed: K1.6, K3.3
unnamed: K3.2, K3.7
unnamed: K3.6, K4.3
unnamed: K4.2, K4.7
unnamed: K4.6, K5.3
unnamed: K5.2, K5.7
unnamed: K5.6, K6.3
unnamed: K6.2, K6.7
unnamed: K6.6, L16.3
unnamed: R3.1, R4.2, U1.5 (AIN1)
unnamed: U2.9 (GP0), U3.1 (I1)
unnamed: U2.10 (GP1), U3.2 (I2)
unnamed: U2.11 (GP2), U3.3 (I3)
unnamed: U2.12 (GP3), U3.4 (I4)
unnamed: U2.13 (GP4), U3.5 (I5)
unnamed: U2.15 (GP6), U3.6 (I6)
unnamed: U2.16 (GP7), U3.7 (I7)
unnamed: K6.8, U3.16 (O1)
unnamed: K5.8, U3.15 (O2)
unnamed: K4.8, U3.14 (O3)
unnamed: K3.8, U3.13 (O4)
unnamed: K1.8, U3.12 (O5)
unnamed: K2.8, U3.10 (O7)

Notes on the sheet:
30MHz
7.5MHz
25MHz
4MHz
14.5MHz
NOTE: For software compatibility with QRPLabs "Ultimate Filter board", K6 Must be removed and it's tracks must be jumpered as follows: Pin 3 to 4 and pin 6 to 5. This ALWAYS puts the 10 meter filter inline, ignoring the relay. Alternately, for a fully populated board, the software must always opera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

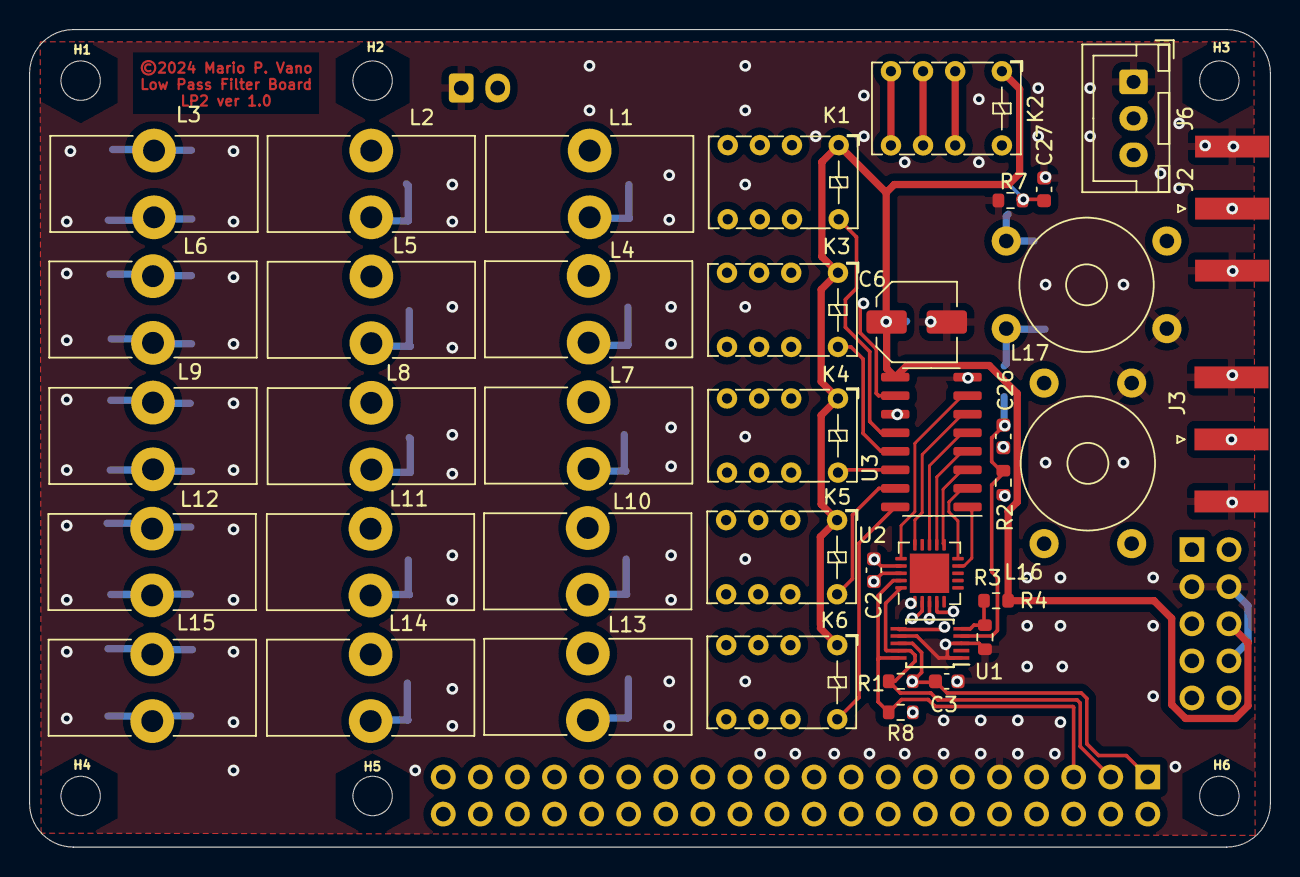
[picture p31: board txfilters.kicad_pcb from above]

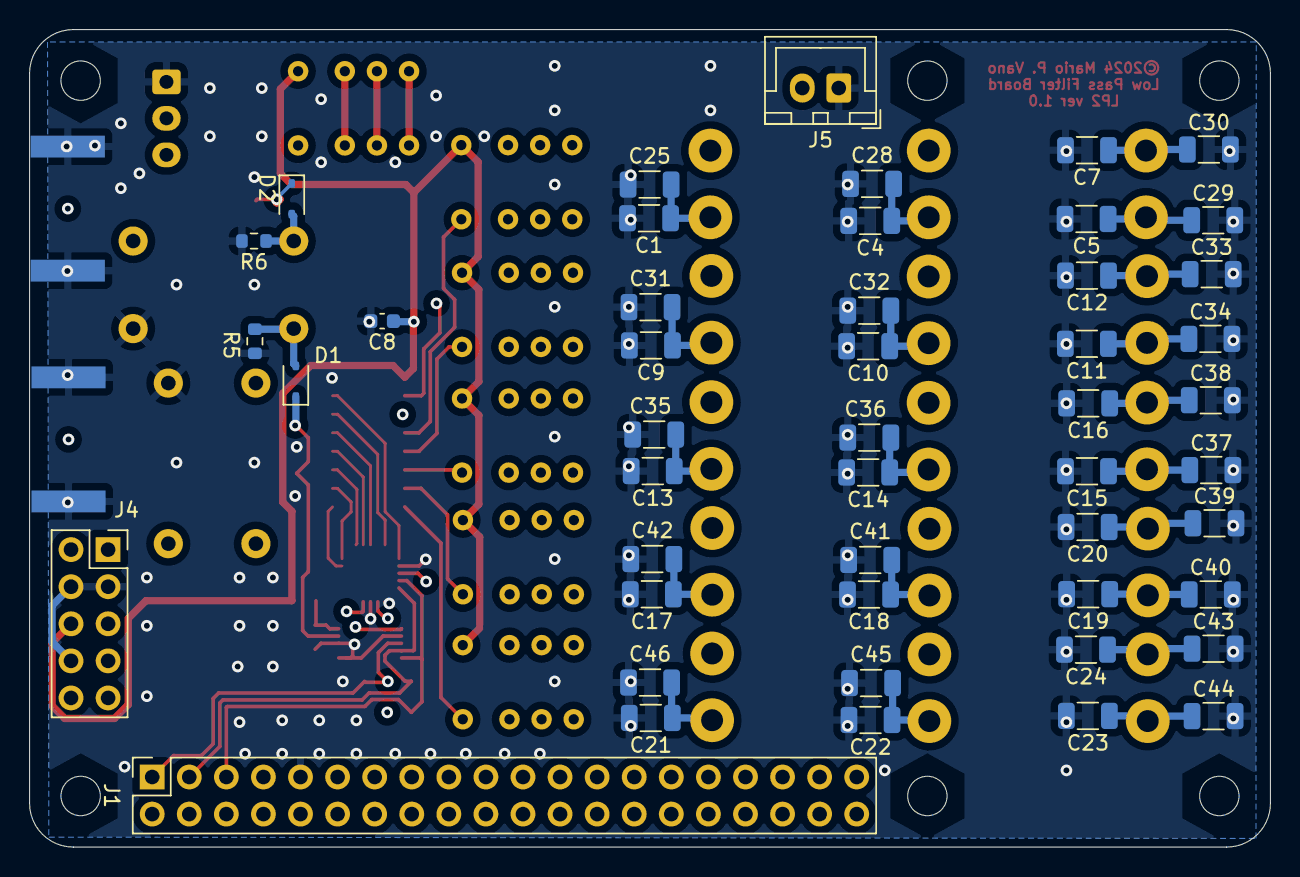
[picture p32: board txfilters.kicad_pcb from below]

Board: 4 copper layers, 85.0 x 56.0 mm, 94 parts (48 on the bottom side), 58 nets.

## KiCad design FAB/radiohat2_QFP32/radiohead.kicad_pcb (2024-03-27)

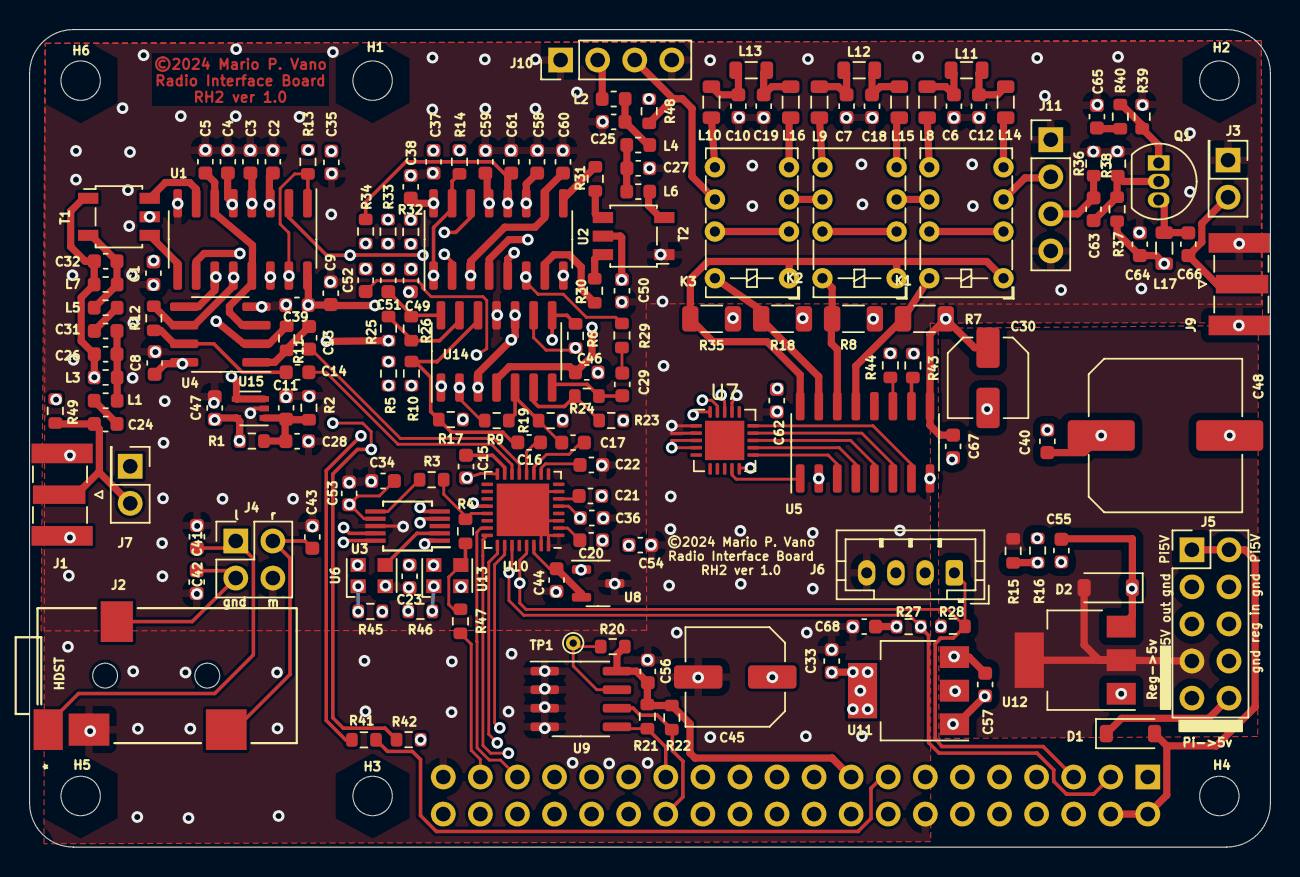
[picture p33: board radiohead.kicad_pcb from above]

Board: 4 copper layers, 85.0 x 56.0 mm, 175 parts (1 on the bottom side), 124 nets.

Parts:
C1, C50: 10n; C_0603_1608Metric
C2, C3, C4, C5: 470n; C_0603_1608Metric
C6, C12: 200p; C_0603_1608Metric
C7, C18: 360p; C_0603_1608Metric
C8, C9, C22, C23, C28, C33, C34, C35, C36, C37, C38, C39, C46, C47, C54, C55, C56, C57, C62, C63, C64, C66, C67, C68: 100n; C_0603_1608Metric
C10, C19: 750p; C_0603_1608Metric
C11, C29, C40, C49, C51, C52, C53: 10µ; C_0603_1608Metric
C13, C14, C15, C16, C17, C20, C21, C44: 1µ; C_0603_1608Metric
C24, C31: 620p; C_0603_1608Metric
C25, C27: 130p; C_0603_1608Metric
C26, C32: 180p; C_0603_1608Metric
C30: 33µ 25V; C_Elec_5x5.8
C41, C42, C43, C65: 1n; C_0603_1608Metric
C45: 100µ 5V; C_Elec_6.3x5.4
C48: 1500µ 6.3V; C_Elec_10x10.2
C58, C59, C60, C61: 22n; C_0603_1608Metric
D1, D2: 20V 500MA; D_SOD-123
H1, H2, H3, H4, H5, H6: 2.5mm; MountingHole_2.7mm_M2.5_KA
J1: RF In; SMA_Samtec_SMA-J-P-X-ST-EM1_EdgeMount
J2: HDST; SJ-43514TS-SMT
J3: RF out; PinHeader_2x01_P2.54mm_Vertical
J4: Headset; PinHeader_2x02_P2.54mm_Vertical
J5: Power; PinHeader_2x05_P2.54mm_Vertical
J6: STEMMA I2C; JST_PH_B4B-PH-K_1x04_P2.00mm_Vertical
J7: RF In; PinHeader_2x01_P2.54mm_Vertical
J8: Raspberry Pi GPIO; PinSocket_2x20_P2.54mm_Vertical
J9: RF out B; SMA_Samtec_SMA-J-P-X-ST-EM1_EdgeMount
J10: QSD | LPF; PinHeader_1x04_P2.54mm_Vertical
J11: LPF | PA; PinHeader_1x04_P2.54mm_Vertical
K1, K2, K3: IM43; Relay_DPDT_AXICOM_IMSeries_Pitch5.08mm
L1, L2, L5, L6: 470n; L_0603_1608Metric
L3, L7: 1µ5; L_0603_1608Metric
L4: 560n; L_0603_1608Metric
L8, L14: 560n; L_0805_2012Metric
L9, L11, L15: 820n; L_0805_2012Metric
L10, L12, L16: 1µ5; L_0805_2012Metric
L13: 2µ7; L_0805_2012Metric
L17: 40µ; L_0805_2012Metric
Q1: PN2222A; TO-92_Inline
R1: 12k; R_0603_1608Metric
R2, R24, R26: 20k; R_0603_1608Metric
R3, R4, R41, R42, R43, R44, R47, R48, R49: 0r; R_0603_1608Metric
R5, R6: 30k; R_0603_1608Metric
R7, R8, R18, R35: 350R; R_1206_3216Metric
R9, R10, R11, R12, R13, R14, R17, R19, R23, R25, R27, R28, R45, R46: 10k; R_0603_1608Metric
R15: 333r; R_0603_1608Metric
R16, R20: 1k; R_0603_1608Metric
R21, R22: 3k9; R_0603_1608Metric
R29, R30, R31, R32, R33, R34, R36, R39: 50R; R_0603_1608Metric
R37: 2k2; R_0603_1608Metric
R38: 450R; R_0603_1608Metric
R40: 68R; R_0603_1608Metric
T1, T2: MABAES0031; Transformer_MACOM_MABAES00031CT
TP1: /Write; TestPoint_THTPad_D1.0mm_Drill0.5mm
U1, U2: SN74CBT3253; SOIC-16_3.9x9.9mm_P1.27mm
U3: Si5351A-B-GT; MSOP-10_3x3mm_P0.5mm
U4: LM4562; SOIC-8_3.9x4.9mm_P1.27mm
U5: ULN2003A; SOIC-16_3.9x9.9mm_P1.27mm
U6: tcxo 25.0Mhz; Oscillator_SMD_Kyocera_KC2520Z-4Pin_2.5x2.0mm
U7: MCP23008-xML; QFN-20-1EP_4x4mm_P0.5mm_EP2.7x2.7mm
U8: ap7313; SOT-23-3
U9: CAT24C128; SOIC-8_3.9x4.9mm_P1.27mm
U10: SGTL5000XNAA3; QFN-32-1EP_5x5mm_P0.5mm_EP3.6x3.6mm
U11: LD1117S33TR_SOT223; SOT-223-3_TabPin2
U12: LM317_SOT-223; SOT-223-3_TabPin2
U13: txco 12.288Mhz; Oscillator_SMD_Kyocera_KC2520Z-4Pin_2.5x2.0mm
U14: TLV9064; SO-14_3.9x8.65mm_P1.27mm
U15: TLV9001IDCK; SOT-353_SC-70-5

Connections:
+3V3: C56.1, C68.1, J6.3, J8.1, J8.17, R20.2, R21.2, R22.2, R27.2, R28.2, U9.8 (VCC)
+5V: C8.1, C9.1, C38.1, C39.1, C40.2, C46.1, C48.1, C57.1, J5.5, J5.9, U1.16 (VCC), U2.16 (VCC), U4.8 (V+), U11.3 (VI), U14.4 (V+)
+12V: C30.1, C55.1, C64.1, C67.1, D2.1 (K), J5.6, L17.1, R7.1, R8.1, R18.1, R35.1, R37.1, U5.9 (COM), U12.3 (VI)
/T_MCLK: J8.37, R47.2
BIAS2V: C1.1, C50.1, R17.1, R19.2, R23.2, R25.2, T1.2, T2.2, U14.3 (+), U14.10 (+), U15.3 (-), U15.4
CODEC-DIN: J8.40, U10.26 (I2S_DIN)
CODEC-DOUT: J8.38, U10.25 (I2S_DOUT)
CODEC-LRCLK: J8.35, U10.23 (I2S_LRCLK)
CODEC-SCLK: J8.12, U10.24 (I2S_SCLK)
CODEC_MCLK: R3.2, R4.2, U10.21 (SYS_MCLK)
GND: C1.2, C2.2, C3.2, C4.2, C5.2, C6.2, C7.2, C8.2, C9.2, C10.2, C11.2, C12.2, C18.2, C19.2, C22.1, C23.1, C25.2, C27.2, C28.2, C30.2, C33.2, C34.2, C35.2, C36.2, C37.2, C38.2, C39.2, C40.1, C41.1, C42.1, C43.1, C44.1, C45.2, C46.2, C47.2, C48.2, C50.2, C53.1, C54.2, C55.2, C56.2, C57.2, C58.2, C59.2, C60.2, C61.2, C62.2, C64.2, C65.2, C67.2, C68.2, J2.4, J3.1, J4.4, J5.3, J5.4, J5.8, J6.4, J8.6, J8.9, J8.14, J8.20, J8.25, J8.30, J8.34, J8.39, J9.2 (Ext), J10.1, J10.4, J11.1, J11.4, R2.1, R16.2, R36.2, R38.2, R39.2, T2.4, U1.8 (GND), U2.8 (GND), U3.8 (GND), U4.4 (V-), U5.8 (GND), U6.2 (GND), U7.1 (A2), U7.2 (A1), U7.17 (VSS), U8.3 (GND), U9.1 (A0), U9.2 (A1), U9.3 (A2), U9.4 (GND), U10.1 (GND), U10.3 (GND), U10.7 (AGND), U10.31 (CTRL_ADR0_CS), U10.32 (CTRL_MODE), U10.33 (GND), U11.1 (GND), U13.2 (GND), U14.11 (V-), U15.2 (V-)
HPL: C21.1, C43.2, J2.2, J4.2
HPR: C20.1, C41.2, J2.3, J4.3
I2C-SCL: J6.1, J8.5, R28.1, U3.4 (SCL), U7.19 (SCL), U10.29 (CTRL_CLK)
I2C-SDA: J6.2, J8.3, R27.1, U3.5 (SDA), U7.20 (SDA), U10.27 (CTRL_DATA)
LINEIN-L: C14.1, U10.14 (LINEIN_L)
LINEIN-R: C13.2, U10.13 (LINEIN_R)
LINEOUT_L: C16.1, R10.1, R17.2, U14.12 (+)
LINEOUT_R: C17.2, R9.1, R19.1, U14.5 (+)
MIC-IN: C15.1, C42.2, J2.1, J4.1, U10.16 (MIC_BIAS)
unnamed: C6.1, L8.1, L11.2
unnamed: C7.1, L9.1, L12.2
unnamed: C10.1, L10.1, L13.2
unnamed: C12.1, L11.1, L14.1
unnamed: C13.1, R11.1, U4.1
unnamed: C14.2, R12.1, U4.7
unnamed: C18.1, L12.1, L15.1
unnamed: C19.1, L13.1, L16.1
unnamed: C24.1, L1.2
unnamed: C25.1, L2.1, L4.2
unnamed: C26.1, C31.2, L1.1, L3.1
unnamed: C27.1, L4.1, L6.2
unnamed: C29.1, R24.2, U14.7
unnamed: C29.2, R29.1
unnamed: C31.1, L5.2
unnamed: C32.1, L5.1, L7.1, T1.5
unnamed: C49.1, R5.2, U14.1
unnamed: C49.2, R32.1
unnamed: C51.1, R26.2, U14.14
unnamed: C51.2, R33.1
unnamed: C52.1, R6.2, U14.8
unnamed: C52.2, R34.1
unnamed: C65.1, R40.2
unnamed: D1.2 (A), J5.1, J5.2, J8.2, J8.4
unnamed: D1.1 (K), J5.10
unnamed: D2.2 (A), J5.7, R15.1, U12.2 (VO)
unnamed: C26.2, C32.2, J1.2 (Ext), J7.1, L3.2, L7.2, T1.4
unnamed: C24.2, J1.1 (In), J7.2, R49.1
unnamed: C66.2, J3.2, J9.1 (In)
unnamed: J8.15, R41.2
unnamed: J8.16, R42.2
unnamed: J8.27, R21.1, U9.5 (SDA)
unnamed: J8.28, R22.1, U9.6 (SCL)
unnamed: J10.3, K3.6, R48.2
unnamed: J11.2, K1.3
unnamed: C63.2, J11.3, R36.1
unnamed: K1.2, K1.7
unnamed: K1.4, L14.2
unnamed: K1.5, L8.2
unnamed: K1.6, K2.3
unnamed: K2.2, K2.7
unnamed: K2.4, L15.2
unnamed: K2.5, L9.2
unnamed: K2.6, K3.3
unnamed: K3.2, K3.7
unnamed: K3.4, L16.2
unnamed: K3.5, L10.2
unnamed: L6.1, T2.5
unnamed: C63.1, Q1.2 (B), R37.2, R38.1
unnamed: C66.1, L17.2, Q1.3 (C)
unnamed: Q1.1 (E), R39.1, R40.1
unnamed: R30.2, T2.1
unnamed: R31.2, T2.3
unnamed: T1.1, U1.7 (1A)
unnamed: C5.1, U1.6 (1B1), U1.13 (2B4), U4.3 (+)
unnamed: C4.1, R12.2, U1.5 (1B2), U1.12 (2B3), U4.6 (-)
unnamed: C3.1, U1.4 (1B3), U1.11 (2B2), U4.5 (+)
unnamed: C2.1, R11.2, U1.3 (1B4), U1.10 (2B1), U4.2 (-)
unnamed: T1.3, U1.9 (2A)
unnamed: R30.1, U2.7 (1A)
unnamed: C59.1, R29.2, U2.6 (1B1), U2.13 (2B4)
unnamed: C61.1, R34.2, U2.5 (1B2), U2.12 (2B3)
unnamed: C58.1, R33.2, U2.4 (1B3), U2.11 (2B2)
unnamed: C60.1, R32.2, U2.3 (1B4), U2.10 (2B1)
unnamed: R31.1, U2.9 (2A)
unnamed: R3.1, U3.6 (CLK2)
unnamed: U3.2 (XA), U6.3 (CLK)
unnamed: U5.1 (I1), U7.9 (GP0)
unnamed: U5.2 (I2), U7.10 (GP1)
unnamed: U5.3 (I3), U7.11 (GP2)
unnamed: U5.4 (I4), U7.12 (GP3)
unnamed: U5.5 (I5), U7.13 (GP4)
unnamed: U5.6 (I6), U7.14 (GP5)
unnamed: U5.7 (I7), U7.15 (GP6)
unnamed: K1.1, K2.1, K3.1, R35.2, U5.16 (O1)
unnamed: K3.8, R18.2, U5.15 (O2)
unnamed: K2.8, R8.2, U5.14 (O3)
unnamed: K1.8, R7.2, U5.13 (O4)
unnamed: R44.2, U5.11 (O6)
unnamed: R43.2, U5.10 (O7)
unnamed: R45.2, U6.1 (INH)
unnamed: R20.1, TP1.1, U9.7 (WP)
unnamed: C21.2, U10.6 (HP_L)
unnamed: C20.2, U10.2 (HP_R)
unnamed: C16.2, U10.12 (LINEOUT_L)
unnamed: C17.1, U10.11 (LINEOUT_R)
unnamed: C15.2, U10.15 (MIC)
unnamed: C22.2, U10.10 (VAG)
unnamed: C44.2, U8.2 (VO), U10.30 (VDDD)
unnamed: R15.2, R16.1, U12.1 (ADJ)
unnamed: R46.2, U13.1 (INH)
unnamed: R5.1, R9.2, U14.2 (-)
unnamed: R23.1, R24.1, U14.6 (-)
unnamed: R6.1, R10.2, U14.9 (-)
unnamed: R25.1, R26.1, U14.13 (-)
unnamed: C11.1, C28.1, R1.1, R2.2, U15.1 (+)
PRE-IN: J10.2, L2.2
RX-INBUS: R48.1, R49.2
TEENSY: R4.1, R47.1, U13.3 (CLK)
VCC: C23.2, C33.1, C34.1, C35.1, C36.1, C37.1, C45.1, C47.1, C53.2, C54.1, C62.1, R1.2, R13.2, R14.2, R45.1, R46.1, U3.1 (VDD), U3.7 (VDDO), U6.4 (VCC), U7.3 (A0), U7.4 (~RESET), U7.18 (VDD), U8.1 (VI), U10.5 (VDDA), U10.20 (VDDIO), U11.2 (VO), U13.4 (VCC), U15.5 (V+)
VFO-S0: U1.14 (S0), U2.14 (S0), U3.10 (CLK0)
VFO-S1: U1.2 (S1), U2.2 (S1), U3.9 (CLK1)
/RX-EN: R13.1, R42.1, R44.1, U1.1 (1~OE), U1.15 (2~OE)
/TX-EN: R14.1, R41.1, R43.1, U2.1 (1~OE), U2.15 (2~OE)

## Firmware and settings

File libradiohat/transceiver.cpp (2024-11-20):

/*	June 7, 2023 at 3:27:15 AM CDT
*****************************************************************************
*****************************************************************************
*
*	A simple example program for a Zero IF Quadrature transceiver
*	controller (DSP done elsewhere) using Si5351 for CLK0 and CLK1.
*
*	Based on ncurses and keyboard for all user IO interaction.
*
*	It accepts keypad based frequency control with left/right arrows
*	to highlight a digit and up/down arrows to adjust by that
*	digit's weight.
*
*	NOTE that this program requires a compatibly mutant version of
*	the great Etherkit Si5351 library modified for the desired
*	target platform - the original library ONLY works on Arduino.
*
*	This is gradually accumulating more bits and pieces for
*	testing the RadioHat board with a prototype full transceiver box.
*
*		Initializes sound card and controls TX-RX mode switching
*		Controls RX and TX GPIO for hat, relay driver, LPF board
* 		and Pwr Amp Controls and displays VSWR A/D readings
*
*		Still needs internal DSP and Audio plumbing setup for digital
*
*		If there is a file named "CALFACTOR.txt in the same directory
*		as the binary program file and if it contains a valid ascii
*		value for the VFO calibration factor, that will be used instead
*		of the default value compiled into the program.
*
*	started by Mario Vano AE0GL, February 2021 (and never finished)
*
******************************************************************************
*****************************************************************************/
#include <ncurses.h>
#include <math.h>
#include <unistd.h>
#include <stdlib.h>
#include <ctype.h>
#include <string.h>
#include <termios.h>

#include "radiohat.h"


//	GLOBALS from other modules (need to be eliminated!)
bool gLSBMode = false;			//	output polarities switch phase sequence
bool gNeedsVFOUpdate = false;	//	 used in some polled mode apps


//	controls stdio echo and line buffering behavior
void setRawConsole(void)
{
struct termios the_settings;

	tcgetattr(STDIN_FILENO,&the_settings);
		the_settings.c_lflag &= (~ICANON & ~ECHO) ;
	tcsetattr(STDIN_FILENO, TCSANOW, &the_settings);
}

void unsetRawConsole(void)
{
struct termios the_settings;

	tcgetattr(STDIN_FILENO,&the_settings);
	the_settings.c_lflag |= (ICANON | ECHO) ;
	tcsetattr(STDIN_FILENO, TCSANOW, &the_settings);
}


//	checks for a file called "CALFACTOR.txt" in same directory where the
//	program is located. If found and if it contains an ascii representation
//	of a signed long int it returns that value, otherwise it returns a default
//	from the vfo header file.
long getCalibrationFactorFromPath(char * progname)
{
long calfactor = CALIBRATION_FACTOR;
char * dirptr;
char configPath[128];
char buffer[128] =""; // Buffer to store data
FILE * theFile = NULL;

	strcpy(configPath,progname);
	dirptr = strrchr(configPath, '/');
	*dirptr = 0;
	strcat(configPath,"/CALFACTOR.txt");
	if ((theFile = fopen(configPath, "r")) != NULL)
		{
		int count = fread(&buffer, sizeof(char), 64, theFile);
		fclose(theFile);
		if (count)
			{
			long temp = strtol(buffer, NULL, 10);
			if ((temp < 100000) && (temp > -100000))
				calfactor = temp;
			}
  		}
  	return calfactor;
}


/*
******************************************************************************
*	A simple CAT transceiver control
*
*	(assumes raw console instead of ncurses)
*	start the program using socat like this (e.g.):
*
*		socat -d -d pty,raw,echo=0 \
*			exec:"/home/pi/radiohat/libradiohat/transceiver -c",pty,raw,setsid
*
*	The -d options will print the name of the pty on stderr.
*	Note that pty are assigned dynamically in order from 1,
*	so the pty number may vary depending on other pty
*	started ahead of this socat invocation!
*
*	(for debugging, add -v to echo all data to stderr)
*
*	emulates a subset of the Kenwood TS-480 CAT commands
*
*	Note that most commands send no response at all if args were supplied
*
*****************************************************************************/
bool cat_interface(void)
{
//	saved state of radio
//	kenwood radio modes
enum kKWMODE { KWLSB=1, KWUSB, KWCW, KWFM, KWAM, KWFSK, KWCW_R, KWFSK_R };
bool transmitter_on = false;
bool digitalMode = false;
bool cwMode = false;
long int VFOa = getVFO();
long int VFOb = getVFO();
int RXvfo = 0;		//	0 = VFOa, 1 = VFOb
int TXvfo = 0;
long int RIToffset = 0;
bool RITon = false;
bool XITon = false;
int DSPbw = 0;
int kw_mode = KWUSB;


//	state machine variables
enum CATSTATES { kIdle=0, kWaitForCommand1, kWaitForCommand2, kCollectParams };
char cmdbyte1, cmdbyte2;
const int kMaxCmdParmBytes = 32;
char cmdparms[kMaxCmdParmBytes];
int cmdParmCount = 0;
int cmdParmExpected = 0;
long int convertedParm = 0;
int catstate = kIdle;
int c;

#define CAT_ERROR_REPLY "?;"

	// could set up socat and open port here or let enclosing script do it

	setADCVol(0.5);
	while (true)
		{
		if (cwMode)			//	not presently useful because the loop blocks at getc
			checkKeydown();

		//	should add some kind of long timeout here to facilitate restarting
    	if ((c = getc(stdin)) > 0) switch (catstate)
			{
			case kIdle:
				catstate = kWaitForCommand1;
				cmdParmCount = cmdParmExpected = 0;
				cmdparms[0] = '\0';
				cmdbyte1 = cmdbyte2 = 0;
				convertedParm = 0;
				catstate = kWaitForCommand1;
				//	FALL THROUGH to process the received character

			//	waiting for first command letter
			case kWaitForCommand1:
				if (isalpha(c))
					{
					cmdbyte1 = toupper(c);
					catstate = kWaitForCommand2;
					}
				break;


			//	waiting for second command letter
			case kWaitForCommand2:
				if (isalpha(c))
					{
					cmdbyte2 = toupper(c);
					catstate = kCollectParams;	//	assume success!

					//	now check if legal command and set proper expected length
					if ((cmdbyte1 == 'A') && (cmdbyte2=='G'))
						cmdParmExpected = 4;	//	AF Gain
					else if  (cmdbyte1 == 'F')
						{
						switch (cmdbyte2)
							{
							case 'A':	cmdParmExpected = 11; break;	//	vfo A
							case 'B':	cmdParmExpected = 11; break;	//	vfo B
							case 'R':	cmdParmExpected = 1; break;		//	set RX VFO
							case 'T':	cmdParmExpected = 1; break;		//	set TX VFO
							case 'W':	cmdParmExpected = 4; break;		//	set DSP BW
							default:	catstate = kIdle; printf(CAT_ERROR_REPLY); break;
							}
						}
					else if  ((cmdbyte1 == 'I') && (cmdbyte2=='D'))
						cmdParmExpected = 0; 	//	send HW ID command (no args!)
					else if  ((cmdbyte1 == 'I') && (cmdbyte2=='F'))
						cmdParmExpected = 0; 	//	read info command (no args!)
					else if  ((cmdbyte1 == 'M') && (cmdbyte2=='D'))
						cmdParmExpected = 1; 	//	read mode command (no args!)
					else if  (cmdbyte1 == 'R') switch (cmdbyte2)
						{
						case 'D':	cmdParmExpected = 5; break;	//	RIT neg offset
						case 'T':	cmdParmExpected = 1; break;	//	RIT on or off
						case 'U':	cmdParmExpected = 5; break;	//	RIT pos offset
						case 'X':	cmdParmExpected = 0; break;//	RX func status
						default:	catstate = kIdle; printf(CAT_ERROR_REPLY); break;
						}
					else if  ((cmdbyte1 == 'T') && (cmdbyte2=='X'))
						cmdParmExpected = 1; 	//	TX command
					else { catstate = kIdle ; printf(CAT_ERROR_REPLY); }
					}
				else { catstate = kIdle; printf(CAT_ERROR_REPLY); }
				break;


			//	collecting generic params until ';'
			//	if terminator received: validate, parse and execute
			case kCollectParams:
				if (c != ';')			// we're not done yet
					{
					// must be digit or ';' and command must not exceed expectd length
					if ( (!isdigit(c)) || (cmdParmCount >=  cmdParmExpected) )
						 { catstate = kIdle; printf(CAT_ERROR_REPLY); }
					else
						{
						cmdparms[cmdParmCount++] = c;
						cmdparms[cmdParmCount] = 0;
						}	//	its an expected digit, just save it and continue
					}

				else //	got terminator - parse, execute if we can only reply to queries
					{
					catstate = kIdle;				//	finished, one way or another
					convertedParm = atol(cmdparms);	//	convert from string

					// volume setting?
					if ((cmdbyte1 == 'A') && (cmdbyte2=='G'))	//	AF Gain
						{
						int v;
						if (cmdParmCount)
							{
							if (convertedParm <= 255)
								{
								v = (convertedParm * 100) / 255;
								setHpVol(v);
								}
							}
						else {
							v = (getHpVol() * 255)/99;
							printf("%c%c%04i;", cmdbyte1, cmdbyte2, v);
							}
						}

					// VFO command?
					//	for now, always just use VFOa
					else if  (cmdbyte1 == 'F') switch (cmdbyte2)
						{
						case 'A':	//	vfo A
						case 'B':	//	vfo B		//	for now only 1 vfo
							if (cmdParmCount)
								{
								VFOa = VFOb = convertedParm;
								if (VFOa < 3300000L) VFOa = 3300000L;
								if (VFOa > 32000000L) VFOa = 32000000L;
								setVFO(VFOa);
								checkLPF(VFOa, false);
								}
							else printf("%c%c%011li;", cmdbyte1, cmdbyte2, VFOa);
							break;

						case 'R':	//	switch RX VFO to VFO A or B
						case 'T':	//	set TX VFO to VFO A or B
							if (cmdParmCount)
								RXvfo = TXvfo = 0;		//	both use VFO A for now
							else printf("%c%c%1i;", cmdbyte1, cmdbyte2, RXvfo);
							break;

						// FIXME: The arguments need far more mode dependent checking!!!
						case 'W':	//	set DSP BW
							if (cmdParmCount)
								DSPbw = convertedParm;
							else printf("%c%c%03i;", cmdbyte1,cmdbyte2, DSPbw);
							break;

						default:
							catstate = kIdle;
							printf("CAT_ERROR_REPLY");
							break;
						}

					// HW ID command?
					//	read-only info command (no args!)
					else if  ((cmdbyte1 == 'I') && (cmdbyte2=='D'))
						printf("%c%c%s;",cmdbyte1, cmdbyte2, "020");

					// info command?
					//	read-only info command (no args!)
					//	WE  return	"IF00007074000     +00000000002000000 ;"
					else if  ((cmdbyte1 == 'I') && (cmdbyte2=='F'))
						printf("%c%c%011li     %c%04li%01i%01i000%01i%01i%s;",
								cmdbyte1, cmdbyte2,
								VFOa, (RIToffset >= 0 ? '+' : '-'),
								abs(RIToffset), RITon, XITon,
								transmitter_on, kw_mode,
								"000000 ");	//	dummies for the rest

					// mode command
					else if  ((cmdbyte1 == 'M') && (cmdbyte2=='D'))
						{
						if (cmdParmCount)
							{
							switch(convertedParm)
								{
								case KWLSB:
									cwMode = false;
									digitalMode = false;
									swapPhaseVFO(true);
									gLSBMode = true;
									break;

								case KWUSB:
									cwMode = false;
									digitalMode = false;
									swapPhaseVFO(false);
									gLSBMode = false;
									break;

								case KWCW:
									cwMode = true;
									digitalMode = false;
									swapPhaseVFO(false);
									gLSBMode = false;
									break;

								case KWFM:
								case KWAM:
								case KWFSK:
									digitalMode = false; // true enables DTR keying
									swapPhaseVFO(false);
									gLSBMode = false;
									break;

								case KWCW_R:
									cwMode = false;
									digitalMode = false;
									swapPhaseVFO(true);
									gLSBMode = true;
									break;

								case KWFSK_R:
									cwMode = false;
									digitalMode = false;
									swapPhaseVFO(true);
									gLSBMode = true;
									break;

								default:
									break;
								}
							kw_mode = convertedParm;
							}
						else printf("%c%c%01i;", cmdbyte1, cmdbyte2, kw_mode);
						}

					// RIT command?
					else if  (cmdbyte1 == 'R') switch (cmdbyte2)
						{
						case 'D':	//	RIT neg offset
							if (cmdParmCount)
								RIToffset = -(convertedParm);
							else if (--RIToffset < -99999)
									RIToffset = -99999;
							break;
						case 'T':	//	RIT on or off
							if (cmdParmCount)
								RITon = (convertedParm == 1);
							else printf("%c%c%01i;", cmdbyte1, cmdbyte2, RITon==1);
							break;
						case 'U':	//	RIT pos offset
							if (cmdParmCount)
								RIToffset = convertedParm;
							else if (++RIToffset > 99999)
									RIToffset = 99999;
							break;
						case 'X':	//	RX func status  transmitter off
							transmitter_on = false;
							enableTX(transmitter_on, NORMAL_AUDIO);
							break;
						default:
							{ catstate = kIdle; printf("CAT_ERROR_REPLY"); }
							break;
						}

					// Transmit command?
					//	note peculiar parameter semantics:
					//		Always transmit regardless of Parm1 presence or value
					//		and always return TX0; regardless of param actually sent
					else if  ((cmdbyte1 == 'T') && (cmdbyte2=='X'))
						{
						transmitter_on = true;
						if (cmdParmCount==0) digitalMode = 0;
						else digitalMode = (cmdparms[0] == '1');
						enableTX(	transmitter_on,
									digitalMode ? DIGITAL_AUDIO : NORMAL_AUDIO);
						}

					// None of the above!
					else { catstate = kIdle; printf(CAT_ERROR_REPLY); }

					fflush(stdout);
					}
				break;
			}	//	of state machine switch statement

		}
	return true;
}




/*
******************************************************************************
*	a simple ncurses frequency control keyboard UI
*
*	controls:
*		Frequency and LPF switching
*		USB/LSB VCO phasing and display
*		TX/RX switching
*		VSWR display
*
*		Volume
*		Digital mode
*		TX Gain
*		Digital TX gain
*
*	need to add:
*
*		Transverter OFFSET
*		OUT OF BAND TX PREVENTION
*		Modes: USB/LSB/NBFM/CW
*		Filter settings
*		S Meter
*		AGC mode
*		Keyer, Key type and Keyer Speed
*		Second VFO
*
*	And need to add support for external keying sources
*	and control via virtual RS232 and CAT.
*
*****************************************************************************/
bool vfo_interface(void)
{
#define HZ_COLUMN 11
#define HZ_LINE 3
#define TXRX_LINE 2
#define MENU_LINE 0
#define GAIN_LINE 1
bool volume_changed = true;
bool transmitter_on = false;
bool digitalMode = false;
bool cwMode = false;
long int rx_freq = getVFO();
int c;
int weight = 2;
int current_column = HZ_COLUMN - weight;
static long int weights[] = { 1L,10L,100L,1000L,10000L,
								100000L,1000000L,10000000L };
const int num_weights = sizeof(weights)/sizeof(*weights);

	//	draw initial display
    move(MENU_LINE,0);
    addstr("[>]Usb [<]Lsb [C]w [F]t8 [T]x [R]x [Q]uit");
    move(GAIN_LINE,0);
    printw("GAIN: [H]p%2.0f [L]o%2.0f [M]ic%2.0f [D]ac%2.0f [A]dc%2.0f a[G]c%2.0f",
			getHpVol(),getLoVol(),getMicVol(),getDACVol(),getADCVol(),getAGCLevel());
	move(TXRX_LINE,0);
	addstr("USB: Receive              ");
	move(HZ_LINE,0);
	printw("VFO %8i",rx_freq);
	move(HZ_LINE,current_column);
	refresh();

	while (true)
		{
		if (cwMode)
			checkKeydown();
		else if (digitalMode)
			{
			transmitter_on = isTXRequested();
			enableTX(transmitter_on, DIGITAL_AUDIO);
			}

    	if ((c = getch()) > 0)
			{
			switch (c)
				{
				case 'A':
				case 'a':
					setADCVol(getADCVol() + (isupper(c) ? 1 : -1));
					volume_changed = true;
					break;

				case 'c':
				case 'C':
					cwMode = ! cwMode;
					if (!cwMode)
						{
						transmitter_on =  false;
						enableTX(transmitter_on, NORMAL_AUDIO);
						}
					break;

				case 'D':
				case 'd':
					setDACVol(getDACVol() + (isupper(c) ? 1 : -1));
					volume_changed = true;
					break;

				case 'f':
				case 'F':
					digitalMode = ! digitalMode;
					if (!digitalMode)
						{
						transmitter_on =  false;
						enableTX(transmitter_on, NORMAL_AUDIO);
						}
					enableAGC(digitalMode == false);
					break;

				case 'G':
				case 'g':
					if (!transmitter_on)
						{
						setAGCLevel(getAGCLevel() + (isupper(c) ? 1 : -1));
						volume_changed = true;
						}
					break;

				case 'H':
				case 'h':
					if (!transmitter_on)
						{
						setHpVol(getHpVol() + (isupper(c) ? 1 : -1));
						volume_changed = true;
						}
					break;

				case 'L':
				case 'l':
					if (!transmitter_on)
						{
						setLoVol(getLoVol() + (isupper(c) ? 1 : -1));
						volume_changed = true;
						}
					break;

				case 'M':
				case 'm':
					setMicVol(getMicVol() + (isupper(c) ? 1 : -1));
					volume_changed = true;
					break;

				case 'q':
				case 'Q':
					enableTX(false, NORMAL_AUDIO);
					return true;
					break;

				case 'R':
				case 'r':
					transmitter_on =  false;
					enableTX(transmitter_on, NORMAL_AUDIO);
					break;


				case 'T':
				case 't':
					transmitter_on =  true;
					enableTX(transmitter_on, NORMAL_AUDIO);
					break;

				case '<':
				case '>':
					gLSBMode = (c == '<');
					swapPhaseVFO(gLSBMode);
					break;

				case KEY_RIGHT:
					if (weight > 0)
						{
						weight--;
						current_column = HZ_COLUMN - weight;
						}
					break;

				case KEY_LEFT:
					if (weight < (num_weights-1))
						{
						weight++;
						current_column = HZ_COLUMN - weight;
						}
					break;

				case KEY_UP:
					rx_freq += weights[weight];
					break;

				case KEY_DOWN:
					rx_freq -= weights[weight];
					break;

				default:
					break;		// no change
				}

			c = -1;

			//	limit frequency range entry then change frequency
			if (rx_freq < 3500000L) rx_freq = 3500000L;
			if (rx_freq > 32000000L) rx_freq = 32000000L;
			setVFO(rx_freq);
			checkLPF(rx_freq, false);

			//	update these display fields on all keystrokes
			move(TXRX_LINE,0);
			if (digitalMode)
				addstr(gLSBMode ? "LSBD: " : "USBD: ");
			else if (cwMode)
				addstr(gLSBMode ? "LSBC: " : "USBC: ");
			else
				addstr(gLSBMode ? "LSB:  " : "USB:  ");

			move(TXRX_LINE,5);
				addstr(transmitter_on ? "Transmit "
									  : "Receive              ");

			move(HZ_LINE,0);
				printw("VFO %8i", rx_freq
								+ (cwMode ? (gLSBMode ? -700 : 700) : 0) );

			move(HZ_LINE,current_column);
			refresh();
			}

		//	update these only if something audio related has changed
		if (volume_changed)
			{
    		move(GAIN_LINE,0);
    		printw("GAIN: [H]p%2.0f [L]o%2.0f [M]ic%2.0f [D]ac%2.0f [A]dc%2.0f a[G]c%2.0f",
					getHpVol(),getLoVol(),getMicVol(),getDACVol(),getADCVol(),getAGCLevel());
			volume_changed = false;

			move(HZ_LINE,current_column);
			refresh();
    		}

		if (!cwMode)	// need to minimize refresh calls to keep it responsive
			{
			//	if transmitting, need to check vswr here and display it
			if (transmitter_on)
				{
				static float pwr, lastpwr, lastswr;
				float swr = readVSWR(&pwr);
				if (pwr < .05) swr = 0;

				move(TXRX_LINE,5);
				addstr("Transmit ");
				move(TXRX_LINE,15);
				printw("%1.2fw %1.1f:1 ",(pwr+lastpwr)/2,(swr+lastswr)/2 );

				lastpwr = pwr;
				lastswr = swr;

				move(HZ_LINE,current_column);
				refresh();
				}
			else
				{
				move(TXRX_LINE,5);
				addstr( "Receive              ");
				move(TXRX_LINE,15);
				refresh();
				}

			//	ugly debugging method (but effective)
			//move(4,0); printw("%s",gAGCEnabled ? "AGC On ": "AGC Off");
			//move(0,0); printw("%s",digitalRead(GPIO_PTTIn) ? "*": " ");
			//move(1,0); printw("%s",digitalRead(GPIO_SKeyIn) ? "*": " ");
			//move(2,0); printw("%s",digitalRead(GPIO_RTS) ? "*": " ");

			move(HZ_LINE,current_column); // always leave at freq display
			}
		}
	return true;
}


/*
*****************************************************************************
*****************************************************************************
*	Main
*
*	Notes:
*		1. The VFO must be initialized before the codec - it provides MCLK.
*		2. The Codec must be initialized before the transceiver controls
*			since they call the codec to set up the startup audio mode
*		3. The VSWR module is not initialized in initonly mode.
*
*****************************************************************************
****************************************************************************/
int main(int argc, char * argv[])
{
bool initonly = (argc == 2) && (*(argv[1]) == '-') && (*(argv[1]+1) == 'i');
bool catMode =  (argc == 2) && (*(argv[1]) == '-') && (*(argv[1]+1) == 'c');
// forces full codec re-init (can cause bad sync between I2S and DMA)
bool forceinit = (argc == 2) && (*(argv[1]) == '-') && (*(argv[1]+1) == 'f');

//	the string argument is expected to be the program name
const char * exitmsgs[] =
{
"%s: Devices initialized!\n",
"%s: Unable to initialize codec\n",
"%s: Unable to initialize GPIO control\n",
"%s: Unable to initialize VFO\n",
"%s: Unable to force initialize codec\n"
};


	int exitcode = 0;
	long cfactor = getCalibrationFactorFromPath(argv[0]);

	if (!initVFO(cfactor, STARTFREQUENCY, SGTL5000_FREQ)) exitcode = 3;
	else if (forceinit)
		{
		if (!initCodecUNCONDITIONALLY()) exitcode = 4;
		else if (!initControl()) exitcode = 2;
		}
	else {
		if (!initCodec()) exitcode = 1;
		else if (!initControl()) exitcode = 2;
		}
	//	Note that there's no reason to set up the VSWR bridge if
	//	it's not going to be displayed by the loop.

	if (exitcode == 0)
		{
		checkLPF(STARTFREQUENCY, true);		//	force uncached frequency set
		initVSWR();					//	optional device - ignore errors

		if (!(initonly || forceinit))
			{
			if (catMode)
				{
				setRawConsole();
				atexit([]{ unsetRawConsole(); });
				fprintf(stderr,"Kenwood TS-480 cat command mode - Ctrl-C to exit\n");
				cat_interface();
				unsetRawConsole();
				}
			else
				{
				WINDOW * w = initscr();		// ncurses setup
				timeout(1);
				noecho();
				keypad(w,true);
				atexit([]{ endwin(); });
				vfo_interface();			//	loop processing input
				endwin();
				}
			}
		}

	if (initonly || forceinit || (exitcode != 0))
		fprintf(stderr, exitmsgs[exitcode], *argv);

	return exitcode;
}

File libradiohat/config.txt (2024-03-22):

# For more options and information see
# http://rpf.io/configtxt
# Some settings may impact device functionality. See link above for details

# uncomment if you get no picture on HDMI for a default "safe" mode
#hdmi_safe=1

# uncomment the following to adjust overscan. Use positive numbers if console
# goes off screen, and negative if there is too much border
#overscan_left=16
#overscan_right=16
#overscan_top=16
#overscan_bottom=16

# uncomment to force a console size. By default it will be display's size minus
# overscan.
#framebuffer_width=1280
#framebuffer_height=720

# uncomment if hdmi display is not detected and composite is being output
#hdmi_force_hotplug=1

# uncomment to force a specific HDMI mode (this will force VGA)
#hdmi_group=1
#hdmi_mode=1

# uncomment to force a HDMI mode rather than DVI. This can make audio work in
# DMT (computer monitor) modes
#hdmi_drive=2

# uncomment to increase signal to HDMI, if you have interference, blanking, or
# no display
#config_hdmi_boost=4

# uncomment for composite PAL
#sdtv_mode=2

#uncomment to overclock the arm. 700 MHz is the default.
#arm_freq=800

# Uncomment some or all of these to enable the optional hardware interfaces
dtparam=i2c_arm=on
#dtparam=i2s=on
#dtparam=spi=on

# Uncomment this to enable infrared communication.
#dtoverlay=gpio-ir,gpio_pin=17
#dtoverlay=gpio-ir-tx,gpio_pin=18

# Additional overlays and parameters are documented /boot/overlays/README

# Enable audio (loads snd_bcm2835)
dtparam=audio=on

# Automatically load overlays for detected cameras
camera_auto_detect=1

# Automatically load overlays for detected DSI displays
display_auto_detect=1

# Enable DRM VC4 V3D driver
dtoverlay=vc4-kms-v3d
max_framebuffers=2

# Run in 64-bit mode
arm_64bit=1

# Disable compensation for displays with overscan
disable_overscan=1

[cm4]
# Enable host mode on the 2711 built-in XHCI USB controller.
# This line should be removed if the legacy DWC2 controller is required
# (e.g. for USB device mode) or if USB support is not required.
otg_mode=1

[all]

[pi4]
# Run as fast as firmware / board allows
arm_boost=1

[all]

[all]
##RadioHat 1.0##
dtparam=i2s=on
dtoverlay=RadioHatCodec
gpio=22,23=op,dh

[all]

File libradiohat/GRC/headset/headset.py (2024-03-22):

#!/usr/bin/env python3
# -*- coding: utf-8 -*-

#
# SPDX-License-Identifier: GPL-3.0
#
# GNU Radio Python Flow Graph
# Title: Headset
# GNU Radio version: 3.8.2.0

from distutils.version import StrictVersion

if __name__ == '__main__':
    import ctypes
    import sys
    if sys.platform.startswith('linux'):
        try:
            x11 = ctypes.cdll.LoadLibrary('libX11.so')
            x11.XInitThreads()
        except:
            print("Warning: failed to XInitThreads()")

from PyQt5 import Qt
from gnuradio import qtgui
from gnuradio.filter import firdes
import sip
from gnuradio import analog
from gnuradio import audio
from gnuradio import blocks
from gnuradio import filter
from gnuradio import gr
import sys
import signal
from argparse import ArgumentParser
from gnuradio.eng_arg import eng_float, intx
from gnuradio import eng_notation
from gnuradio.qtgui import Range, RangeWidget
import MuteIfNotRX
import MuteIfNotSK
import MuteIfNotTX

from gnuradio import qtgui

class headset(gr.top_block, Qt.QWidget):

    def __init__(self):
        gr.top_block.__init__(self, "Headset")
        Qt.QWidget.__init__(self)
        self.setWindowTitle("Headset")
        qtgui.util.check_set_qss()
        try:
            self.setWindowIcon(Qt.QIcon.fromTheme('gnuradio-grc'))
        except:
            pass
        self.top_scroll_layout = Qt.QVBoxLayout()
        self.setLayout(self.top_scroll_layout)
        self.top_scroll = Qt.QScrollArea()
        self.top_scroll.setFrameStyle(Qt.QFrame.NoFrame)
        self.top_scroll_layout.addWidget(self.top_scroll)
        self.top_scroll.setWidgetResizable(True)
        self.top_widget = Qt.QWidget()
        self.top_scroll.setWidget(self.top_widget)
        self.top_layout = Qt.QVBoxLayout(self.top_widget)
        self.top_grid_layout = Qt.QGridLayout()
        self.top_layout.addLayout(self.top_grid_layout)

        self.settings = Qt.QSettings("GNU Radio", "headset")

        try:
            if StrictVersion(Qt.qVersion()) < StrictVersion("5.0.0"):
                self.restoreGeometry(self.settings.value("geometry").toByteArray())
            else:
                self.restoreGeometry(self.settings.value("geometry"))
        except:
            pass

        ##################################################
        # Variables
        ##################################################
        self.samp_rate = samp_rate = 48000
        self.agcGain = agcGain = 1
        self.Volume = Volume = 0.1
        self.ToneLevel = ToneLevel = 0.25
        self.ToneFreq = ToneFreq = 1000
        self.TXTone = TXTone = 0
        self.MuteMic = MuteMic = 0
        self.LPF = LPF = 50
        self.HPF = HPF = 2750

        ##################################################
        # Blocks
        ##################################################
        self.RXTXTabs = Qt.QTabWidget()
        self.RXTXTabs_widget_0 = Qt.QWidget()
        self.RXTXTabs_layout_0 = Qt.QBoxLayout(Qt.QBoxLayout.TopToBottom, self.RXTXTabs_widget_0)
        self.RXTXTabs_grid_layout_0 = Qt.QGridLayout()
        self.RXTXTabs_layout_0.addLayout(self.RXTXTabs_grid_layout_0)
        self.RXTXTabs.addTab(self.RXTXTabs_widget_0, 'Receiver')
        self.RXTXTabs_widget_1 = Qt.QWidget()
        self.RXTXTabs_layout_1 = Qt.QBoxLayout(Qt.QBoxLayout.TopToBottom, self.RXTXTabs_widget_1)
        self.RXTXTabs_grid_layout_1 = Qt.QGridLayout()
        self.RXTXTabs_layout_1.addLayout(self.RXTXTabs_grid_layout_1)
        self.RXTXTabs.addTab(self.RXTXTabs_widget_1, 'Transmitter')
        self.RXTXTabs_widget_2 = Qt.QWidget()
        self.RXTXTabs_layout_2 = Qt.QBoxLayout(Qt.QBoxLayout.TopToBottom, self.RXTXTabs_widget_2)
        self.RXTXTabs_grid_layout_2 = Qt.QGridLayout()
        self.RXTXTabs_layout_2.addLayout(self.RXTXTabs_grid_layout_2)
        self.RXTXTabs.addTab(self.RXTXTabs_widget_2, 'TX Tone')
        self.top_grid_layout.addWidget(self.RXTXTabs)
        self._agcGain_range = Range(0.03, 5, .01, 1, 5)
        self._agcGain_win = RangeWidget(self._agcGain_range, self.set_agcGain, 'Volume', "dial", float)
        self.RXTXTabs_grid_layout_0.addWidget(self._agcGain_win, 0, 1, 1, 1)
        for r in range(0, 1):
            self.RXTXTabs_grid_layout_0.setRowStretch(r, 1)
        for c in range(1, 2):
            self.RXTXTabs_grid_layout_0.setColumnStretch(c, 1)
        self._Volume_range = Range(0, 0.5, .01, 0.1, 0)
        self._Volume_win = RangeWidget(self._Volume_range, self.set_Volume, 'Gain', "dial", float)
        self.RXTXTabs_grid_layout_0.addWidget(self._Volume_win, 0, 0, 1, 1)
        for r in range(0, 1):
            self.RXTXTabs_grid_layout_0.setRowStretch(r, 1)
        for c in range(0, 1):
            self.RXTXTabs_grid_layout_0.setColumnStretch(c, 1)
        self._ToneLevel_range = Range(0, 1, .01, 0.25, 1)
        self._ToneLevel_win = RangeWidget(self._ToneLevel_range, self.set_ToneLevel, 'Tone Level', "counter", float)
        self.RXTXTabs_grid_layout_2.addWidget(self._ToneLevel_win, 0, 0, 1, 1)
        for r in range(0, 1):
            self.RXTXTabs_grid_layout_2.setRowStretch(r, 1)
        for c in range(0, 1):
            self.RXTXTabs_grid_layout_2.setColumnStretch(c, 1)
        self._ToneFreq_range = Range(10, 10000, 10, 1000, 1)
        self._ToneFreq_win = RangeWidget(self._ToneFreq_range, self.set_ToneFreq, 'Tone Freq', "counter", float)
        self.RXTXTabs_grid_layout_2.addWidget(self._ToneFreq_win, 0, 1, 1, 1)
        for r in range(0, 1):
            self.RXTXTabs_grid_layout_2.setRowStretch(r, 1)
        for c in range(1, 2):
            self.RXTXTabs_grid_layout_2.setColumnStretch(c, 1)
        _TXTone_check_box = Qt.QCheckBox('Tone to TX')
        self._TXTone_choices = {True: 1, False: 0}
        self._TXTone_choices_inv = dict((v,k) for k,v in self._TXTone_choices.items())
        self._TXTone_callback = lambda i: Qt.QMetaObject.invokeMethod(_TXTone_check_box, "setChecked", Qt.Q_ARG("bool", self._TXTone_choices_inv[i]))
        self._TXTone_callback(self.TXTone)
        _TXTone_check_box.stateChanged.connect(lambda i: self.set_TXTone(self._TXTone_choices[bool(i)]))
        self.RXTXTabs_grid_layout_2.addWidget(_TXTone_check_box, 0, 3, 1, 1)
        for r in range(0, 1):
            self.RXTXTabs_grid_layout_2.setRowStretch(r, 1)
        for c in range(3, 4):
            self.RXTXTabs_grid_layout_2.setColumnStretch(c, 1)
        _MuteMic_check_box = Qt.QCheckBox('Mute Mic')
        self._MuteMic_choices = {True: 1, False: 0}
        self._MuteMic_choices_inv = dict((v,k) for k,v in self._MuteMic_choices.items())
        self._MuteMic_callback = lambda i: Qt.QMetaObject.invokeMethod(_MuteMic_check_box, "setChecked", Qt.Q_ARG("bool", self._MuteMic_choices_inv[i]))
        self._MuteMic_callback(self.MuteMic)
        _MuteMic_check_box.stateChanged.connect(lambda i: self.set_MuteMic(self._MuteMic_choices[bool(i)]))
        self.RXTXTabs_grid_layout_1.addWidget(_MuteMic_check_box, 0, 2, 1, 1)
        for r in range(0, 1):
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

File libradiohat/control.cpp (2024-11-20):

/*
***************************************** March 20, 2024 at 7:09:52 AM CDT
*****************************************************************************
*
*	Band and mode switching control logic
*	
*	started by Mario Vano AE0GL, February 2022
*
*	To generate the old method of relay controls via Pi GPIO:
*		#define USE_ALL_GPIO
*
*	In any case, the Pi GPIOs reserved for tx and rx mixer controls
*	and keydown testing are used to simplify use with other programs.
*
*	In either case, I2C control is attempted as well.
*
*	The Codec module is also used to change audio routing as needed.
*
******************************************************************************
*****************************************************************************/
#include <stdlib.h>
#include <stdio.h>
#include <unistd.h>
#include <stdint.h>
#include <fcntl.h>
#include <sys/ioctl.h>
#include <sys/types.h>
#include <sys/stat.h>
#include <linux/i2c-dev.h>
#include <gpiod.h>

#include "control.h"
#include "codec.h"

void checkRelays(uint32_t frequency, bool nocache);	//	forward reference
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

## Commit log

2024-03-22 polarity bug on /tx and /rx
    [control.cpp]
2024-03-26 fab files added
    [ABM12W-25.0000MHZ-4-D1X-T3.stp, BOM Template.xlsx, BOM1_0.csv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]
2024-03-27 added QFP32 HW version
    [ABM12W-25.0000MHZ-4-D1X-T3.stp, BOM Template.xlsx, DS3231MZ_V+.stp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]
2024-03-28 FOOTPRINT ERROR WARNING
2024-05-02 LPF Board Initial Version
    Kicad Files as sent to Fab for the LPF. VSWR Bridge and T/R Relay designed for stacking with RadioHat2
    [ceramic_capacitors-2.csv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]
2024-05-05 Update vswr.cpp to fix turns ratio scaling bug
    The turns ratio coefficient was not being applied to the diode correction in the power calculations
    [vswr.cpp]
2024-05-05 Reference Transceiver updated
    Better picture of latest case refurbishment - shows wiring details
2024-05-06 more VSWR fixes
    Yes, it's confusing and messy, but now the algorithm agrees with those used by all my other VSWR implementations.
    [vswr.cpp]
2024-11-26 update quisk settings samples
2024-12-01 fix typo in tx filter block

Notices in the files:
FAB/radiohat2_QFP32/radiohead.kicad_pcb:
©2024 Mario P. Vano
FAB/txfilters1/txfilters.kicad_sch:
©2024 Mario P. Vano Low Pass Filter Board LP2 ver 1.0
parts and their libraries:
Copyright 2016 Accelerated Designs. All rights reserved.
